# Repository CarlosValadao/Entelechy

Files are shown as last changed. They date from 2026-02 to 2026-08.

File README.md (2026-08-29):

# 🚀 Entelechy Project

https://github.com/user-attachments/assets/394cbacd-c1a7-4c5a-b76d-4e919793d7d3

O **Entelechy** é uma placa de propósito geral baseado na arquitetura **8051**.
Este projeto faz parte do meu portfólio de desenvolvimento em **Engenharia de Computação na UEFS** e minha trajetória na residência tecnológica do **CEPEDI**.

## 🛠️ Especificações de Hardware

### **Núcleo de Processamento**
* **MCU:** Atmel AT89S51 (Arquitetura 8051).
* **Interface de Programação:** Conector **ISP Prog** dedicado para gravação em circuito.

### **Sensores e Atuadores**
* **Display:** LCD 16x2 com interface **I2C** para visualização de dados em tempo real.
* **Temperatura/Humidade:** Sensor **DHT22** para medições de temperatura e umidade relativa.
* **Indicadores Visuais:** * LED **RGB** (Azul) e LEDS comuns (Laranja).
* **Feedback Sonoro:** Buzzer passivo para alertas via PWM.
* **HMI:** 4 Push-buttons e 8 Slide Switches.

### **Gerenciamento de Energia**
* **Proteção:** Circuito integrado contra **inversão de polaridade**.
* **Regulação:** Reguladores de tensão onboard com dissipadores para estabilidade térmica.

## Firmware

O firmware é um código de exemplo que demonstra o pleno funcionamento da placa

## 🎨 Design e Licença
* **Ferramenta:** KiCad
* **Dimensões:** 150 mm x 150 mm.
* **Licença:** CERN Open Hardware Licence Version 2 - Permissive (CERN-OHL-P).

---

## 👨‍💻 Autor
**Carlos Henrique de Oliveira Valadão**
* Graduando em Engenharia de Computação - **UEFS**.
* Residente em Sistemas Embarcados - **CEPEDI**.
* [LinkedIn](https://www.linkedin.com/in/carlos-valadao-3b81531bb/) | [GitHub](https://github.com/carlosvaladao)

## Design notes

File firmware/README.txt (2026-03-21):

                                Example
-----------------------------------------------------------------------------------
"C:\Users\baps\AppData\Local\Arduino15\packages\arduino\tools\avrdude\6.3.0-arduino17\bin\avrdude.exe" -C C:/AVR8051.conf -c stk500v1 -P COM61-p 89s52-b 19200 -U flash:w: "C:\Users\baps\OneDrive\Documents\8051\Keil 8051 Projects\LED\Objects\Single LED.hex":a

"C:\Users\baps\AppData\Local\Arduino15\packages\arduino\tools\avrdude\6.3.0-arduino17\bin\avrdude.exe" -C C:/AVR8051.conf -c stk500v1 -P COM6p 89s52-b 19200 -U flash:w: "C:\Users\baps\OneDrive\Desktop\Objects \testled.hex": a

-----------------------------------------------------------------------------------

-----------------------------------------------------------------------------------

"C:\Users\chval\AppData\Local\Arduino15\packages\arduino\tools\avrdude\6.3.0-arduino17\bin\avrdude.exe" -C C:/AVR8051.conf -c stk500v1 -P COM6 -p 89s51 -b 19200 -U flash:w:"C:\Users\baps\OneDrive\Documents\8051\Keil 8051 Projects\LED\Objects\Single LED.hex":a

"C:\Users\chval\AppData\Local\Arduino15\packages\arduino\tools\avrdude\8.0.0-arduino1\bin\avrdude.exe" -C C:/AVR8051.conf -c stk500v1 -P COM6 -p 89s51 -b 19200 -U flash:w:"C:\Users\chval\OneDrive\Desktop\uVision5 Projects\First Project\first-project.hex":a

C:\Users\chval\OneDrive\Desktop\uVision5 Projects\First Project

avrdude -C C:/AVR8051.conf -c stk500v1 -P COM9 -p 89s51 -b 19200 -U flash:w:"C:\Users\chval\OneDrive\Desktop\uVision5 Projects\First Project\Objects\first-project.hex":a

Criar os arquivos de cabeçalho para o DHT11 (AM23x) e para o 595 (SN74HC595)

-----------------------------------------------------------------------------------
Note: It support only AT89S51 and AT89S52.

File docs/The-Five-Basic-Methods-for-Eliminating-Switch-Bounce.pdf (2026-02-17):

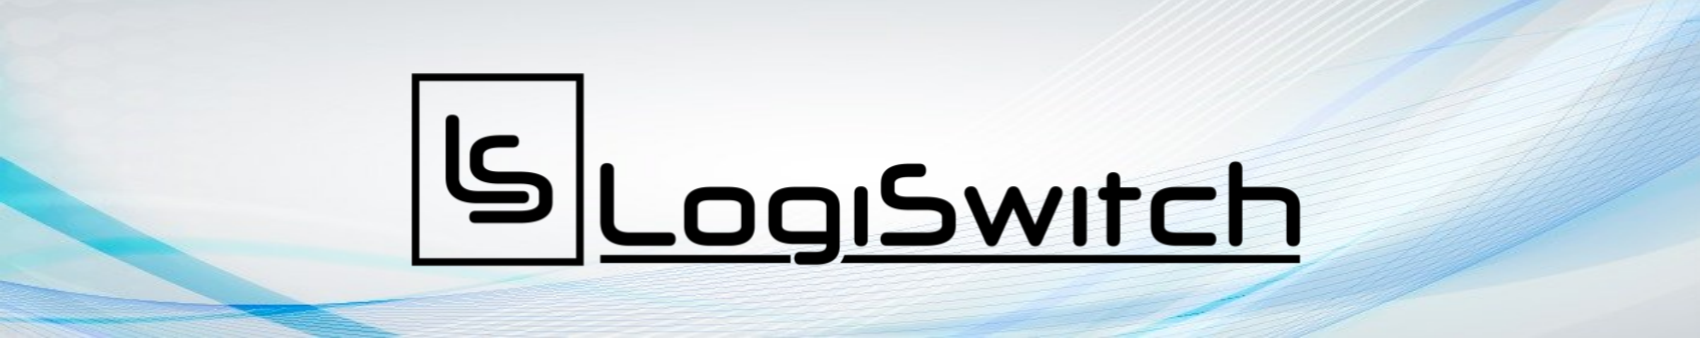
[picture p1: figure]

www.logiswitch.com | info@logiswitch.com | Sept 2020

# The Five Basic Methods for Eliminating Switch Bounce

By Michael H. Pelkey, Founder & CEO, LogiSwitch LLC

## Overview

This tutorial is to demonstrate all five methods for debouncing switches using single pole-single

throw, or single pole-double throw switches. The guide includes the two methods for single pole-

double throw (SPDT) switches which require no output delay and the two best methods for

interfacing with the simpler single pole-single throw (SPST) switches.

## What is Switch Bounce

The electric "snap switch" consists of one or two stationary electrodes called "Throws", and a

movable electrode, called a "Pole". When the switch is activated, the movable pole is forcefully

snapped onto the fixed surface of the stationary throw. Like snapping a rubber ball onto the

floor, it naturally bounces. The greater the force of the snap, the greater the bounce.

Unfortunately, the spring in the switch that provides the "snap" action through mechanical

hysteresis also adds to the force of the contacts coming together. If the switch is used to turn on

and off electric lights or to start a motor at 50 or 60 Hertz, the bounce is not noticeable and

causes no problems.

Unfortunately, such is not the case with high-speed, low current DC applications such as

microprocessor and microcontroller-based digital applications. Switch bounce is an inherent

characteristic of the electric switch, and almost always causes problems that must be dealt with

by the digital circuit designer. To make life easier for electronics design engineers and

2 | info@logiswitch.com | www.logiswitch.com

hobbyists, LogiSwitch manufactures switches and NoBounce+ ICs incorporating integral

debounce circuitry. It is the stated position of LogiSwitch that it is time for the field of digital

electronics to have their own switches that work for them rather than to continue borrowing from

the field for which they were originally designed that requires way too much extra effort just to

make them usable. LogiSwitch switches are made for high-speed digital applications.

## History of the Legacy Switch

Since the advent of the microprocessor and microcontrollers the propensity of the mechanical

switch to "bounce" has proved to be a design problem for hardware and/or software designers

that nearly always must be dealt with.

The Electric Snap Switch was designed and patented in 1884 by J. H. Holmes to ease the

arcing and burning of contacts for Thomas Edison's new invention of five years earlier, the

incandescent light bulb. It has been with us for the past 134 years, and still does a great job

when used for the purpose for which it was originally intended: high-voltage, high-current 50 and

60 Hertz AC applications.

## Debounce Tutorial

This tutorial demonstrates all five methods for debouncing switches, using single pole-single

throw, or single pole-double throw switches. The guide includes the two methods for single pole-

double throw (SPDT) switches which require no output delay:

1. The 2-Pin Debounce. This is the simplest method, but it requires two processor pins.
2. The Cross-coupled Nand or S/R Debounce. This method is functionally equivalent to

the 2-Pin method, but it uses only one processor pin.

and the two best methods for interfacing with the simpler single pole-single throw (SPST)

switches. Note that a delayed output is needed for the SPST switch:

1. Hardware SPST Debounce.
2. Software SPST Debounce.

Note that both the hardware and the software methods for debouncing the SPST switch simply

delay the switch output until after the bounce time has ended.

## Method 1. Simple Two-Pin Debounce

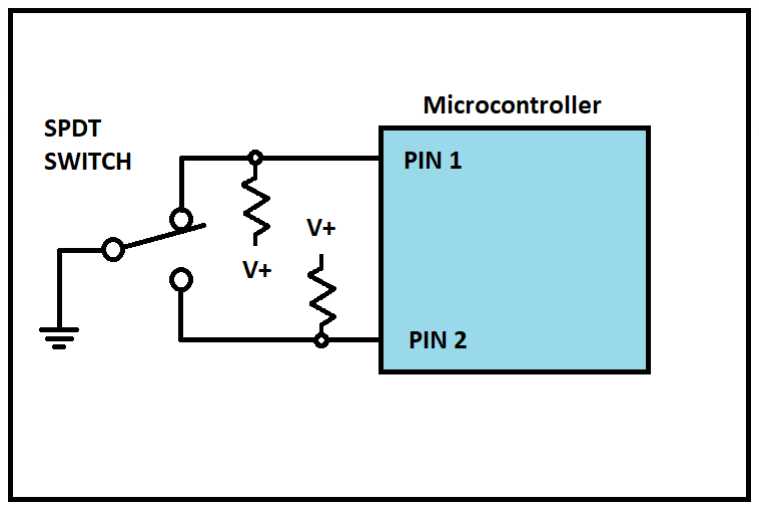
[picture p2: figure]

If you can spare two pins, this is the way to go. Using a SPDT switch, Pin 1 Low indicates the

switch is deactivated, and Pin 2 Low indicates it is activated. In other words, Switch Closure is

determined by finding Pin 2 low, and Switch Release is determined by finding Pin 1 low.

This rarely used, but highly effective debounce method performs every bit as well as the best

cross-coupled NAND circuit when two pins are available for use with a single switch. Note that

most microcontrollers provide programmable internal pull-up resistors for pins parameterized as

inputs, in which case the circuit may be even further simplified by omitting the two resistors

shown in the circuit drawing

## Method 2: Cross-Coupled NAND Debounce

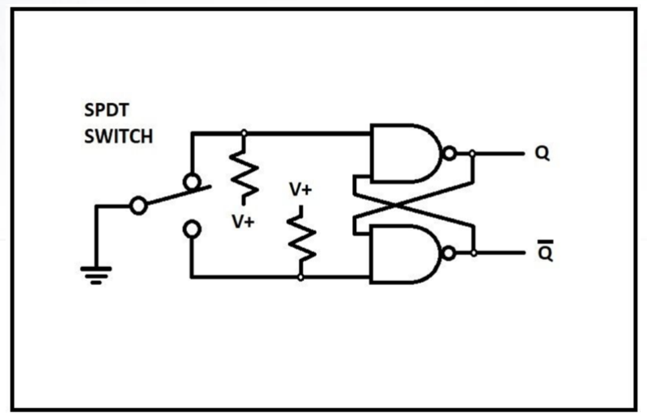
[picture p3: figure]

The cross-coupled NAND gate method is ideal for projects where two processor pins are not

available for use with one switch.

Output Q is high when the switch is idle, and low when it is activated. The /Q output is the

opposite: low when idle and high when activated. Note that only Methods 1, Two-Pin Debounce,

Method 2, Cross-coupled Nand Debounce or Method 3, D-Type Flip Flop Debounce provide

immediate outputs with no delay on activation and release (see Waveform 1).

For some industrial automation and robotics applications, the immediate attention of signaling

from these debounce methods is needed.

Note that the LogiSwitch integral debounce switches or LS100 series debouncer ICs incorporate

a circuit like the circuitry of Method 2.

## Method 3: D-Type Flip-Flop Debounce

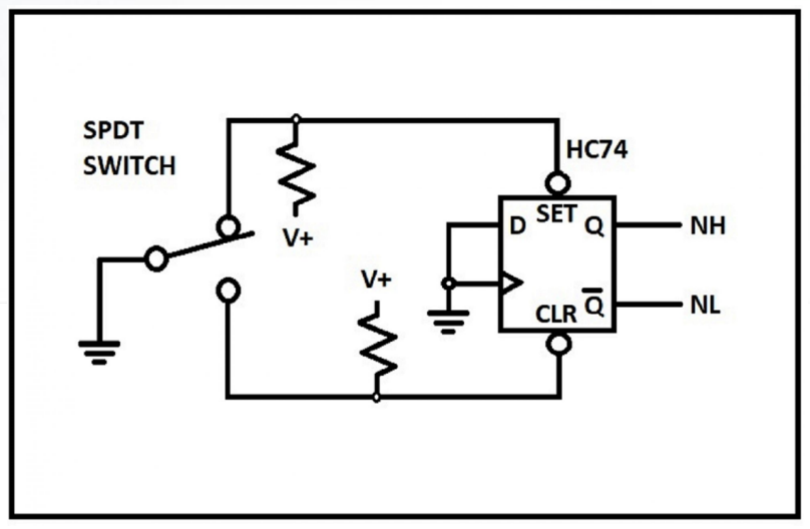
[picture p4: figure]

Using the internal cross-coupled NAND gating of a D-Type Flip flop provides an excellent

Method 3 Debounce. Note the Q output is normally high and goes low when the switch is

activated.

## Method 4: Hardware Debounce for SPST Switches

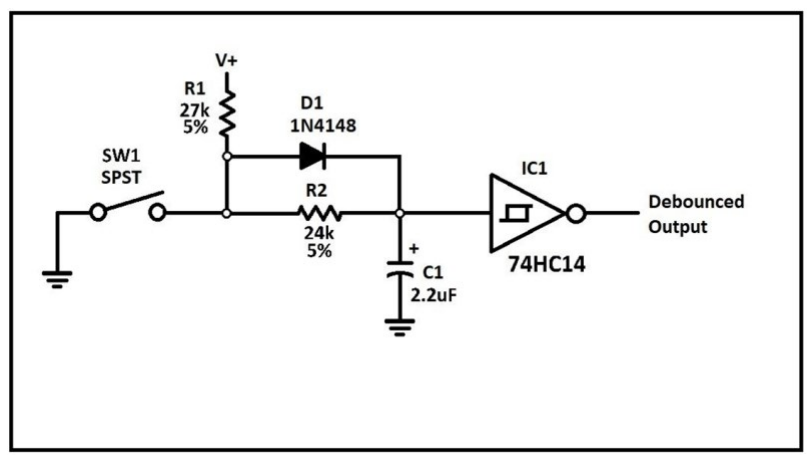
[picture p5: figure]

Whenever a single pole-single throw (SPST) switch is used for input into high-speed digital

devices, the only thing you can do is to wait out the bounce interval with either hardware or

software delays (see Waveform 2). The individual application dictates the usefulness of this

debounce method. Most applications can handle delays of up to 100 ms with a barely noticeable

delay. Method 4 is the hardware implementation for single poll-single throw switches.

This circuit charges the capacitor C1 through Resistor R1 and Diode D1 when the switch is

released and discharges it through Resistor R2 when it is activated. The 74HC14 Schmitt trigger

provides the needed hysteresis for a snap-action output when the slow ramp of the RC circuit

rises and falls. Hysteresis assures a single transition with no oscillation when the switch is

activated or released.

NOTE: The values shown in the drawing provide delays of approximately 36 ms on activation

and release with a 5 Volt supply. The resistance of R1 and R2 may be raised or lowered for

longer or shorter delay times.

Using a 2.2 µF Capacitor for C1, a very simple way to calculate the delay time for the circuit

shown is R1 = T * 750, and R2 = R1 * 0.9

where T is the desired delay time in milliseconds, and R1 & R2 are resistance in ohms:

For 100 ms delay:

R1 = 100 * 750 | R1 = 75,000 ohms
R2 = R1 * 0.9 | R2 = 75,000 * 0.9 | R2 = 67,500 ohms
R1 = 20 * 750 | R1 = 15,000 ohms
R2 = R1 * 0.9 | R2 = 15,000 * 0.9 | R2 = 13,500 ohms

For 20ms delay:

## Method 5: Software Delay Debounce

There are numerous examples online for software debounce routines for every computer

language known to mankind. They all amount to simply waiting out the estimated bounce period.

For Switch Activated:

1. Loop until switch activated.
2. Delay 20 ms to 100 ms.
3. Retest to be sure it is still activated. (If not, go to 1)
4. Continue with the program. Switch is activated.

For Switch Released:

1. Loop until switch released.
2. Delay 20 ms to 100 ms.
3. Retest to be sure it is still released. (If not, go to 1)
4. Continue with the program. Switch is released.

You must provide a longer delay period than any switch you use will ever bounce. Contact

bounce time varies among switch types and even among switches of the same type and

models. Delay time also is said to change over time with the same switch. Typical delay times

used are 20 ms to 100 ms, even when the actual bounce time may be as little as a few

milliseconds.

For compute-bound applications where time is literally of the essence, such as in high-speed

automated industrial machinery or robotics applications, your choice of debounce method

should be Method 1: Two-Pin Debounce, or Method 2: Cross-Coupled Nand Debounce.

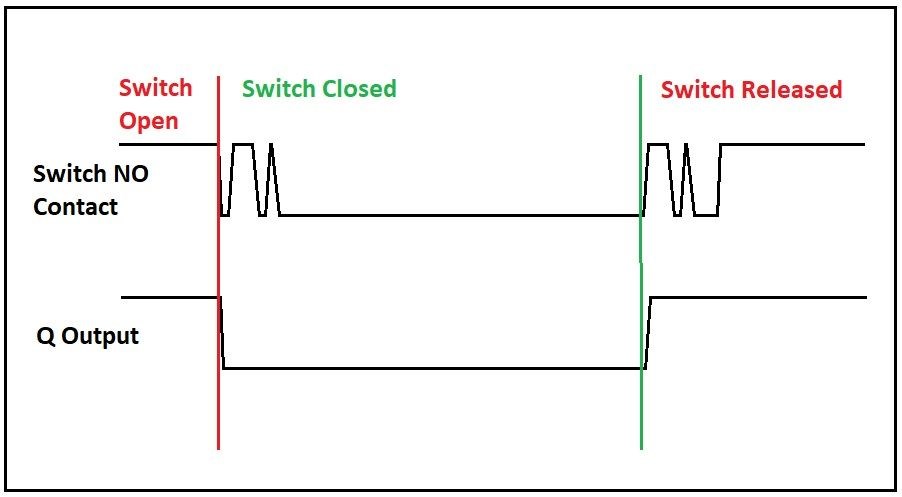
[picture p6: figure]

## Waveform 1. Cross-Coupled Nand and 2-Pin Debounce Methods

Note the immediate Q output. Methods 1 and 2 change the output state with no delay both on

actuation and release.

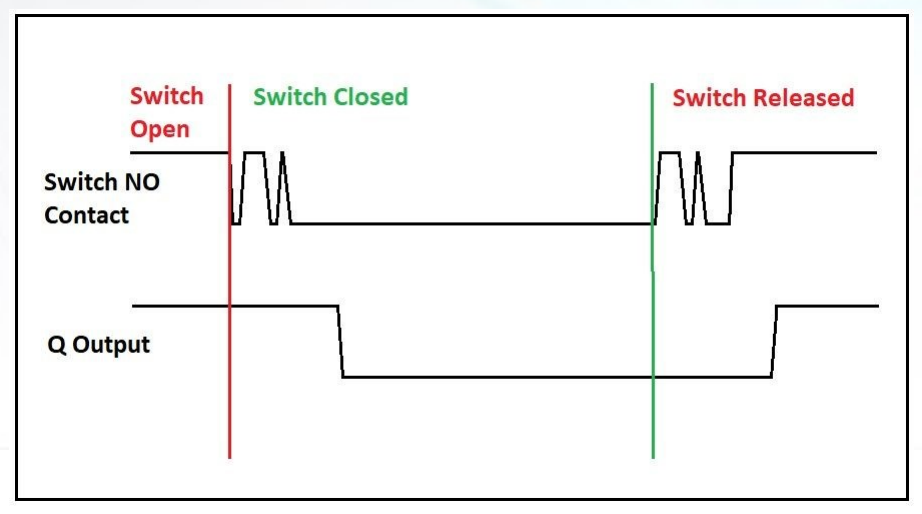
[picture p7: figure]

## Waveform 2. SPST and Software Delay Methods

Note the delayed Q output for these methods. The Hardware Debounce circuit of Method 3 and

Software Debounce of Method 4 require delaying action until the bounce time is through.

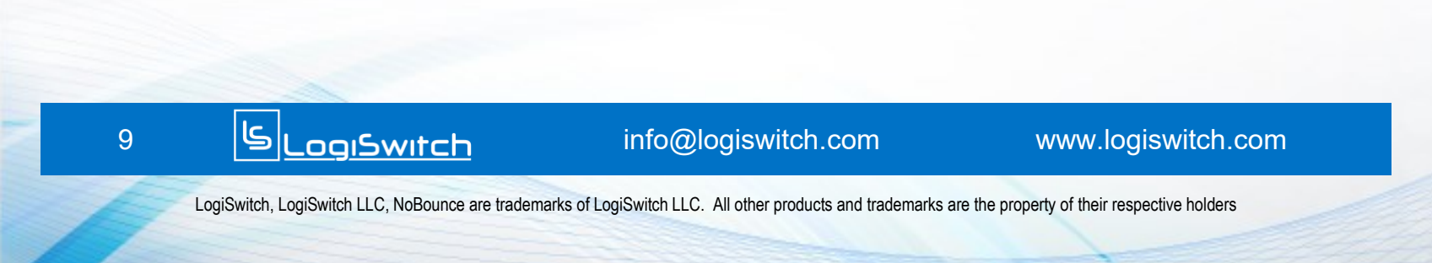
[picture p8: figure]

LogiSwitch, LogiSwitch LLC, NoBounce are trademarks of LogiSwitch LLC. All other products and trademarks are the property of their respective holders

About the Author

Michael H. Pelkey, Founder and CEO, LogiSwitch LLC

Mike is a serial inventor and serial entrepreneur who has a broad background in designing,

using, and manufacturing electronic systems and equipment. In his younger years, Mike

pioneered the sport of BASE Jumping. (https://en.wikipedia.org/wiki/Michael_Pelkey)

Prior to founding LogiSwitch, Mike was an Automation Engineer at Jaxx Manufacturing where

he designed and built assembly and metalworking machines to increase production rates, such

as automatic screwdrivers, optical cut to length machines, and a variety of machines, jigs and

fixtures to automate printed circuit assembly operations.

Mike’s 40+ year career goes back to the early days of the microprocessor where he was the

lead engineer for the first microprocessor-based product in the numerical control industry a Z-

axis controller called the Micro-Z. Mike also developed the world’s first networked cash register

in the mid-1970s, and he founded Macrotech International Corporation, which was a major

manufacturer of board-level computer products in the late-1970s and early-1980s.

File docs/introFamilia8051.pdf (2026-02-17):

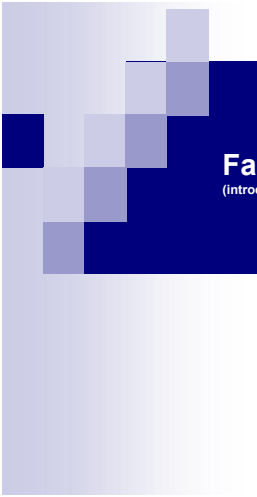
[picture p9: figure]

# Família 8051

(introdução)

2011/1

2

# Refresh

Microprocessador vs. microcontrolador. Periféricos built-in.

## Single-chip computer

3

# Objetivos

Histórico
Modelos da família original
Principais características
Diagrama em blocos simplificado
Configuração e descrição dos pinos (pinagem) Arquitetura
Multiplexação de dados e endereços
I/O mapeado em memória
Organização de memória
Timing
Interrupções
T/C e porta serial
Instruction set
Modelos atuais
Atividades

### Intrudução à família de microcontroladores 8051:

4

# Rápido histórico

Desenvolvido pela Intel
Nome oficial: MCS-51
Introduzida no final da década de 70/ início de 80.
Principal finalidade: automação e controle.

# Principais modelos da família original

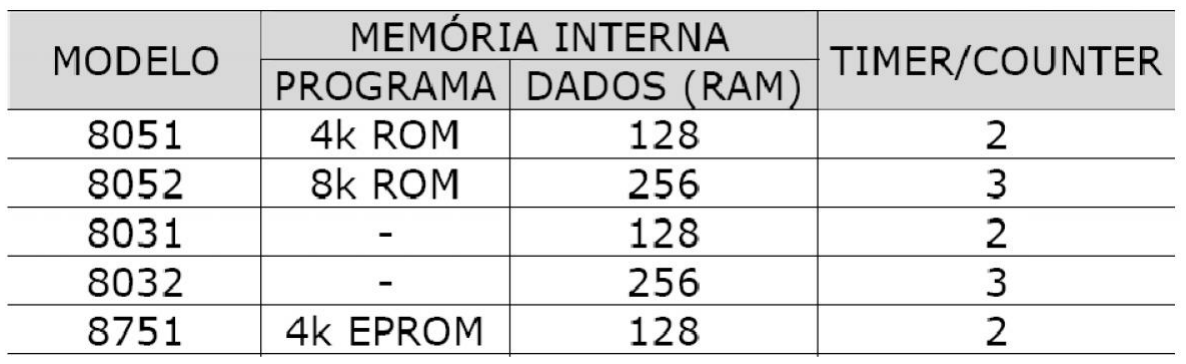
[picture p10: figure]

5

# Principais características do 8051

8 bits
4 ports bidirecionais de 8 bits (P0, P1, P2, P3)
128 bytes de RAM interna
4 Kbytes de memória de programa ROM OTP
Endereçamento de até 64 Kbytes de memória de dados externa
Endereçamento de até 64 Kbytes de memória de programa externa Oscilador de clock
2 timers/counters (T/C) de 16 bits
Uma porta serial USART
5 fontes de interrupção (2 externas, 2 T/C, 1 serial)

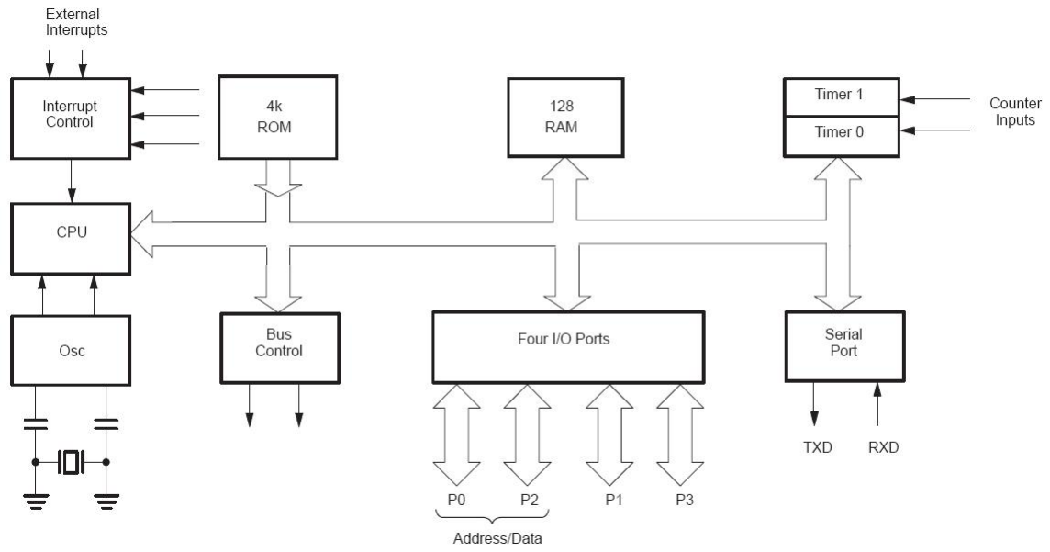
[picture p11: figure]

6

# Diagrama em blocos simplificado

# Configuração e descrição dos pinos

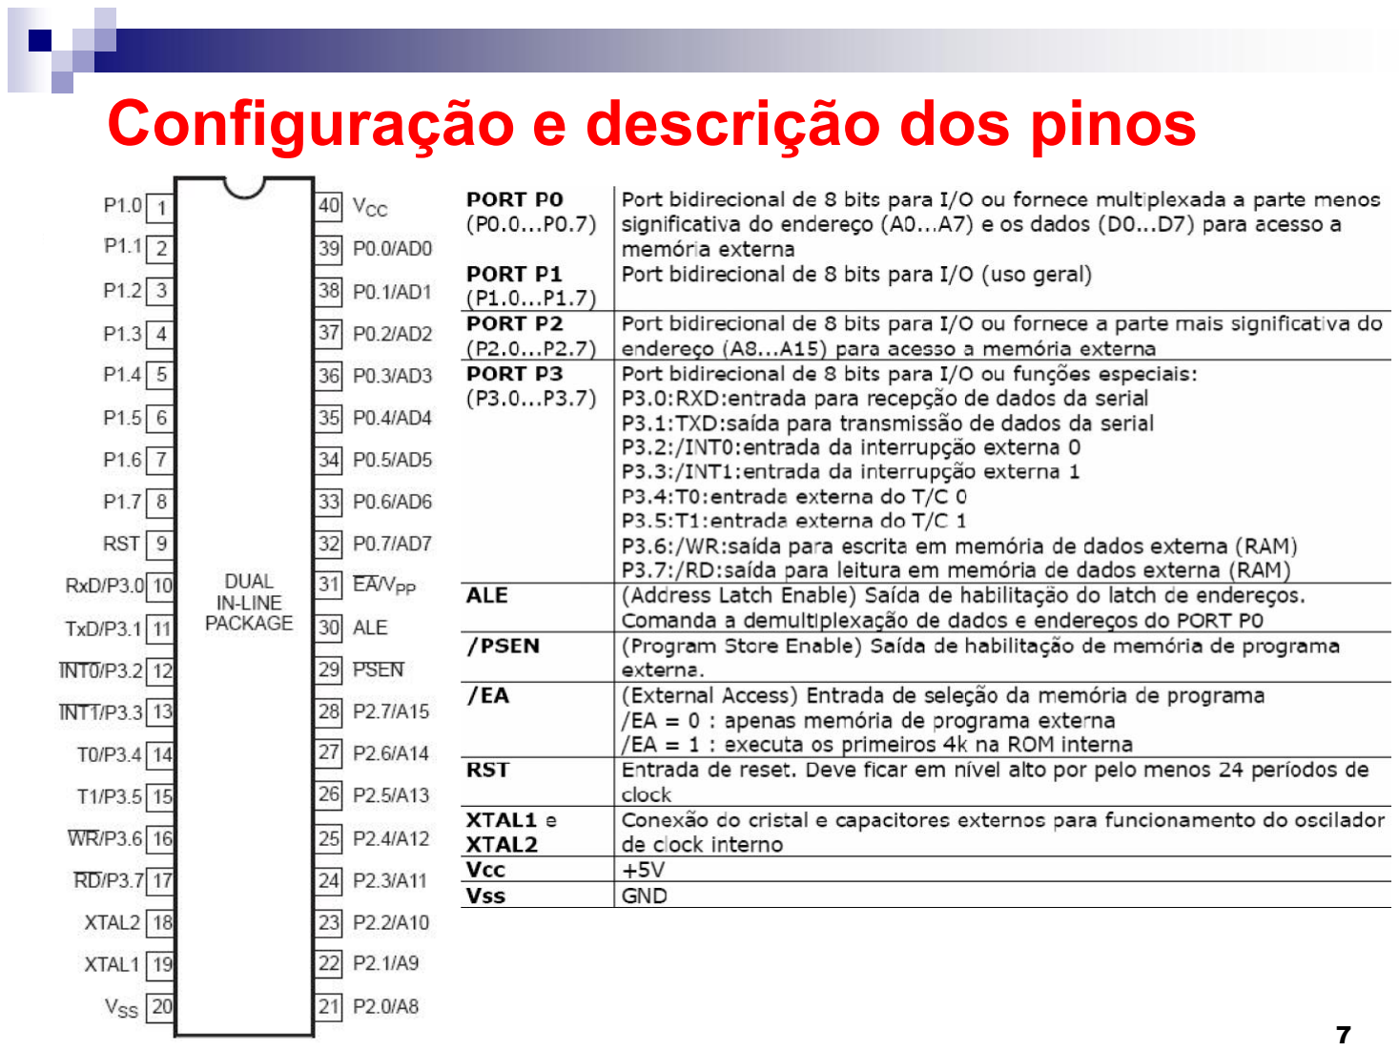
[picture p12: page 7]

7

## Arquitetura Multiplexação de dados e endereços

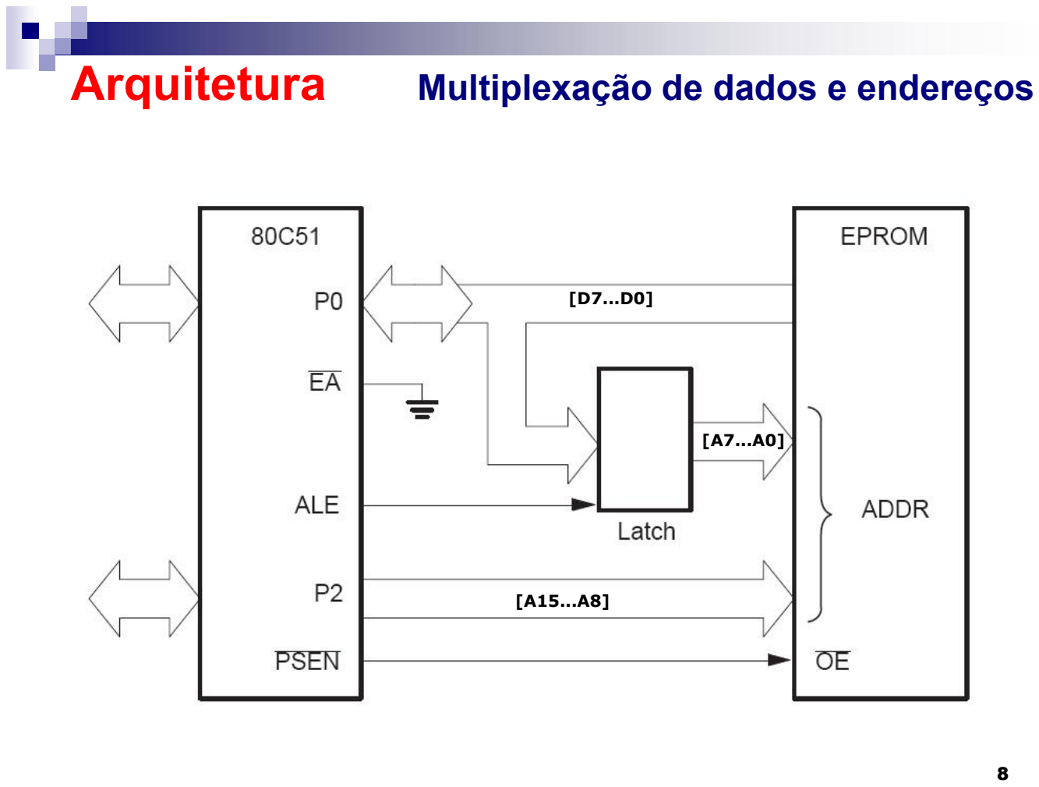
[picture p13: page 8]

8

[D7...D0]

[A15...A8]

[A7...A0]

## Arquitetura Multiplexação de dados e endereços

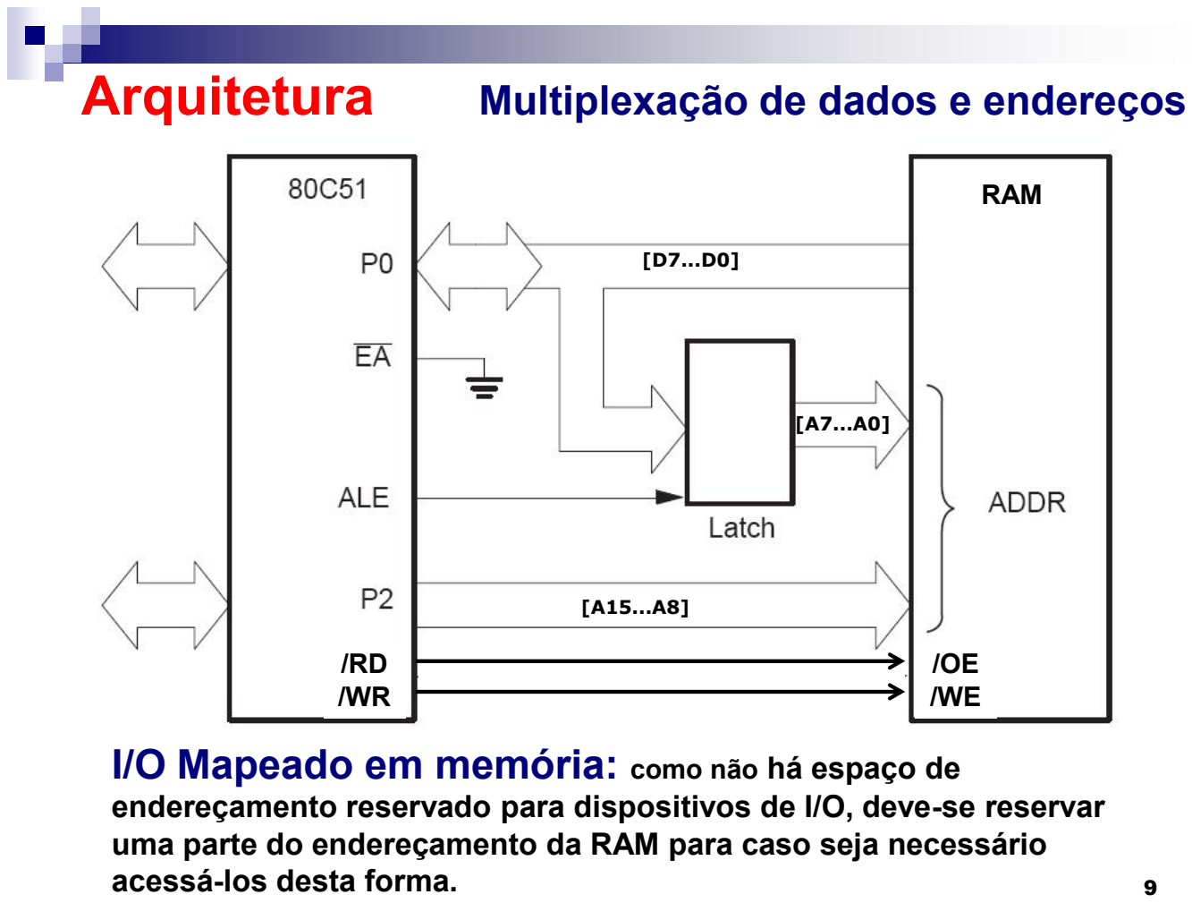
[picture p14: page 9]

9

RAM

/RD
/WR

/OE
/WE

## I/O Mapeado em memória: como não há espaço de

endereçamento reservado para dispositivos de I/O, deve-se reservar uma parte do endereçamento da RAM para caso seja necessário acessá-los desta forma.

[D7...D0]

[A15...A8]

[A7...A0]

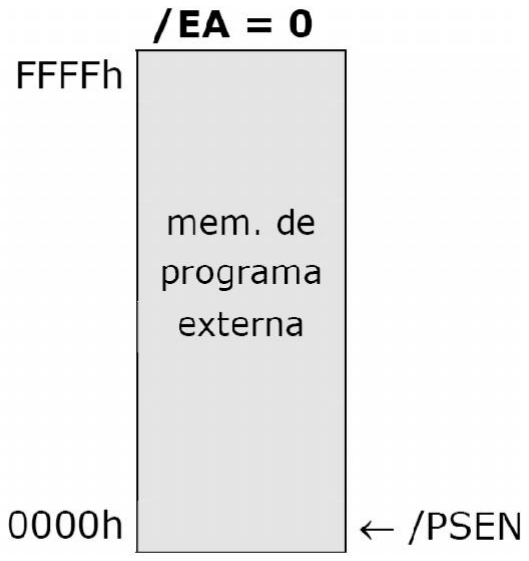
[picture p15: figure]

10

## Arquitetura Organização de memória

Memória de programa:

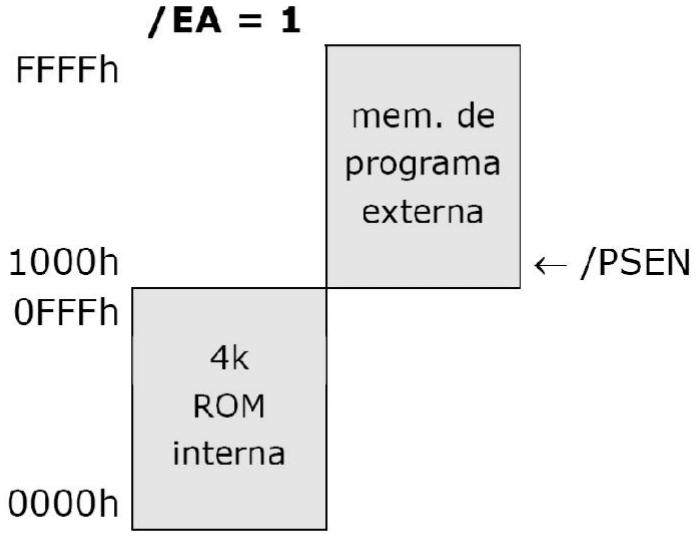
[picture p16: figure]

## Arquitetura Organização da memória

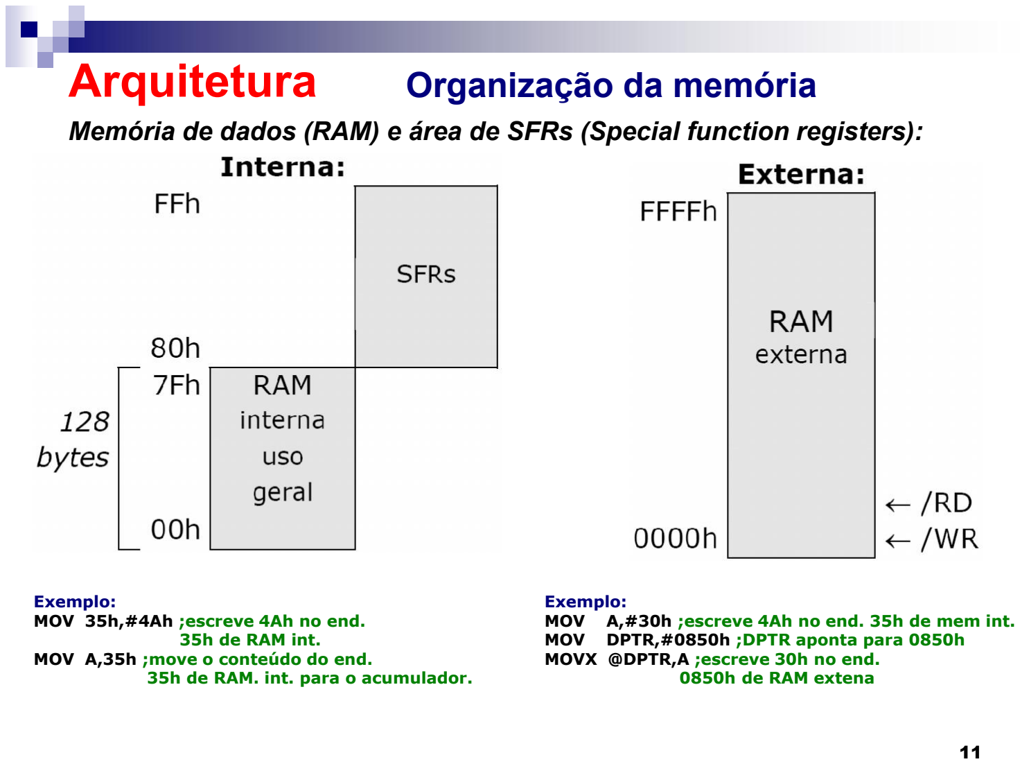
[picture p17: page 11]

11

Memória de dados (RAM) e área de SFRs (Special function registers):

Exemplo:
MOV 35h,#4Ah ;escreve 4Ah no end. 35h de RAM int.
MOV A,35h ;move o conteúdo do end. 35h de RAM. int. para o acumulador.

Exemplo:
MOV A,#30h ;escreve 4Ah no end. 35h de mem int. MOV DPTR,#0850h ;DPTR aponta para 0850h MOVX @DPTR,A ;escreve 30h no end.
0850h de RAM extena

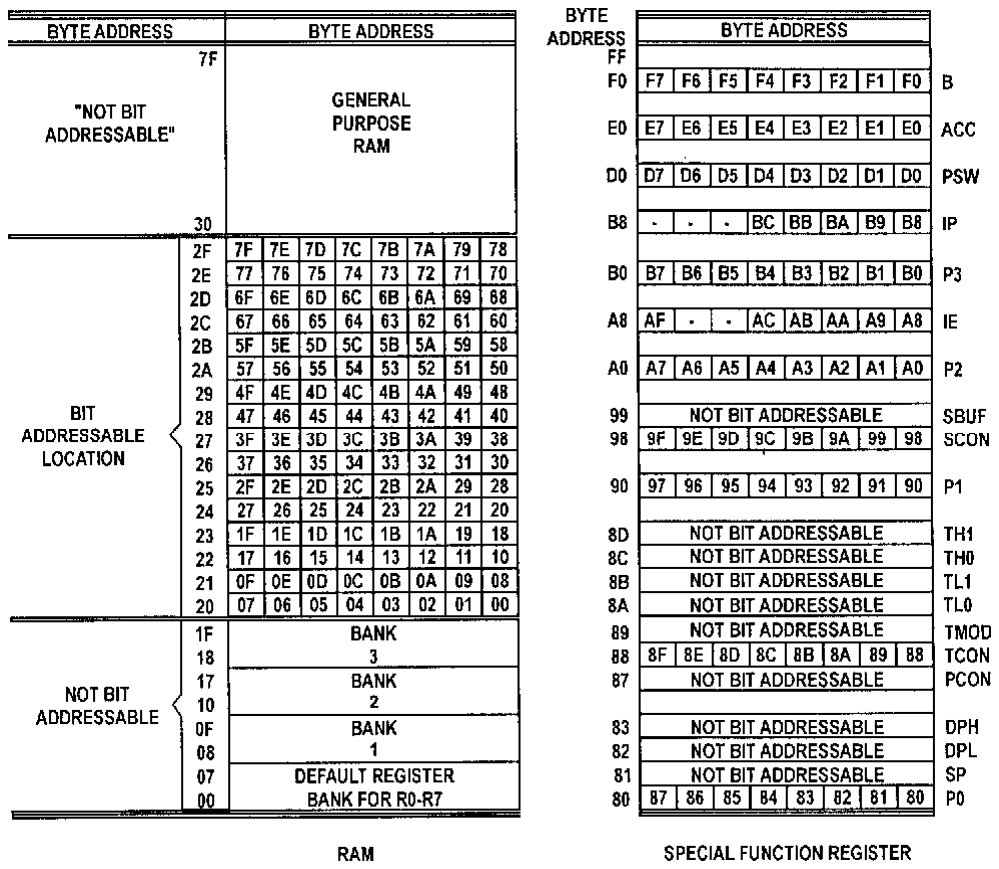
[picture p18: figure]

12

## Arquitetura Organização da memória

Memória de dados (RAM) e área de SFRs (Special function registers):

Microcontrolador
8051 Detalhado
Denys E. C. Nicolosi,
Editora Érica, 2a Ed.

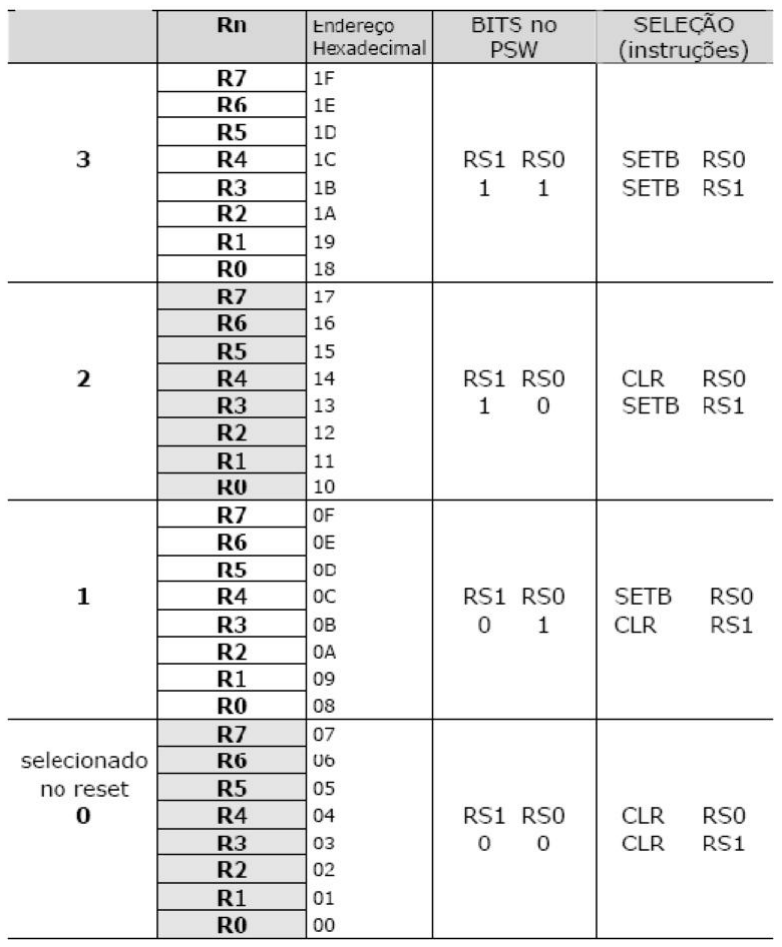
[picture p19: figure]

13

## Arquitetura Organização da memória

Bancos de registradores
- Situados nas posições
00h até 1Fh de RAM
Interna.
-A seleção do banco
(0,1,2,3) é feita através
Dos bits RS1 e RS0 do
SFR PSW:

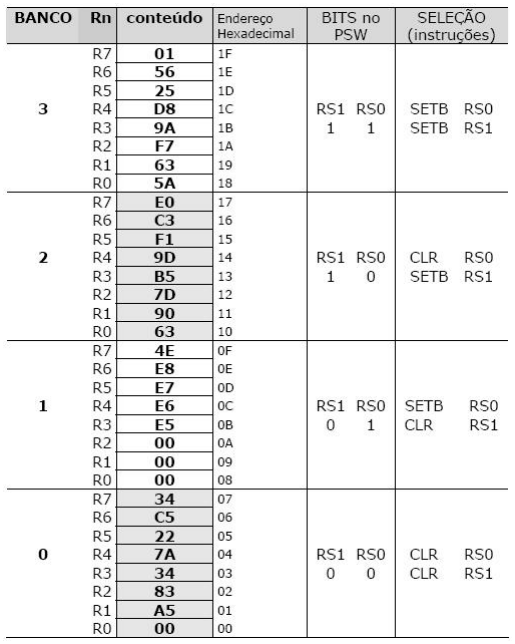
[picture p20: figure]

14

## Arquitetura Organização da memória

Bancos de registradores

Exemplo:
Após as instruções
CLR RS0
SETB RS1
MOV A,R5
Qual é o conteúdo de A ?

Resposta: A F1h

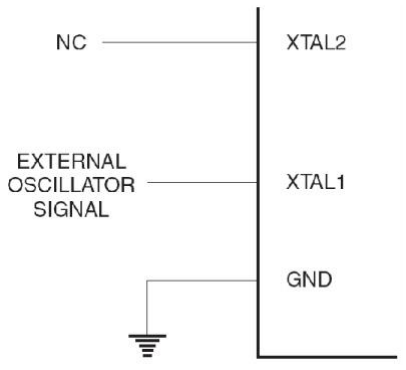
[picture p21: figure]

15

# Timing

Oscilador interno. Requisita a conexão de um cristal e capacitores. Também pode-se aplicar clock externo. Tipicamente:

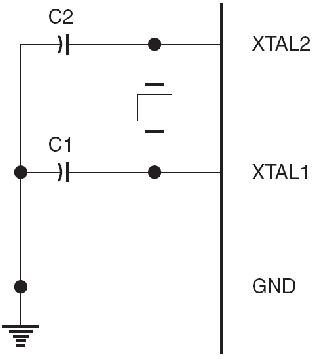
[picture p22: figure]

Ativo em nível lógico alto. Deve permanecer pelo menos 2 ciclos de

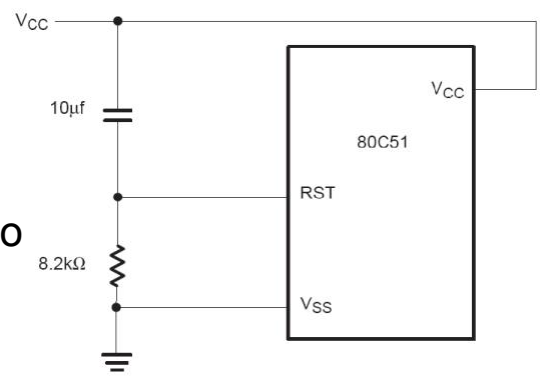
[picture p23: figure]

máquina ativo, permitindo a estabilização do oscilador interno. Tipicamente:

## Reset

## Clock

C1 = C2 33 pF
Cristal
11.059200 MHz

## Ciclos de máquina

Um ciclo de máquina consiste De 12 períodos de clock. As instruções requerem 1 ou 2 ciclos.

# Interrupções

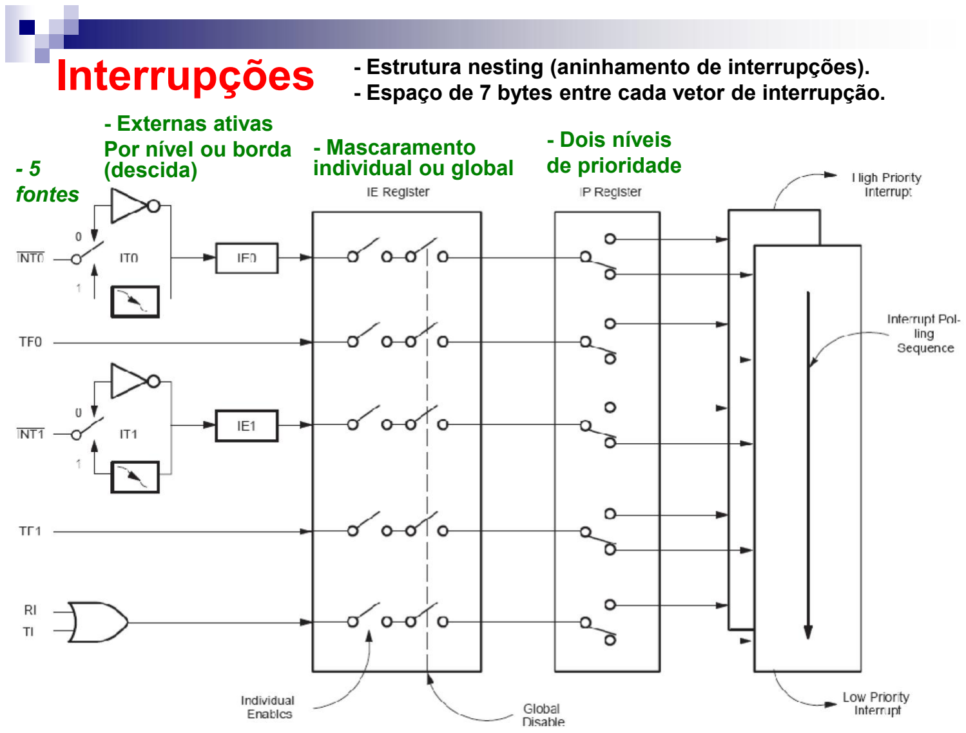
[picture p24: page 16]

16

- 5
fontes
- Mascaramento
individual ou global
- Externas ativas
Por nível ou borda
(descida)
- Dois níveis
de prioridade
- Estrutura nesting (aninhamento de interrupções).
- Espaço de 7 bytes entre cada vetor de interrupção.

17

# Timer/Counter (T/C)

2 T/C: T/C 0 e T/C 1.
A contagem acontece nos registradores TLx e THx.
Operação como timer: incremento em TLx/THx ocorre a uma frequencia de 1/12 da frequencia do clock.
Operação como counter: incremento em TLx/THx ocorre na borda de descida do pino Tx.
4 modos de operação:



18

# Porta serial

Pinos TXD e RXD.
Permite operação full-duplex e possui um buffer de recepção.
Transmissão e recepção dos dados acontecem no registrador SBUF: São dois buffers fisicamente independentes.
Escrita em SBUF: carrega os dados a serem transmitidos.
Leitura em SBUF: recebe os dados.
4 modos de operação:

19

# Instruction set

ISA (instruction set architecture) CISC.
Aproximadamente 100 instruções. Podem ser divididas nos cinco grupos descritos abaixo

### 2. Lógicas

Exemplos:
ANL
ORL
XRL
CPL
SWAP
RL
RR

### 1. Aritméticas

Exemplos:
ADD
INC
SUB
DIV
MUL

### 3. Transferência

de dados
Exemplos:
MOV
MOVC
MOVX
PUSH
POP

### 4. Salto e salto

incondicional
Exemplos:
AJMP
LJMP
SJMP
CJNE
DJNZ
NOP
JZ
JNZ

### 5. Manipulação

de variáveis
booleanas
(bit-level)
Exemplos:
CLR
SETB
CLP
ANL
ORL
MOV

20

# Modelos atuais

A Intel não produz mais a família 8051 original. Na linha de embarcados, dedica-se a dispositivos mais sofisticados.
O 8051 ainda é um dos cores de 8 bits mais populares do mercado. Há 8051 de todos os sabores e para todos os gostos !
Periféricos built-in.
Desempenho.
Encapsulamentos.
Consumo.
Tensão de operação.
Exemplos de fabricantes e respectivos destaques:
NXP (Philips) | grande variedade de periféricos built-in
Atmel | linha AT89S com memória de programa flash
Dallas (Maxim) | alto desempenho (até 50 MHz, 50 MIPS)
Infineon (Siemens) grande variedade de periféricos built-in
Texas Instruments aquisição de sinal
Cypress | controlador USB com 8051
Nuvoton | alto desempenho (2,5 x faster)

21

# Atividades

Procurar datasheets da 8051 family utilizando as seguintes palavras chave:
Family architecture
Hardware description
Programmers guide ou instruction set

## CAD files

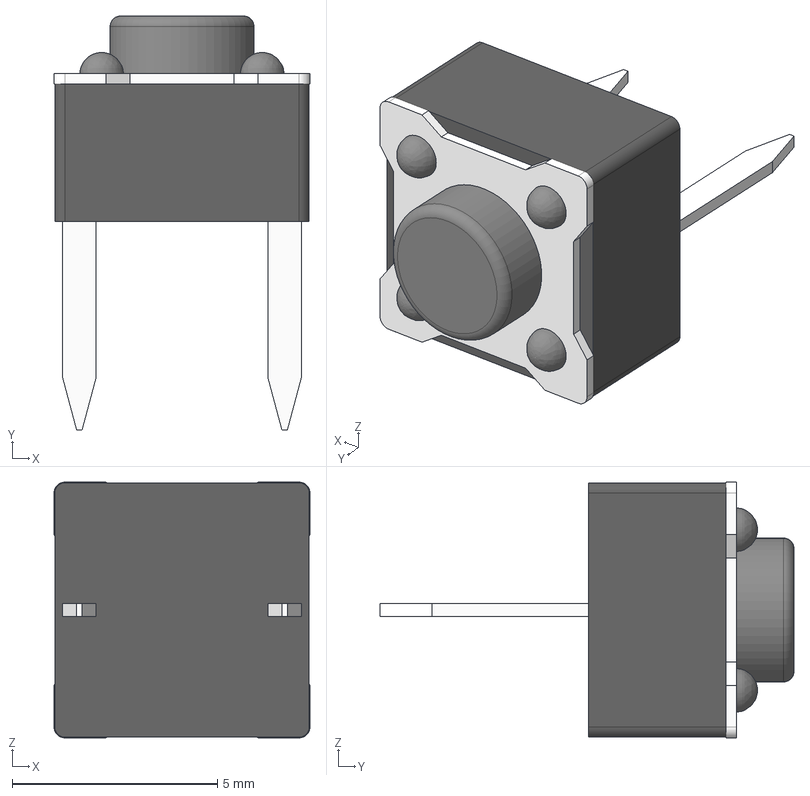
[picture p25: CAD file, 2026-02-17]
Entelechy/Entelechy_3D/Tactile Switches TH (6mm×6mm -2pin) Black.stp
6.23 x 10.1 x 6.23 mm

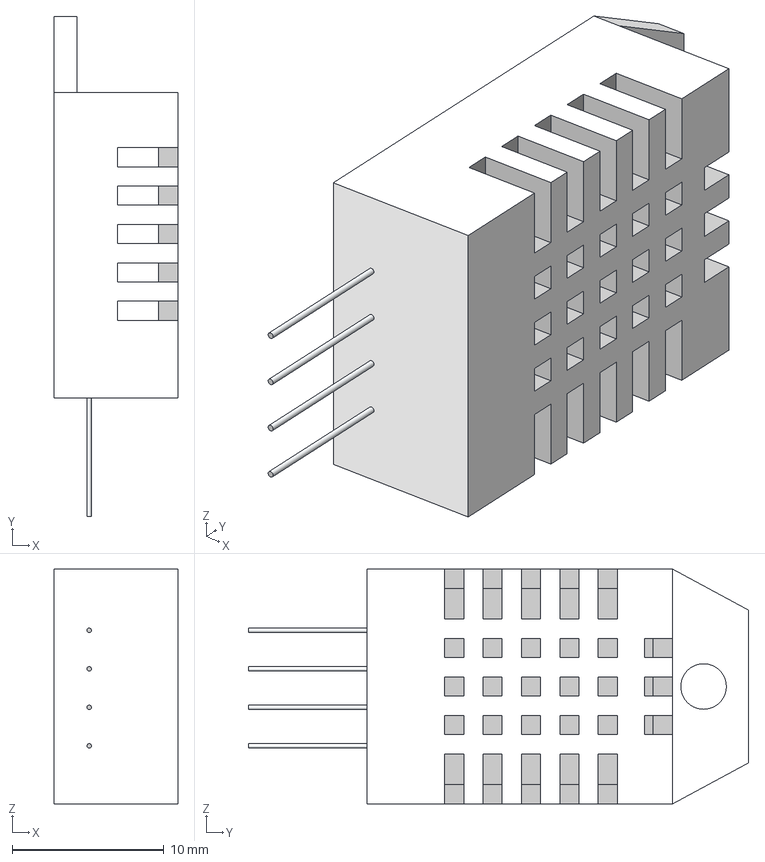
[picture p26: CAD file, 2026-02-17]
Entelechy/Entelechy_3D/DHT22 v1.step
8.15 x 33.0 x 15.5 mm

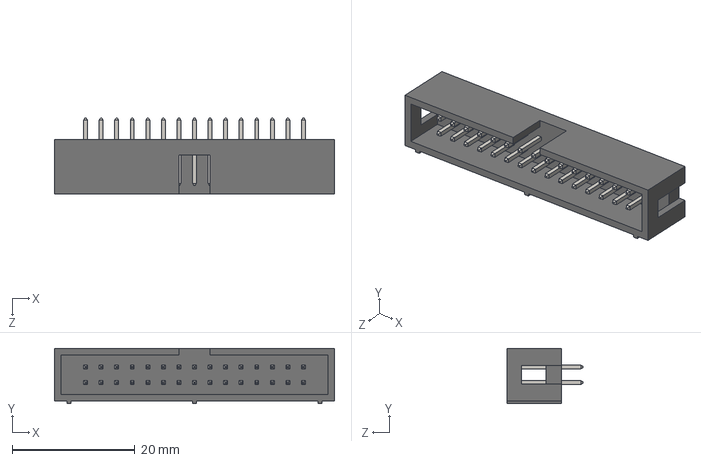
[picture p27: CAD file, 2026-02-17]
Entelechy/Entelechy_3D/BH-30.STEP
45.7 x 9.00 x 12.4 mm

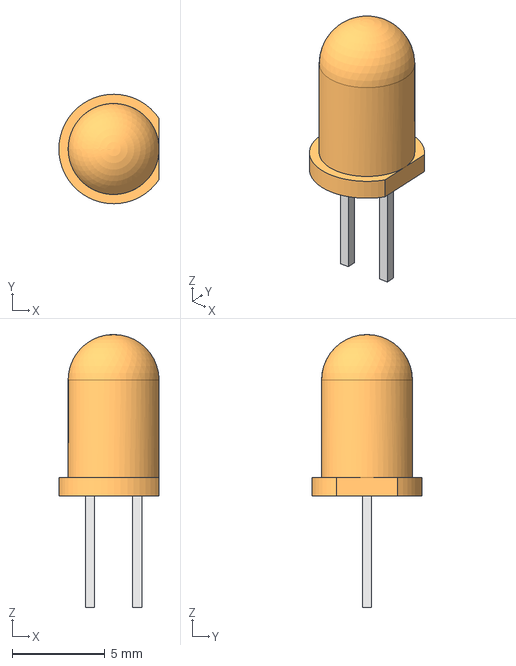
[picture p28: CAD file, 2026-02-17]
Entelechy/Entelechy_3D/LED_D5.0mm_ORANGE.step
5.40 x 5.90 x 14.7 mm

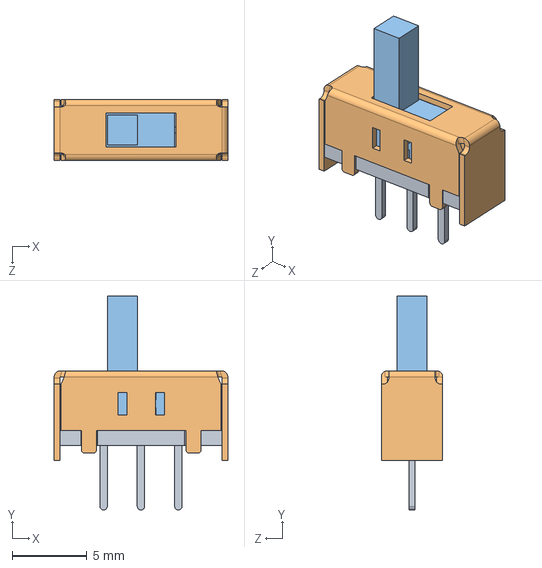
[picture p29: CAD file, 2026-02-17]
Entelechy/Entelechy_3D/SLW-116641-5A-S-D.step
11.6 x 14.3 x 4.10 mm

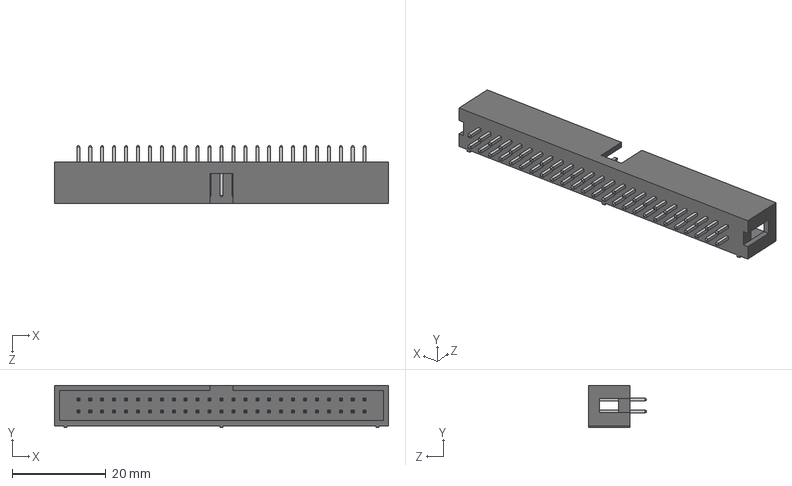
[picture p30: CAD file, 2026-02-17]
Entelechy/Entelechy_3D/BH-50.STEP
71.1 x 9.00 x 12.4 mm

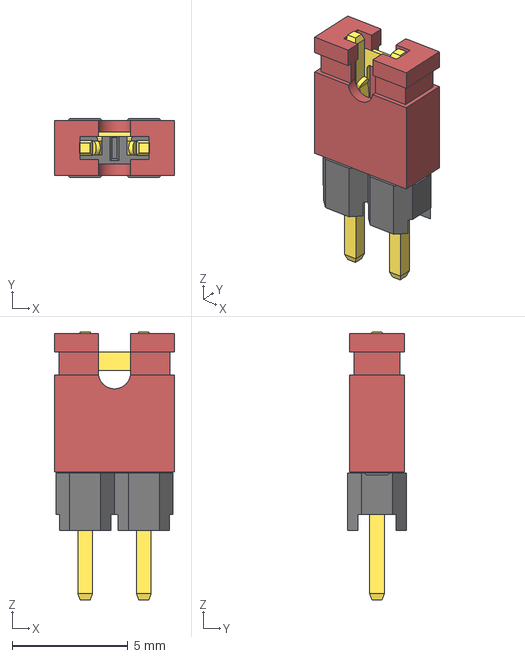
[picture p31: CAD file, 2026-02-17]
Entelechy/Entelechy_3D/Jumper2-red.step
5.20 x 2.54 x 11.6 mm

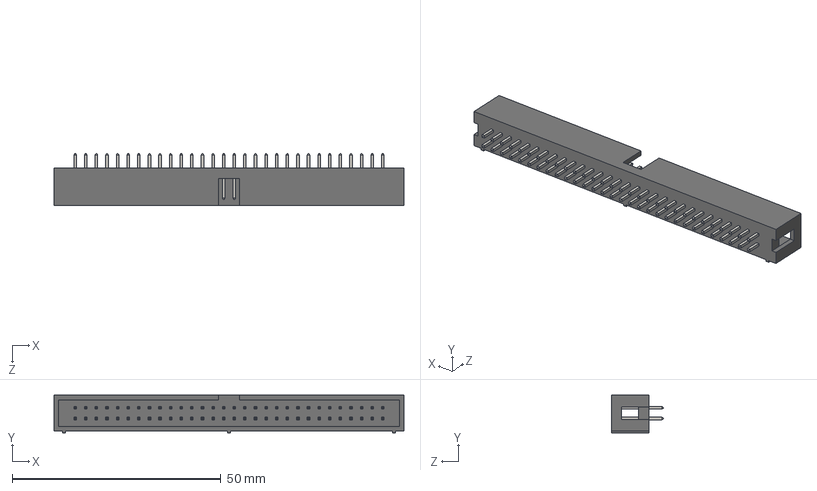
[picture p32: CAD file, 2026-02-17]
Entelechy/Entelechy_3D/BH-60.STEP
83.8 x 9.00 x 12.4 mm

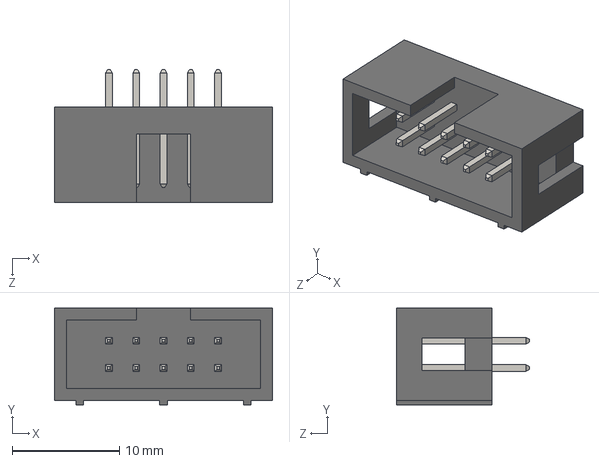
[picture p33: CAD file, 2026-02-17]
Entelechy/Entelechy_3D/BH-10.STEP
20.3 x 9.00 x 12.4 mm

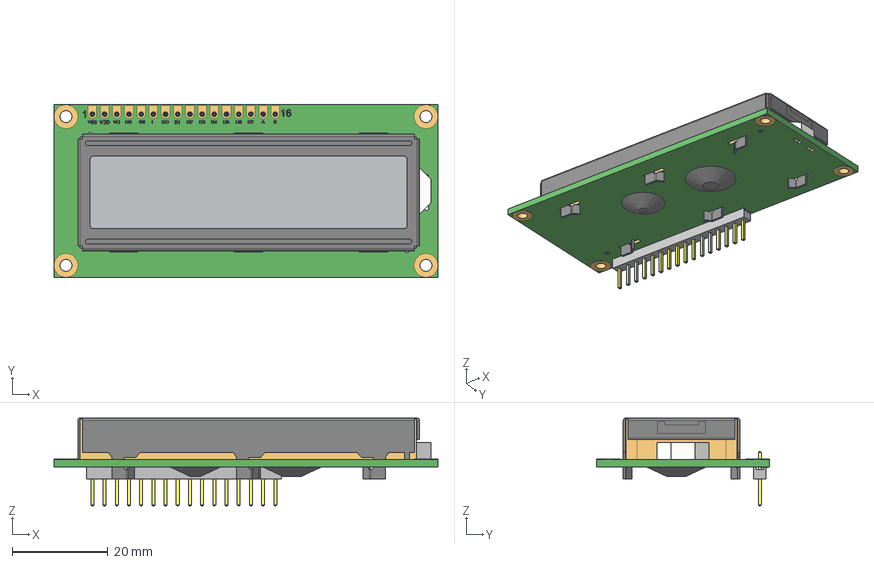
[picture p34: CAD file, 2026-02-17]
Entelechy/Entelechy_3D/LCD 16 x 2 v1.step
80.0 x 36.0 x 18.3 mm
Slikscreen
PCB
LCD
Frame
ZW-16-16-G-S-200-125bbody
Conn1x16_Pins

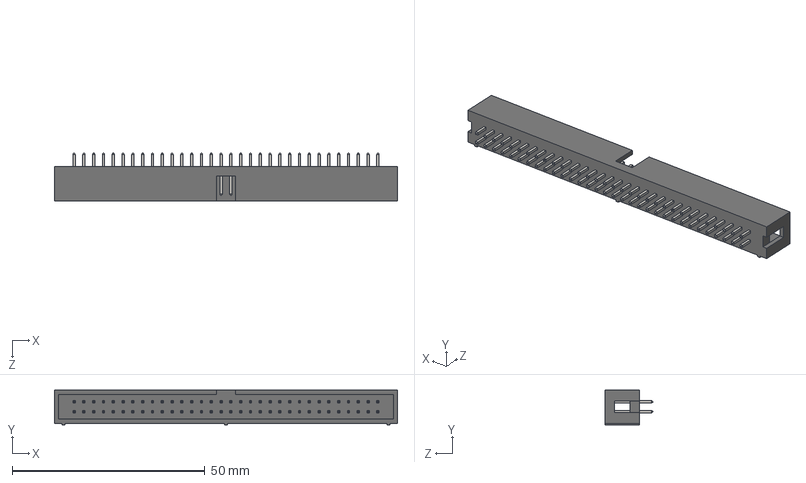
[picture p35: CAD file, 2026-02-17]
Entelechy/Entelechy_3D/BH-64.STEP
88.9 x 9.00 x 12.4 mm

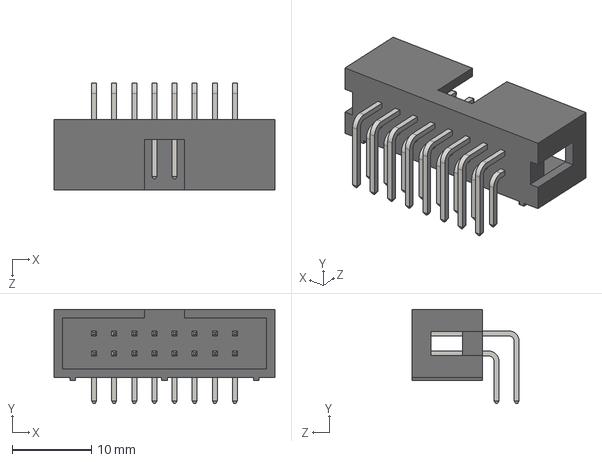
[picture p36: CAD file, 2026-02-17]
Entelechy/Entelechy_3D/BH-16R.STEP
27.9 x 11.9 x 13.6 mm

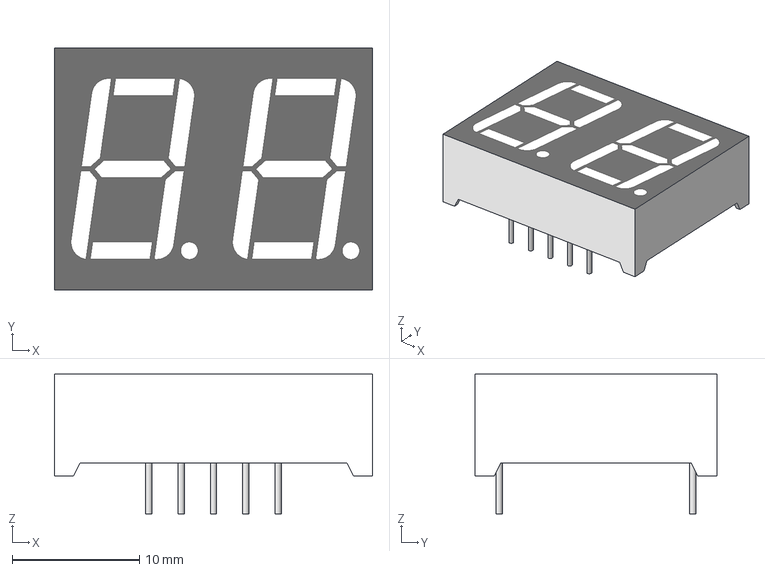
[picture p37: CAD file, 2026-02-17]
Entelechy/Entelechy_3D/display-5261-body.step
25.0 x 19.0 x 11.0 mm

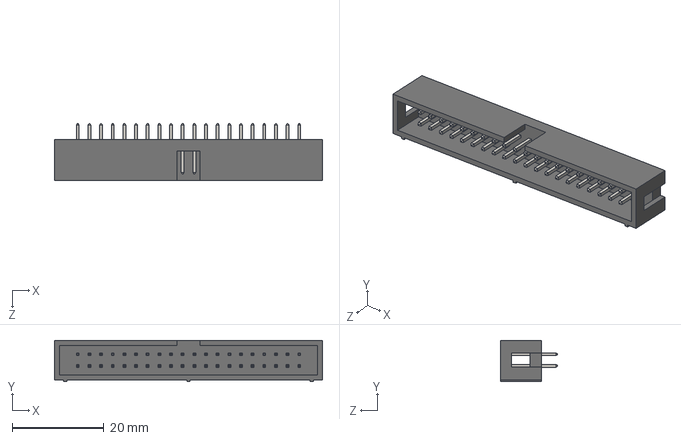
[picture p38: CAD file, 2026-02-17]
Entelechy/Entelechy_3D/BH-40.STEP
58.4 x 9.00 x 12.4 mm

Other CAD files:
entelechy_board_outline.FCStd
Entelechy/Entelechy_3D/LED_D5.0mm_BLUE.step
Entelechy/Entelechy_3D/Jumper2-green.step
Entelechy/Entelechy_3D/LED_D5.0mm_GREEN.step
Entelechy/Entelechy_3D/BH-10R.STEP
Entelechy/Entelechy_3D/BH-12.STEP
Entelechy/Entelechy_3D/BH-12R.STEP
Entelechy/Entelechy_3D/BH-14.STEP
Entelechy/Entelechy_3D/BH-14R.STEP
Entelechy/Entelechy_3D/BH-16.STEP
Entelechy/Entelechy_3D/BH-20.STEP
Entelechy/Entelechy_3D/BH-20R.STEP
Entelechy/Entelechy_3D/BH-26.STEP
Entelechy/Entelechy_3D/BH-26R.STEP
Entelechy/Entelechy_3D/BH-30R.STEP
Entelechy/Entelechy_3D/BH-34.STEP
Entelechy/Entelechy_3D/BH-34R.STEP
Entelechy/Entelechy_3D/BH-40R.STEP
Entelechy/Entelechy_3D/BH-50R.STEP
Entelechy/Entelechy_3D/BH-60R.STEP
Entelechy/Entelechy_3D/BH-64R.STEP
Entelechy/Entelechy_3D/Jumper2-blue.step
Entelechy/Entelechy_3D/Jumper2-yellow.step
Entelechy/Entelechy_3D/Jumper2.step
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

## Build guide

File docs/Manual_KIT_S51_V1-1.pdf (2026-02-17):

KIT S51 V1.1

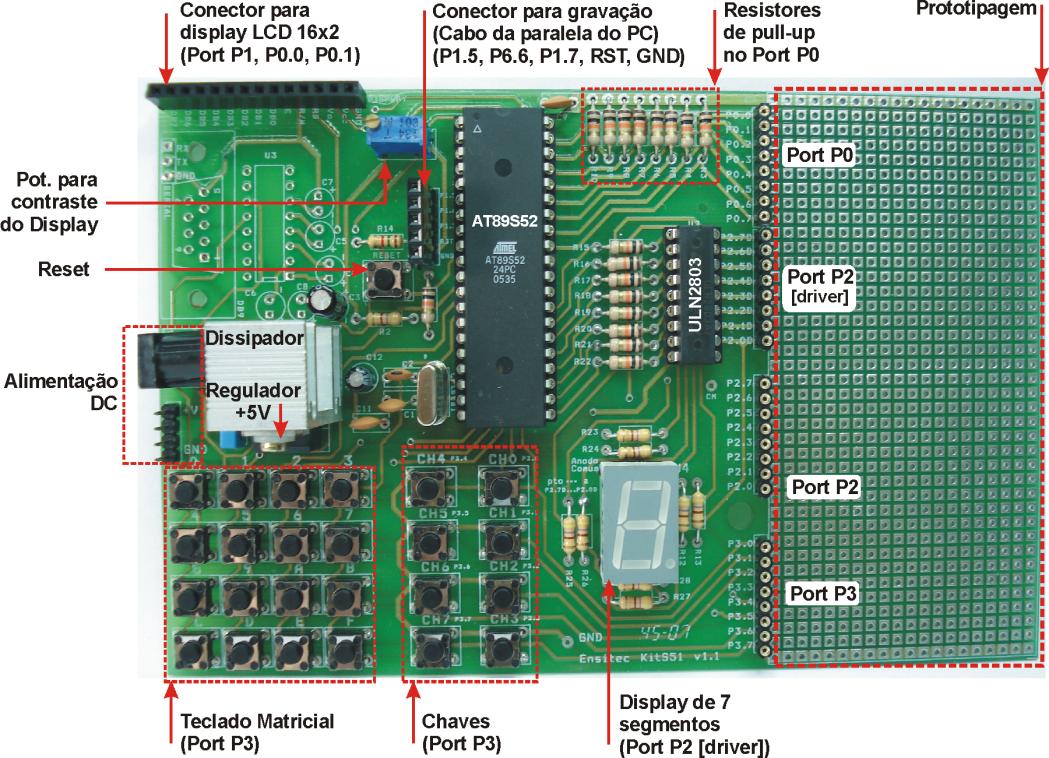
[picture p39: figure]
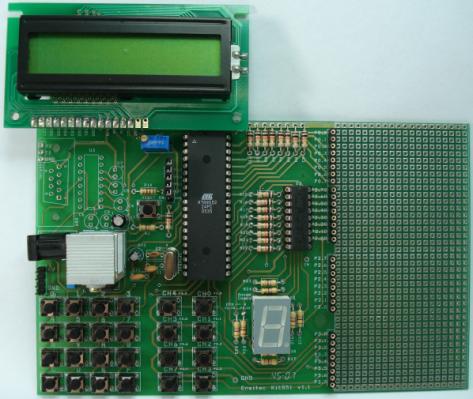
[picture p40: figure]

Ensitec - Profs. Gustavo B. Borba / Fernando E. Gazzoni | 1/34

2008

## KIT S51 Kit didático para microcontrolador AT89S51/52

## Requisitos

- Placa de circuito impresso “KIT S51 V1.1”.
- Componentes para montagem da placa.
- Cabo para gravação.
- Fonte DC.

## - Aplicativo “RIDE” para 8051, no qual serão desenvolvidos os programas a

serem gravados no microcontrolador.
- Aplicativo para gravação “Aec_isp.exe” (DOS).

## 1. Placa

## Lista de componentes:

17 resistores 10kΩ 9 resistores 470Ω 1 resistor 1k5Ω 1 trimpot multivoltas 10kΩ vertical 2 capacitores cerâmicos 100nF 2 capacitores eletrolíticos 10uF x 16V ou 25V 2 capacitores cerâmicos 33pF 1 capacitor poliéster 330nF 1 display de 7 segmentos anodo comum vermelho 1 cristal 11,059200 MHz 1 CI AT89S51 ou AT89S52 1 CI ULN2803 1 7805 (regulador de tensão) 25 micro-swich NA para PCI (ver foto da placa) Barra de pinos 180⁰ [4 pinos] Barra de pinos fêmea para PCI (mini modul para PCI) [19 pinos] Barra de pinos fêmea torneado [42 pinos] 1 soquete torneado 40 pinos 1 soquete torneado 18 pinos 1 display LCD 16 x 2 sem backlight

### Com o display

### Dica para montagem do display de 7 segmentos: soquete com barra de pinos

fêmea.

## 2. Circuito

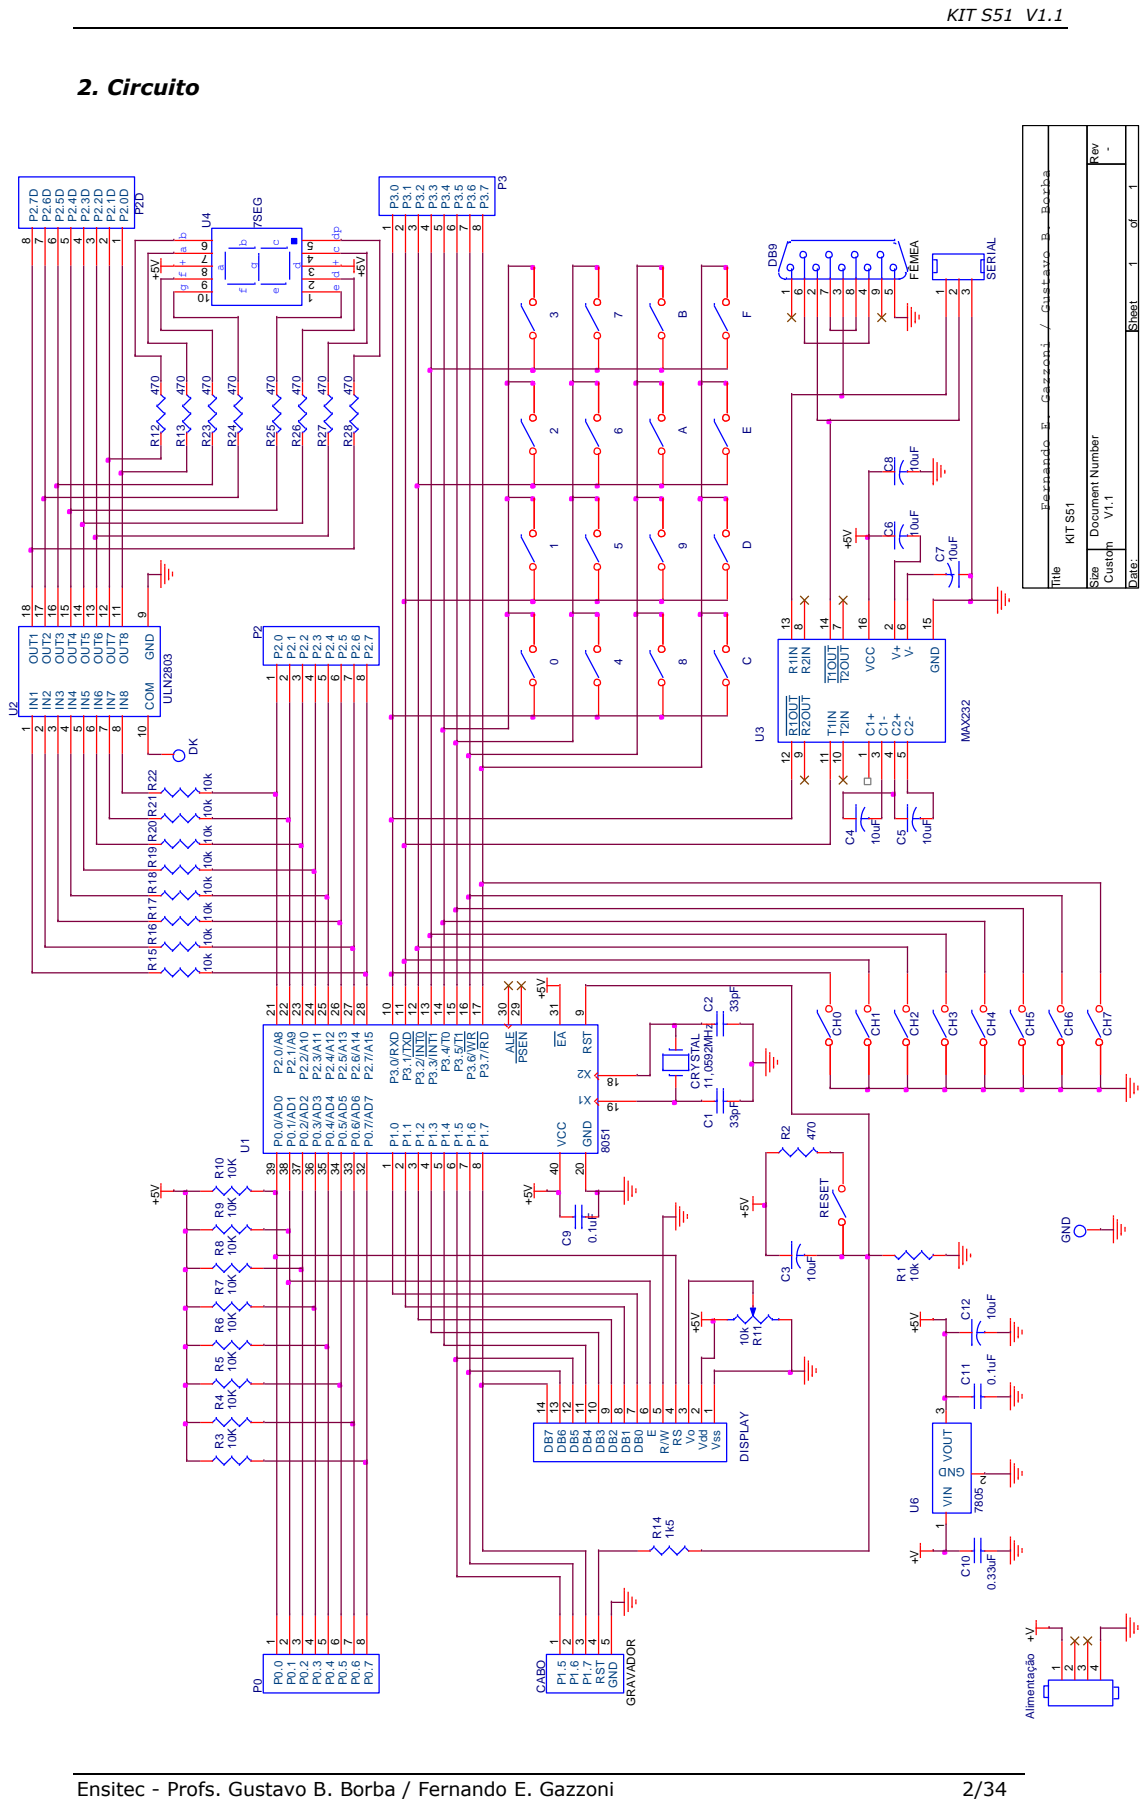
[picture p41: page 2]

Size Document Number Rev

Fernando E. Gazzoni / Gustavo B. Borba

Vss 1 Vdd 2 Vo 3 RS 4 R/W 5 E

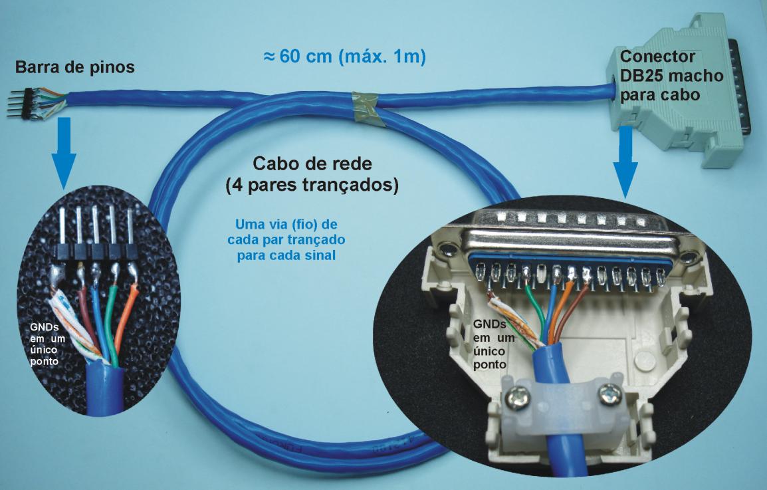
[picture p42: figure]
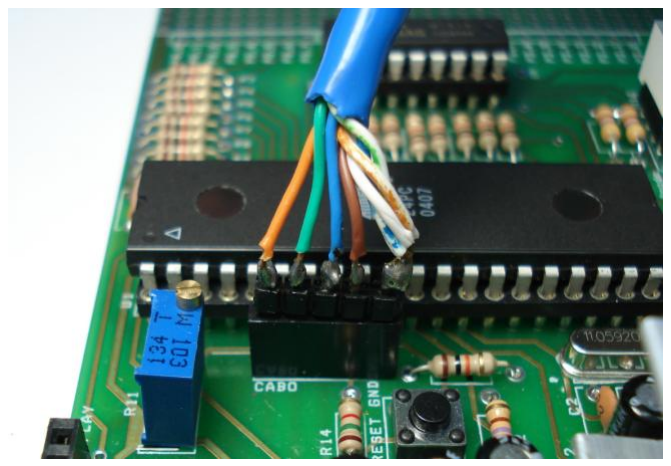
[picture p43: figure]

Ensitec - Profs. Gustavo B. Borba / Fernando E. Gazzoni | 3/34

## 3. Cabo para gravação

## Pinagem

DB25 (porta paralela) | Conector “CABO” da placa
7 | (D5) | P1.5
10 | (ACK) | P1.6
8 | (D6) | P1.7
6 | (D4) | RST
18-25 | (GND) | GND

## Montagem

- Componentes: aproximadamante 60 cm. de cabo de rede (8 vias, 4 pares trançados); conector DB25 macho para cabo;

## barra de pinos 180⁰

[5 pinos];
- Uma via (fio) de cada par trançado para cada sinal (D5, ACK, D6, D4).
- GNDs em um único ponto.

## Cabo conectado na

placa.

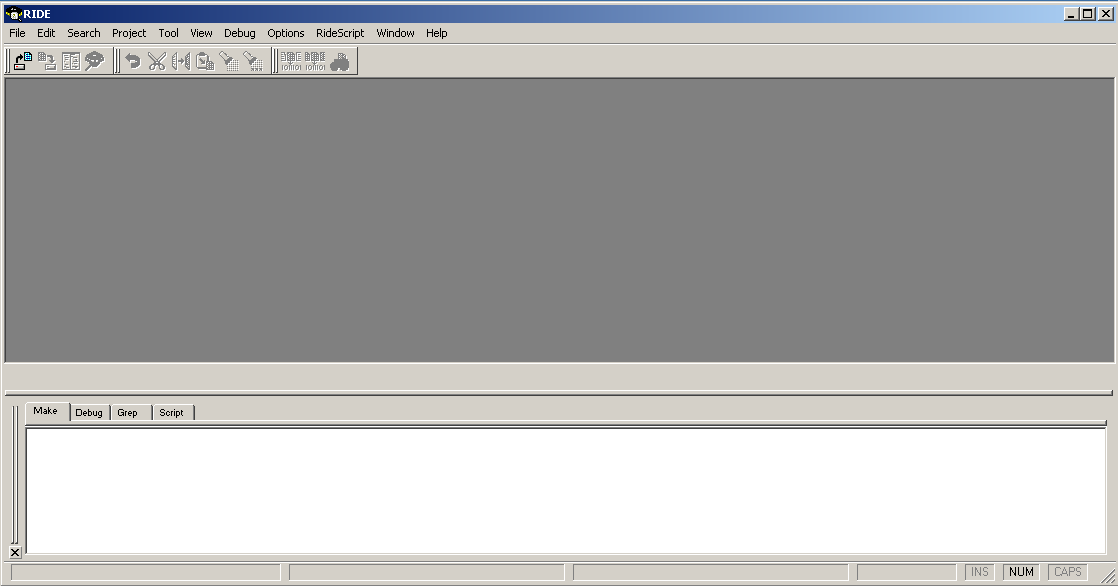
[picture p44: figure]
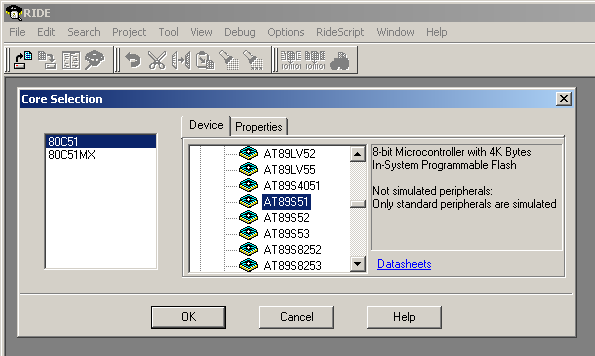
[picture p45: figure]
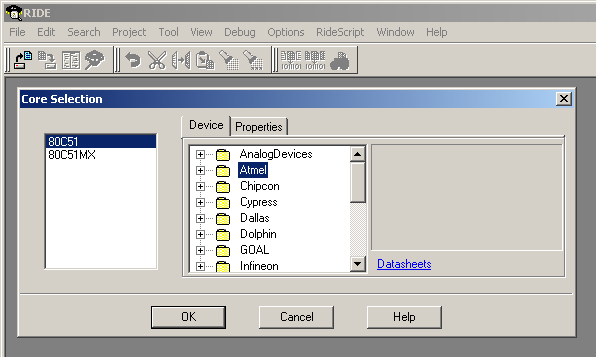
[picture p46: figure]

Ensitec - Profs. Gustavo B. Borba / Fernando E. Gazzoni | 4/34

## 4. Aplicativos

## - Para o desenvolvimento dos programas a serem gravados no microcontrolador: RIDE - IDE Raisonance para 8051 1º Faça o download em http://www.raisonance.com/download/index.php, clicando em

Eval51. (http://www.raisonance.com/download/dwnlform_new.php?TOOLS=51&BN=744) É necessário um pequeno cadastro.

## 2º Instale. O aplicativo chama-se RIDE. É uma versão de avaliação com todas as

funcionalidades da versão completa, porém limitada a 4k de código.

## - Para a gravação do programa no microcontrolador: Aec_isp.exe

Faça | o | Download | em | http://www.aec-electronics.co.nz/index.php?page_id=18. | É
necessário um pequeno cadastro.

## Roda em linha de comando (DOS) e grava os microcontroladores 8051 ATMEL da linha AT89S, modelos AT89S51/52/53/8252. Comunica-se com o microcontrolador pela porta

paralela, utilizando o cabo descrito anteriormente.

## 5. Tutorial

## 1º Programa a ser gravado no microcontrolador

Passo 1.

## Abrir o RIDE:

## Passo 2. Selecionar a CPU: Options → TarGet

Selecionar ‘80C51’ e abrir a pasta ‘Atmel’ Selecionar ‘AT89S51’ ou ‘AT89S52’ e clicar em OK

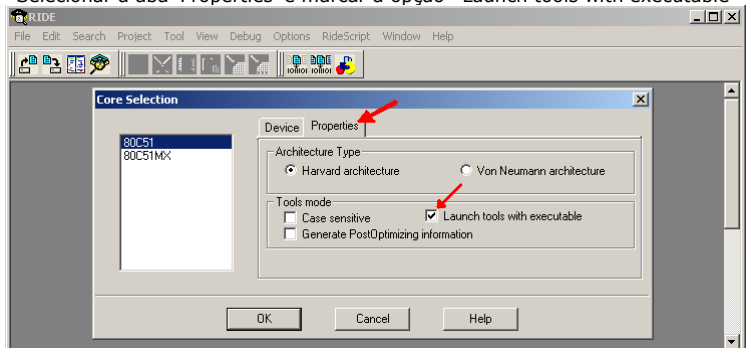
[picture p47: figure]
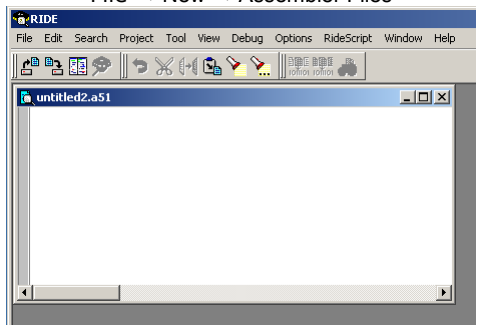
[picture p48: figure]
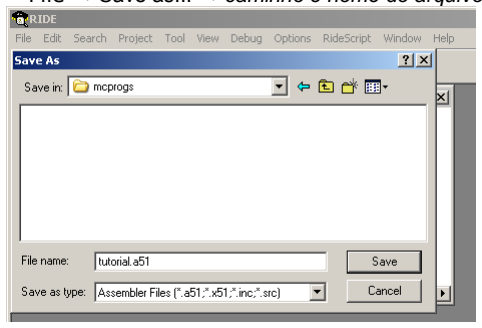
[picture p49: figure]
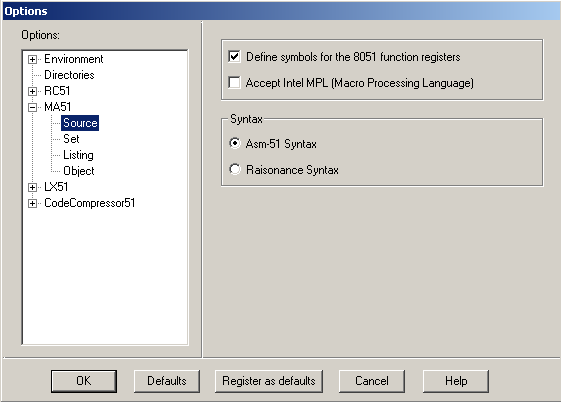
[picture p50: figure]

Ensitec - Profs. Gustavo B. Borba / Fernando E. Gazzoni | 5/34

## Selecionar a aba ‘Properties’ e marcar a opção ‘Launch tools with executable’

## Passo 3. Criar e salvar um arquivo para o código fonte:

File → New → Assembler Files | File → Save as... → caminho e nome do arquivo

## Passo 4. Configurar o Macro Assembler: Options → Project → + MA51 → Source

## Check no item ‘Define Symbols for the 8051 function registers’

e clicar em OK.

## (Esta configuração é armazenada, não

sendo | mais | necessária | nas | próximas

## sessões de uso do RIDE)

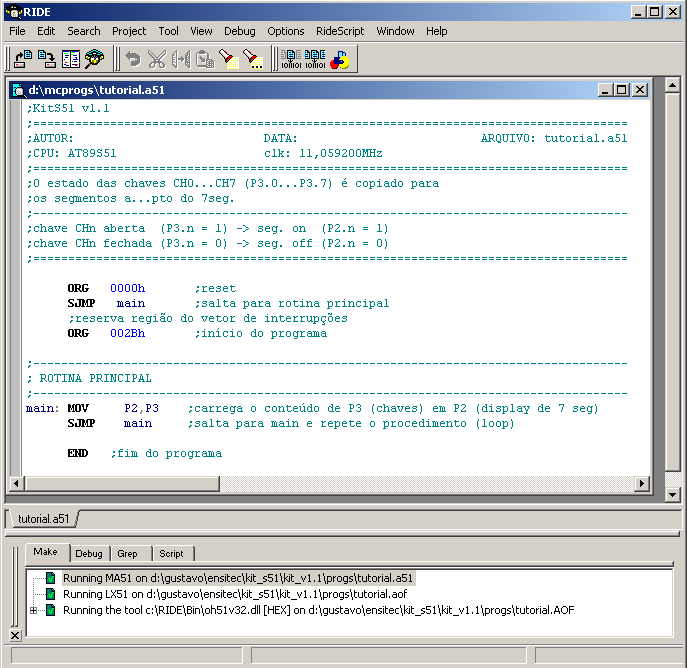
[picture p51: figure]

Ensitec - Profs. Gustavo B. Borba / Fernando E. Gazzoni | 6/34

## Passo 5. Digitar o programa: Este programa liga/desliga os segmentos do display de 7 segmentos a partir das

chaves CH0...CH7.
Caracteres após o ‘;’ são ignorados pelo assemblador (comentários).

;KitS51 v1.1
;=====================================================================================
;AUTOR: | DATA: | ARQUIVO: tutorial.a51
;CPU: AT89S51 | clk: 11,059200MHz
;===================================================================================== ;O estado das chaves CH0...CH7 (P3.0...P3.7) é copiado para
;os segmentos a...pto do 7seg. ;-------------------------------------------------------------------------------------
;chave CHn aberta | (P3.n = 1) -> seg. on | (P2.n = 1)
;chave CHn fechada (P3.n = 0) -> seg. off (P2.n = 0) ;=====================================================================================
ORG | 0000h | ;reset
SJMP | main | ;salta para rotina principal
;reserva região do vetor de interrupções
ORG | 002Bh | ;início do programa

;-------------------------------------------------------------------------------------; ROTINA PRINCIPAL
;-------------------------------------------------------------------------------------
main: MOV | P2,P3 | ;carrega o conteúdo de P3 (chaves) em P2 (display de 7 seg)
SJMP | main | ;salta para main e repete o procedimento (loop)
END | ;fim do programa

## Passo 6. Assemblar e linkar: Project → Make all (ou tecla ‘F9’) O arquivo no formato hexa Intel foi gerado e encontra-se no mesmo diretório em

que o programa foi salvo. Possui o mesmo nome do programa e extensão .hex. Neste caso, tutorial.hex.

## 2º Gravação e execução

- A placa KIT S51 v1.1 deve estar alimentada.

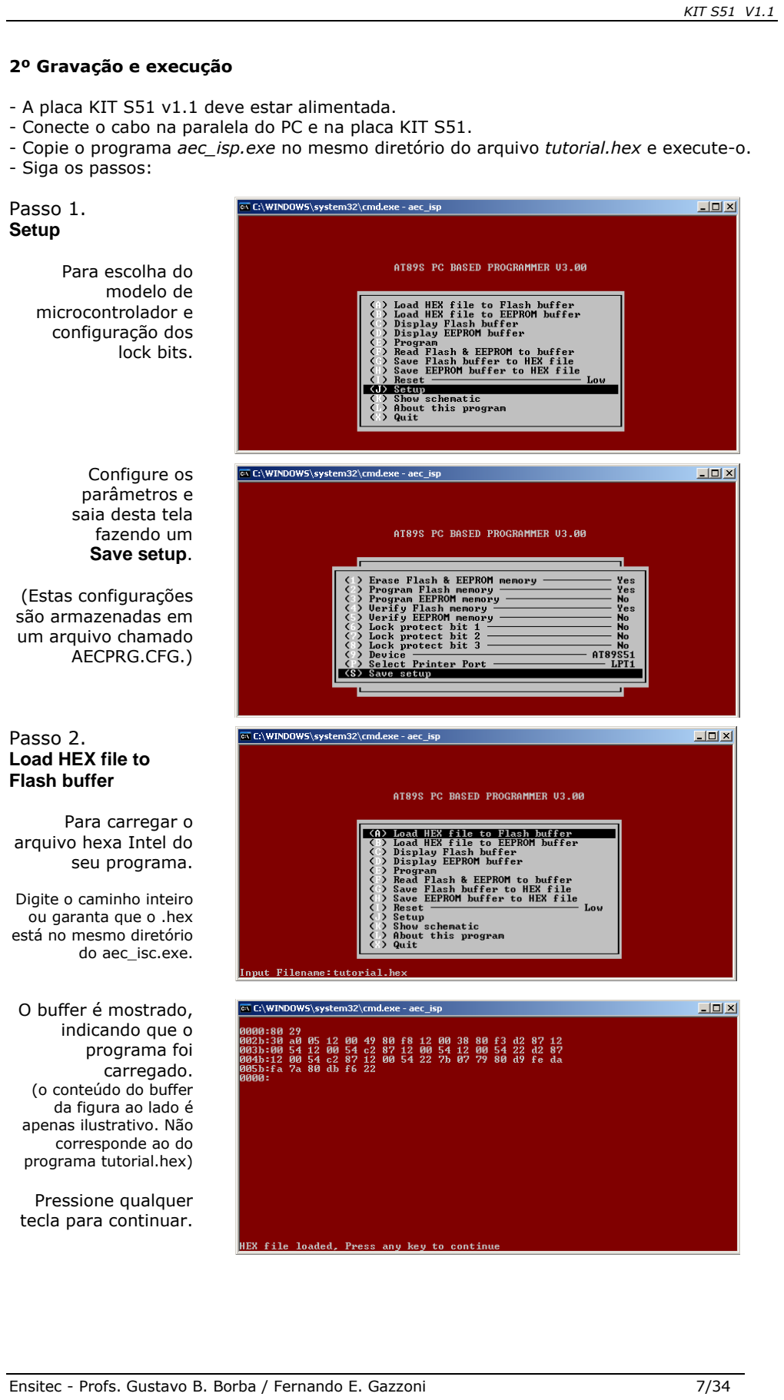
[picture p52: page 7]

Ensitec - Profs. Gustavo B. Borba / Fernando E. Gazzoni | 7/34
- Conecte o cabo na paralela do PC e na placa KIT S51.
- Copie o programa aec_isp.exe no mesmo diretório do arquivo tutorial.hex e execute-o.

## - Siga os passos:

Passo 1.

## Setup

## Para escolha do modelo de microcontrolador e configuração dos

lock bits.

## Configure os parâmetros e saia desta tela fazendo um

Save setup.

## (Estas configurações são armazenadas em um arquivo chamado AECPRG.CFG.)

Passo 2.

## Load HEX file to Flash buffer

## Para carregar o arquivo hexa Intel do

seu programa.

### Digite o caminho inteiro ou garanta que o .hex está no mesmo diretório

do aec_isc.exe.

O buffer é mostrado,

## indicando que o programa foi

carregado.

### (o conteúdo do buffer da figura ao lado é apenas ilustrativo. Não corresponde ao do programa tutorial.hex)

## Pressione qualquer

tecla para continuar.

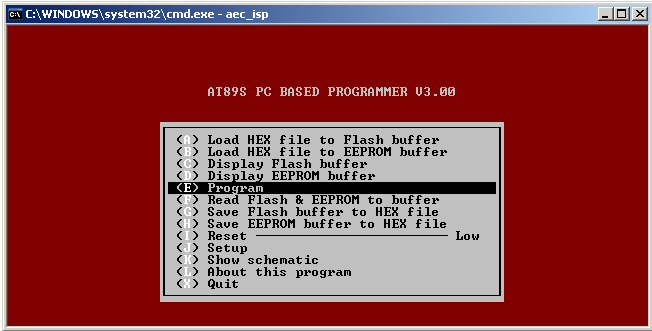
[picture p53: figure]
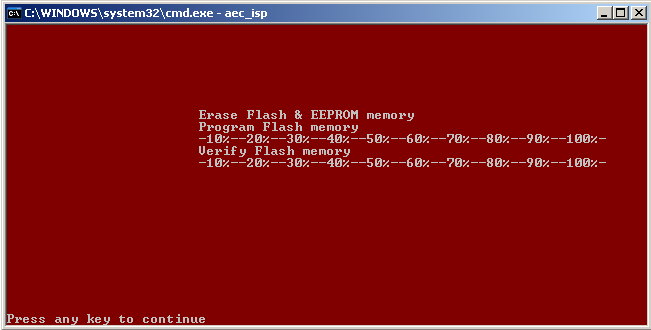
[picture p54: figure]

Ensitec - Profs. Gustavo B. Borba / Fernando E. Gazzoni | 8/34

Passo 3.

## Program

Para gravar.

OK!

## Desconecte o cabo da placa e o programa

estará rodando.

## Caso tenha recebido uma mensagem de erro durante a gravação, revise a alimentação e o clock do microcontrolador e

as conexões do cabo.

## ATENÇÃO

Durante a gravação seu circuito está conectado diretamente na porta paralela do PC.

## Portanto, cuidado para não danificá-la! Para não haver riscos, durante o procedimento de gravação, é recomendável manter os pinos P1.5, P1.6 e P1.7 do AT89S desconectados do seu

circuito, deixando-os em contato apenas com a porta paralela. Na placa KIT S51 estes pinos

## são compartilhados pelo barramento do display. Em condições normais, mesmo com o

display conectado, a gravação ocorre normalmente e não há risco de danos à porta paralela.

## 6. Exemplos

## Exemplo 1

;=====================================================================================
;AUTOR: Gustavo B. Borba/Fernando E. Gazzoni | DATA: 10/2006 | ARQUIVO: led.a51
;CPU: AT89S51 | clk: 11,059200MHz
;===================================================================================== ;Chaves em P3.0 e P3.1 piscam os segmentos "a" e "d" do display de 7 seg. ;===================================================================================== ;P3.0 = acionada -> Pisca os segmentos alternadamente
;P3.1 = acionada -> Pisca os segmentos em conjunto ;=====================================================================================
ORG | 00h
MOV | P2,#00;APAGA TODOS OS SEGMENTOS

;-------------------------------------------------------------------------------------; PROGRAMA PRINCIPAL --> TESTE DAS CHAVES ;-------------------------------------------------------------------------------------INICIO:
MOV | R0,P3
CJNE | R0,#11111110b,TESTE2 ;verifica se...
LCALL CHAVE0; ...CH0 foi pressionada. LJMP INICIO
TESTE2:
CJNE R0,#11111101b,INICIO ;verifica se... LCALL CHAVE1; ...CH1 foi pressionada. LJMP INICIO

Ensitec - Profs. Gustavo B. Borba / Fernando E. Gazzoni | 9/34

;-------------------------------------------------------------------------------------; SUBROTINA PARA PISCAR OS SEGMENTOS ALTERNADAMENTE ;-------------------------------------------------------------------------------------CHAVE0:
SETB | P2.0 | ;acende segmento a
CLR | P2.3 | ;apaga segmento d
LCALL ATRASO
SETB | P2.3 | ;acende segmento d
CLR | P2.0 | ;apaga segmento a
LCALL ATRASO
SETB | P2.0 | ;acende segmento a
CLR | P2.3 | ;apaga segmento d
LCALL ATRASO
SETB | P2.3 | ;acende segmento d
CLR | P2.0 | ;apaga segmento a
LCALL ATRASO
SETB | P2.0 | ;acende segmento a
CLR | P2.3 | ;apaga segmento d
LCALL ATRASO
SETB | P2.3 | ;acende segmento d
CLR | P2.0 | ;apaga segmento a
LCALL ATRASO
CLR | P2.3 | ;apaga segmento d
RET

;-------------------------------------------------------------------------------------; SUBROTINA PARA PISCA OS SEGMENTOS EM CONJUNTO ;-------------------------------------------------------------------------------------CHAVE1:
MOV P2,#09h ;acende segmento a e segmento d
LCALL ATRASO
MOV P2,#00h ;apaga segmento a e segmento d LCALL ATRASO
MOV P2,#09h ;acende segmento a e segmento d LCALL ATRASO
MOV P2,#00h ;apaga segmento a e segmento d LCALL ATRASO
MOV P2,#09h ;acende segmento a e segmento d LCALL ATRASO
MOV P2,#00h ;apaga segmento a e segmento d LCALL ATRASO
RET

;-------------------------------------------------------------------------------------; SUBROTINA PARA GERAR ATRASO DE:
; (R3x24 + R3xR2x24 + R3xR2xR1x24)/freq clock ;-------------------------------------------------------------------------------------ATRASO:
MOV | R3,#7 ;gera atraso de...
MOV | R2,#255 ;... aproximadamente...
MOV | R1,#255 ;... 1 segundo
VOLTA:
DJNZ | R1,$
MOV | R1,#255
DJNZ | R2,VOLTA
MOV | R2,#255
DJNZ | R3,VOLTA
RET

END

Ensitec - Profs. Gustavo B. Borba / Fernando E. Gazzoni | 10/34

## Exemplo 2

;==============================================================================
;AUTOR:Fernando E. Gazzoni/GUSTAVO B. BORBA | DATA: 05/2008 | ARQUIVO: lcd.a51 =
;CPU: AT89S51 | clk: 11,059200MHz | =
;============================================================================== ;Quatro chaves colocadas em P3.0, P3.1, P3.2 e P3.3 comandam o display LCD = ;============================================================================== ;P3.0 = acionada -> Apaga tudo e escreve "TESTE DE DISPLAY" na primeira linha =
;P3.1 = acionada -> Escreve "Kit | S51" na segunda linha | =
;P3.2 = acionada -> Apaga tudo e escreve uma frase nas duas linhas do display =
;P3.3 = acionada -> Apaga o que estiver escrito no display | =
;==============================================================================
ORG | 00h
MOV | P2,#00 ;apaga todos os segmentos do display de 7 segmentos

;==============================================================================
; INICIO DO PROGRAMA PRINCIPAL | =
;==============================================================================

LCALL INILCD

;------------------------------------------------------------------------------
; LEITURA DAS CHAVES | -
;------------------------------------------------------------------------------

MAIN:
MOV | A,P3
CJNE | A,#11111110b,C1 ;se achave CH0 (em P3.0) for pressionada...
LCALL CH0 ;...chama subrotina CH0
JMP MAIN
C1:
CJNE A,#11111101b,C2 ;se a chave CH1 (em P3.1) for pressionada... LCALL CH1 ;...chama a subrotina CH1
JMP MAIN
C2:
CJNE A,#11111011b,C3 ;se a chave CH2 (em P3.2) for pressionada... LCALL CH2 ;... chama a subrotina CH2
JMP MAIN
C3:
CJNE A,#11110111b,MAIN ;se a chave CH3 (em P3.3) for pressionada... LCALL CLEARLCD ;... apaga os dados escritos no LCD
JMP MAIN

;------------------------------------------------------------------------------
; SUBROTINA DE TRATAMENTO DA CHAVE CH0 (EM P3.0) | -
;------------------------------------------------------------------------------CH0:
LCALL CLEARLCD ;...apaga todos os caracteres escritos no display
MOV DPTR,#FRASE1
LCALL PRINTSTRING
RET

;------------------------------------------------------------------------------
; SUBROTINA DE TRATAMENTO DA CHAVE CH1 (EM P3.1) | -
;------------------------------------------------------------------------------CH1:
MOV B,#40h ;seleciona primeira coluna da segunda linha
LCALL POSCURSOR
MOV DPTR,#FRASE2
LCALL PRINTSTRING
RET

;------------------------------------------------------------------------------
; SUBROTINA DE TRATAMENTO DA CHAVE CH2 (EM P3.2) | -
;------------------------------------------------------------------------------CH2:
MOV DPTR,#FRASE3

Ensitec - Profs. Gustavo B. Borba / Fernando E. Gazzoni | 11/34

LCALL PRINTSTRINGALL
RET

;------------------------------------------------------------------------------
; FRASES A SEREM ESCRITAS NO DISPLAY | -
;------------------------------------------------------------------------------FRASE1:
DB | 'TESTE DE DISPLAY!\'
FRASE2:
DB | 'Kit | S51\'
FRASE3:
DB | 'MICROCONTROLADORES/ | ENSITEC\'

;==============================================================================
;= | SUBROTINAS PARA O DISPLAY LCD | =
;==============================================================================

;==============================================================================
; | | | | RESUMO DAS FUNCOES | =
;==============================================================================
; | NOME | = ENTRADA = | DESCRICAO | =
;==============================================================================
; | INILCD | = | | = Inicializacao do LCD | =
;------------------------------------------------------------------------------
; | CLEARLCD | = | = Apaga todos caracteres e coloca cursor no inicio =
;------------------------------------------------------------------------------
; | POSCURSOR | = | B | = Seleciona a posicao do cursor no display | =
;------------------------------------------------------------------------------
; | IWRITE | = | B | = Executa uma instrucao | =
;------------------------------------------------------------------------------
; | PRINTASCII | = | B | = Escreve um caractere ASCII no display | =
;------------------------------------------------------------------------------
; | PRINTBCDL | = | B | = Escreve um digito BCD (menos significativo) | =
;------------------------------------------------------------------------------
; | PRINTBCDHL | = | B | = Escreves dois digitos BCD | =
;------------------------------------------------------------------------------
; | PRINTHEXAL | = | B | = Escreve um digito hexadecimal(menos significativo=
;------------------------------------------------------------------------------
; | PRINTHEXAHL | = | B | = Escreve dois digitos hexadecimal | =
;------------------------------------------------------------------------------
; | PRINTSTRING | = | DPTR | = Escreve frase em uma das linhas do display | =
;------------------------------------------------------------------------------
; PRINTSTRINGALL = | DPTR | = Escreve frase nas duas linhas do display | =
;------------------------------------------------------------------------------
; | SHIFTLCDR | = | B | = Desloca caracteres escritos no LCD para direita | =
;------------------------------------------------------------------------------
; | SHIFTLCDL | = | B | = Desloca caracteres escritos no LCD para esquerda =
;------------------------------------------------------------------------------
; | DELAY | = | R6 | = Gera atraso de R6 x 0,5ms | =
;==============================================================================

;------------------------------------------------------------------------------
; INICIALIZACAO DO DISPLAY | -
;------------------------------------------------------------------------------
; ENTRADA: nenhuma | -
; SAIDA: nenhuma | -
; | -
; DESTROI: R1 | -
; CHAMA: IWRITE, CLEARLCD, DELAY | -
;------------------------------------------------------------------------------

INILCD:
CLR | P0.1 | ;desabilita a escrita no display
MOV | R6,#50 ;gera atraso de 50x0,5ms = 25ms
LCALL DELAY
MOV B,#00110000b ;comando para inicializacao LCALL IWRITE
MOV | R6,#9 | ;gera atraso de 9x0,5ms = 4,5ms
LCALL DELAY

Ensitec - Profs. Gustavo B. Borba / Fernando E. Gazzoni | 12/34

LCALL IWRITE ;repete instrucao
MOV | R6,#1 | ;gera atraso de 1x0,5ms = 0,5ms
LCALL DELAY
LCALL IWRITE ;repete instrucao

; Configuracao do usuario

MOV | B,#00111000b
| | ;|||______ F = 0 -> matrizde 5x8 pontos ;||_______ N = 1-> 2 linhas ;|________ DL = 1 -> 8 bits

LCALL IWRITE

MOV | B,#00001110b
| | ;|||____ B = 0 -> local do cursor nao pisca ;||_____ C = 1 -> cursor visivel ;|______ D = 1 -> liga o display (aparece frase)

LCALL IWRITE

MOV | B,#00000110b
| | ;||____ SH=0 -> não desloca frase ao escrever caractere ;|_____ I/D = 1 -> cursor se move para direita

LCALL IWRITE

LCALL CLEARLCD
RET

;------------------------------------------------------------------------------
; SUBROTINA PARA LIMPAR O DISPLAY | -
;------------------------------------------------------------------------------
; Apaga todos os caracteres e posiciona o cursor no inicio do display | -
;------------------------------------------------------------------------------
; ENTRADA: nenhuma | | -
; SAIDA: nenhuma | | -
; | -
; DESTROI: Caracteres armazenados da DDRAM, R6, A | -
; CHAMA: IWRITE, POSCURSOR, DELAY | -
;------------------------------------------------------------------------------

CLEARLCD:
PUSH | B
MOV | B,#00000001b ;Instrucao Clear display
LCALL IWRITE
MOV | R6,#3 | ;atraso de 1,5ms -> tempo que a instrucao...
LCALL DELAY | ;...clear display leva para ser executada
MOV | B,#0 | ;posiciona o cursor no inicio do display -> endereco 00h
LCALL POSCURSOR
POP B
RET

;------------------------------------------------------------------------------
; SUBROTINA PARA SELECIONAR A POSICAO DO CURSOR NO DISPLAY | -
;------------------------------------------------------------------------------
; ENTRADA: B --> endereco da DDRAM que o cursor sera posicionado | -
; SAIDA: nenhuma | | -
; | -
; DESTROI: A, B | | -
; CHAMA: IWRITE | | -
;------------------------------------------------------------------------------

POSCURSOR:
PUSH | B ;armazena o valor de B na pilha
MOV | A,B
ORL | A,#10000000b
MOV | B,A
LCALL IWRITE
POP B ;restaura o valor de B RET

Ensitec - Profs. Gustavo B. Borba / Fernando E. Gazzoni | 13/34

;------------------------------------------------------------------------------
; SUBROTINA PARA EXECUTAR INSTRUCOES NO DISPLAY | -
;------------------------------------------------------------------------------
; ENTRADA: B --> instrucao a ser executada | -
; SAIDA: nenhuma | -
; | -
; DESTROI: R7 | -
; CHAMA: runT0 | -
;------------------------------------------------------------------------------

IWRITE:
MOV | P1,B
CLR | P0.0 ;seleciona RS = 0 (instrucao)
SETB | P0.1 ;habilita escrita
MOV | R7,#18 ;aguarda 39us para...
DJNZ | R7,$ ;executar o comando
CLR | P0.1 ;desabilita escrita
RET

;------------------------------------------------------------------------------
; SUBROTINA PARA ESCREVER CARACTER ASCII NO DISPLAY | -
;------------------------------------------------------------------------------
; ENTRADA: B --> caractere (em ASCII) a ser escrito no display | -
; SAIDA: nenhuma | -
; | -
; DESTROI: R7 | -
; CHAMA: runT0 | -
;------------------------------------------------------------------------------

PRINTASCII:
MOV | P1,B
SETB | P0.0 ;seleciona RS = 1 (dado)
SETB | P0.1 ;habilita escrita
MOV | R7,#20 ;aguarda 43us para...
DJNZ | R7,$ ;... realizar a escrita
CLR | P0.1 ;desabilita escrita
RET

;------------------------------------------------------------------------------
; SUBROTINA PARA ESCREVER DIGITO BCD MENOS SIGNIFICATIVO | -
;------------------------------------------------------------------------------; Serao escritos caracteres indesejados se o numero nao estiver no formato BCD-;------------------------------------------------------------------------------
; ENTRADA: B --> numero BCD | -
; SAIDA: nenhuma | -
; | -
; DESTROI: A | -
; CHAMA: PRINTASCII | -
;------------------------------------------------------------------------------

PRINTBCDL:
PUSH | B ;armazena conteudo de B na pilha
MOV | A,B
ANL | A,#00001111b ;usa apenas 4bits menos significativo
ADD | A,#30h ;converte resultado para ASCII
MOV | B,A
LCALL PRINTASCII
POP B ;restaura conteudo de B da pilha RET

;------------------------------------------------------------------------------

Ensitec - Profs. Gustavo B. Borba / Fernando E. Gazzoni | 14/34
; SUBROTINA PARA ESCREVER DOIS DIGITOS BCD | -
;------------------------------------------------------------------------------; Serao escritos caracteres indesejados se o numero nao estiver no formato BCD-;------------------------------------------------------------------------------
; ENTRADA: B --> numero BCD | -
; SAIDA: nenhuma | -
; | -
; DESTROI: A, B | -
; CHAMA: PRINTASCII | -
;------------------------------------------------------------------------------PRINTBCDHL:
PUSH | B ;armazena conteudo de B na pilha
MOV | A,B
ANL | A,#11110000b ;separa 4 bits mais significativos
SWAP | A ;troca nibble menos significativo por mais significativo
ADD | A,#30h ;converte para ASCII
MOV | B,A ;restaura conteudo de B da pilha
LCALL PRINTASCII
POP | B
MOV | A,B
ANL | A,#00001111b ;separa 4 bits menos significativos
ADD | A,#30h ;converte para ASCII
MOV | B,A
LCALL PRINTASCII
RET

;------------------------------------------------------------------------------
; SUBROTINA PARA ESCREVER DIGITO HEXADECIMAL MENOS SIGNIFICATIVO | -
;------------------------------------------------------------------------------
; ENTRADA: B --> numero HEXA | -
; SAIDA: nenhuma | -
; | -
; DESTROI: A, DPTR | -
; CHAMA: PRINTASCII | -
;------------------------------------------------------------------------------PRINTHEXAL:
PUSH | B ;armazena conteudo de B na pilha
MOV | DPTR,#TABHEXA
MOV | A,B
ANL | A,#00001111b ;separa nibble menos significativo
MOVC | A,@A+DPTR ;converte caractere para ASCII
MOV | B,A
LCALL PRINTASCII
POP B ;restaura conteudo de B da pilha
RET

;------------------------------------------------------------------------------
; SUBROTINA PARA ESCREVER DOIS DIGITOS HEXADECIMAIS | -
;------------------------------------------------------------------------------
; ENTRADA: B --> numero HEXA | -
; SAIDA: nenhuma | -
; | -
; DESTROI: A, DPTR | -
; CHAMA: PRINTASCII | -
;------------------------------------------------------------------------------

PRINTHEXAHL:
PUSH | B ;armazena conteudo de B na pilha
MOV | DPTR,#TABHEXA
MOV | A,B
ANL | A,#11110000b ;separa nibble mais significativo
SWAP | A ;troca nibble menos significativo por mais significativo
MOVC | A,@A+DPTR ;converte caractere para ASCII
MOV | B,A
LCALL PRINTASCII
POP | B ;restaura conteudo de B da pilha
MOV | A,B
ANL | A,#00001111b ;separa nibble menos significativo
MOVC | A,@A+DPTR ;converte caractere para ASCII
MOV | B,A
LCALL PRINTASCII
RET

Ensitec - Profs. Gustavo B. Borba / Fernando E. Gazzoni | 15/34

TABHEXA:
DB | '0123456789ABCDEF'

;------------------------------------------------------------------------------
; SUBROTINA PARA ESCREVER FRASE EM APENAS UMA LINHA DO DISPLAY | -
;------------------------------------------------------------------------------
; ENTRADA: DPTR --> frase a ser escrita | -
; SAIDA: nenhuma | -
; | -
; DESTROI: A, R0 | -
; CHAMA: PRINTASCII | -
;------------------------------------------------------------------------------
; Caractere especial: '\' -> fim da frase | -
; | -
; Nao verifica se a frase cabe no display | -
; Precisa ser colocado o caractere '\' no final da frase | -
;------------------------------------------------------------------------------

PRINTSTRING:
PUSH | B ;armazena conteudo de B na pilha
MOV | R0,#0 ;inicia a escrita a partir da primeira letra da frase

PRINTS:
MOV | A,R0 ;converte o caractere hexadecimal...
MOVC | A,@A+DPTR ;... em ASCII
MOV | B,A
CJNE | A,#'\',WRITE ;encontrou o caractere '\' ?
POP | B | ;sim -> para de escrever
RET

WRITE:
LCALL PRINTASCII
INC | R0
JMP | PRINTS

;------------------------------------------------------------------------------
; SUBROTINA PARA ESCREVER FRASES NAS DUAS LINHAS DO DISPLAY | -
;------------------------------------------------------------------------------
; ENTRADA: DPTR --> frase a ser escrita | -
; SAIDA: nenhuma | -
; | -
; DESTROI: A, R0 | -
; CHAMA: PRINTASCII | -
;------------------------------------------------------------------------------
; Caracteres especiais: '/' -> quebra de linha (da primeira para a segunda) | -
; | '\' -> fim da frase | -
; | -
; Nao verifica se a frase cabe no display | -
; Precisa ser colocado o caractere '\' no final da frase | -
;------------------------------------------------------------------------------

PRINTSTRINGALL:
PUSH B ;armazena conteudo de B na pilha
LCALL CLEARLCD
MOV R0,#0 ;inicia a escrita a partir da primeira letra da frase

PRINTSALL:
MOV | A,R0 ;converte o caractere hexadecimal...
MOVC | A,@A+DPTR ;... em ASCII
MOV | B,A
CJNE | A,#'/',FIMSTR ;encontrou o caractere '/' ?
MOV | B,#40h ;sim -> comeca a escrever na segunda linha
LCALL POSCURSOR
INC | R0
JMP | PRINTSALL

WRITEALL:
LCALL PRINTASCII
INC R0

Ensitec - Profs. Gustavo B. Borba / Fernando E. Gazzoni | 16/34
JMP | PRINTSALL

FIMSTR:
CJNE | A,#'\',WRITEALL ;encontrou o caractere '\'?
POP | B | ;sim -> para de escrever
RET

;------------------------------------------------------------------------------
; SUBROTINA PARA DESLOCAR A FRASE A DIREITA | -
;------------------------------------------------------------------------------
; Desloca para a direita todos os caracteres ja escritos no display | -
;------------------------------------------------------------------------------
; ENTRADA: nenhuma | -
; SAIDA: nenhuma | -
; | -
; DESTROI: | -
; CHAMA: IWRITE | -
;------------------------------------------------------------------------------

SHIFTLCDR:
PUSH | B ;armazena conteudo de B na pilha
MOV | B,#00011100b
LCALL IWRITE
POP B ;restaura conteudo de B na pilha RET

;------------------------------------------------------------------------------
; SUBROTINA PARA DESLOCAR A FRASE A ESQUERDA | -
;------------------------------------------------------------------------------
; Desloca para a esquerda todos os caracteres ja escritos no display | -
;------------------------------------------------------------------------------
; ENTRADA: nenhuma | -
; SAIDA: nenhuma | -
; | -
; DESTROI: B | -
; CHAMA: IWRITE | -
;------------------------------------------------------------------------------

SHIFTLCDL:
PUSH | B ;armazena conteudo de B na pilha
MOV | B,#00011000b
LCALL IWRITE
POP B ;restaura conteudo de B na pilha RET
;------------------------------------------------------------------------------
; SUBROTINA PARA GERAR ATRASO DE R1 x 0,5ms | -
;------------------------------------------------------------------------------
; ENTRADA: R6 --> valor a ser multiplicado pela base de tempo | -
; | -
; SAIDA: nenhuma | -
; | -
; DESTROI: R7, R6 | -
;------------------------------------------------------------------------------

DELAY:
MOV | R7,#228
DJNZ | R7,$
DJNZ | R6,DELAY
RET

END

Ensitec - Profs. Gustavo B. Borba / Fernando E. Gazzoni | 17/34

## Exemplo 3

;=====================================================================================
;AUTOR: Gustavo B. Borba/Fernando E. Gazzoni | DATA: 04/2007 | ARQUIVO: int0.a51
;CPU: AT89S51 | clk: 11,059200MHz
;===================================================================================== ;Duas chaves em P3.2 e P3.3 comandam um alarme ;===================================================================================== ;P3.3 = pressionado -> toca alarme
;P3.2 = borda de descida -> para alarme ;===================================================================================== ; Esquema elétrico simplificado:
;
; ----- | -------- | +5v | /|
; | | | | | | | | | --- |
; | 8 | | | | | U | 2 | | | ----| | |
; | 0 | | | | | L | 8 | | | ----| | | Buzzer
; | 5 | | | | | N | 0 | | | \ | --- |
; | 1 | | | PINO8| | 3 | |PINO11 | / | \|
; | |----------| | |------------ \
; ----- P2.7 | -------- | / 10k (potenciometro)
; | \
; | |
; | ------
; | ----
; | --
;=====================================================================================
DESLIGA | EQU | 00h ;flag de parada do alarme
ORG | 00h ;reset do sistema
LJMP | ini
ORG | 03h ;interrupcao externa 0
LJMP | int_ext0
ORG | 002Bh ;inicio do programa

;-------------------------------------------------------------------------------------;INICIALIZACAO: APENAS INT EXTERNA 0 HABILITADA, BORDA DE DESCIDA, PRIORID. ALTA
; T/C 0 NA FUNCAO TIMER, CONTROLADO POR TR0, MODO 1 ;-------------------------------------------------------------------------------------

ini:
MOV | IE,#00000000b ;desabilita todas as interrupcoes
MOV | TCON,#00000001b
; |||| | |___ IT0 = 1 -> int ext 0 por borda de descida
; ||||_______ TR0 = 0 -> timer 0 parado
; |||________ TF0 = 0 -> flag de overflow do T/C 0 zerado ; ||_________ TR1 = 0 -> timer 1 parado
; |__________ TF1 = 0 -> flag de overflow do T/C 1 zerado

MOV TMOD,#00000001b
; ||||___ M0 = 1 -> timer 0 no...
; |||____ M1 = 0 -> ... modo 1: 16 bits
; ||_____ C/T'= 0 -> timer 0 na funcao timer
; |______ GATE= 0 -> timer 0 controlado somente por TR0 ; T/C 1 nao utilizado

MOV IP,#00000001b
; |_____ PX0 = 1 -> prioridade alta para a int ext 0
MOV | IE,#10000001b
; | | |_____ EX0 = 1 -> habilita a int ext 0
; |____________ EA = 1 -> habilita todas as ints que... ; ...estiverem habilitadas

;-------------------------------------------------------------------------------------;PROGRAMA PRINCIPAL

Ensitec - Profs. Gustavo B. Borba / Fernando E. Gazzoni | 18/34

;-------------------------------------------------------------------------------------

le:
JB | P3.3,le ;verifica se a chave em P3.3 foi acionada
CLR | DESLIGA ;zera o flag de parada do alarme
LCALL alarme | ;chama a subrotina para tocar o alarme
SJMP | le

;-------------------------------------------------------------------------------------;ISR DA INTERRUPCAO EXTERNA 0 ;-------------------------------------------------------------------------------------

int_ext0:
SETB DESLIGA ;seta o flag de parada do alarme
RETI

;-------------------------------------------------------------------------------------; SUBROTINA QUE COMPLEMENTA P2.7 COM CICLO ATIVO DE 50% USANDO Timer 0
; OSCILACAO COM FREQ = 262Hz ;-------------------------------------------------------------------------------------; ENTRADA: nenhuma
; SAIDA: nenhuma
; DESTROI: nada
;-------------------------------------------------------------------------------------

alarme:
MOV | TH0,#0F9h
MOV | TL0,#1Eh
SETB | TR0 | ;dispara timer
JNB | TF0,$ ;preso
CLR | TR0 | ;stop timer
CLR | TF0 | ;zera flag overflow
CPL | P2.7 | ;complementa P2.0
JNB | DESLIGA,alarme ;sai se o flag de parada estiver setado
RET

END

Ensitec - Profs. Gustavo B. Borba / Fernando E. Gazzoni | 19/34

## Exemplo 4

;==============================================================================
;= AUTOR: FERNANDO GAZZONI/GUSTAVO BORBA | DATA:05/2008 | ARQUIVO:tec.a51 | =
;= CPU: AT89S51 | clk: 11,059200MHz | =
;==============================================================================
;= | Teclado matricial: escreve o valor da tecla no display LCD | =
;------------------------------------------------------------------------------
;= | Usa as funcoes do display LCD | =
;==============================================================================
ORG | 00h | ;reset
JMP | INI | ;salta para rotina principal
;reserva região do vetor de interrupções
ORG | 0050h | ;início do programa

;------------------------------------------------------------------------------
; | INICIALIZACAO DO DISPLAY | -
;------------------------------------------------------------------------------

INI:
MOV P2,#00 ;apaga display 7 segmentos LCALL INILCD
LCALL CLEARLCD

;------------------------------------------------------------------------------
; PROGRAMA PRINCIPAL | | | -
;------------------------------------------------------------------------------

MAIN:
LCALL IN_HEX ;chama subrotina para ler teclado MOV B,#07 ;escreve a partir do endereco... LCALL POSCURSOR ;... 07 do LCD
MOV B,R6 ;copia o valor da tecla pressionada... LCALL PRINTHEXAL ;... e mostra no LCD
SJMP MAIN

;==============================================================================
;= | SUBROTINAS PARA LEITURA DO TECLADO MATRICIAL | =
;==============================================================================

;------------------------------------------------------------------------------
; SUBROTINA PARA DEBOUNCE DA LEITURA DO TECLADO MATRICIAL | -
; LIVRO: The 8051 Microcontroller | AUTOR: MacKenzie, I. Scott | -
;------------------------------------------------------------------------------
; ENTRADA: nenhuma | | | -
; SAIDA: nenhuma | | | -
; DESTROI: R4, R6 | -
; CHAMA: READ | | | -
; | | | -
; USA DEBOUNCE DE 50 REPETICOES | | | -
;------------------------------------------------------------------------------

IN_HEX:
MOV R4,#50 ;contador para debounce RETURN:
CALL | READ | ;chave foi pressionada?
JNC | IN_HEX | ;nao -> verifica novamente
DJNZ | R4,RETURN ;sim -> repete 50x
PUSH | ACC ;armazena na pilha o codigo hexa da tecla apertada
RETURN2:
MOV R4,#50 ;aguarda a chave ser solta
RETURN3:
CALL | READ | ;chave continua pressionada?
JC | RETURN2 | ;sim -> verifica novamente
DJNZ | R4,RETURN3 | ;nao -> repete 50x
POP | ACC ;recupera o codigo hexa da chave e...
MOV | R6,A ;... salva em R6
RET

;------------------------------------------------------------------------------
; SUBROTINA PARA LEITURA E DECODIFICACAO DO TECLADO MATRICIAL | -

Ensitec - Profs. Gustavo B. Borba / Fernando E. Gazzoni | 20/34
; LIVRO: The 8051 Microcontroller | AUTOR: MacKenzie, I. Scott | -
;------------------------------------------------------------------------------
; ENTRADA: chaves colocadas no port3 | -
; SAIDA: DISP -> codigo hexadecimal da chave que foi apertada | -
; | -
; DESTROI: A, R5, R6 e R7 | -
;------------------------------------------------------------------------------

READ:
MOV | A,#0FEh ;inicia na coluna 0
MOV | R6,#4 ;R6 = contador
TEST_AGAIN:
MOV | P3,A
MOV | R7,A | ;guarda o conteudo do acumulador
MOV | A,P3 | ;le port3
ANL | A,#0F0h | ;usa apenas os valores das linhas
CJNE | A,#0F0h,CH_PRESS | ;alguma linha esta ativa?
MOV | A,R7 | ;nao -> move para a proxima coluna
RL | A
DJNZ | R6,TEST_AGAIN | ;nenhuma chave pressionada?
CLR | C | ;retorna com C=0
SJMP | FIN
CH_PRESS:
MOV | R7,A | ;salva o codigo da coluna em R7
MOV | A,#4 | ;prepara o calculo do peso da coluna
CLR | C
SUBB | A,R6 | ;4-R6 = peso da coluna
MOV | R6,A | ;guarda o resultado em R6
MOV | A,R7 | ;restaura a busca para A
SWAP | A | ;coloca o resultado da busca no nibble LS
MOV | R5,#4 | ;usa R5 como um contador
AGAIN:
RRC | A | ;rotaciona ate encontrar o bit 0
JNC | HEX | ;sai quando C=0
INC | R6 | ;adiciona 4...
INC | R6 | ;...
INC | R6 | ;...
INC | R6 | ;... ate encontrar a coluna
DJNZ | R5,AGAIN
HEX:
SETB | C | ;C=1 -> chave pressionada
MOV | A,R6 | ;codigo hex salvo em A
FIN:
RET

;==============================================================================
;= | SUBROTINAS PARA O DISPLAY LCD | =
;==============================================================================

;------------------------------------------------------------------------------
; INICIALIZACAO DO DISPLAY | -
;------------------------------------------------------------------------------
; ENTRADA: nenhuma | -
; SAIDA: nenhuma | -
; | -
; DESTROI: R6 | -
; CHAMA: IWRITE, CLEARLCD, DELAY | -
;------------------------------------------------------------------------------

INILCD:
CLR | P0.1 ;desabilita a escrita no display
MOV | R6,#50 ;gera atraso de 50x0,5ms = 25ms
LCALL DELAY
MOV B,#00110000b ;comando para inicializacao LCALL IWRITE
MOV R6,#9 ;gera atraso de 9x0,5ms = 4,5ms LCALL DELAY
LCALL IWRITE ;repete instrucao
MOV R6,#1 ;gera atraso de 1x0,5ms = 0,5ms LCALL DELAY
LCALL IWRITE ;repete instrucao

Ensitec - Profs. Gustavo B. Borba / Fernando E. Gazzoni | 21/34

; Configuracao do usuario

MOV B,#00111000b
;|||______ F = 0 -> matrizde 5x8 pontos ;||_______ N = 1-> 2 linhas ;|________ DL = 1 -> 8 bits

LCALL IWRITE

MOV B,#00001110b
;|||____ B = 0 -> local do cursor nao pisca ;||_____ C = 1 -> cursor visivel
;|______ D = 1 -> liga o display (aparece frase)

LCALL IWRITE

MOV B,#00000110b
;||____ SH=0 -> não desloca frase ao escrever caractere ;|_____ I/D = 1 -> cursor se move para direita

LCALL IWRITE

MOV B,#00000010b ;return home -> retorna o cursor para a... LCALL IWRITE ;...primeira linha e primeira coluna

LCALL CLEARLCD

RET

;------------------------------------------------------------------------------
; SUBROTINA PARA LIMPAR O DISPLAY | -
;------------------------------------------------------------------------------
; Apaga todos os caracteres e posiciona o cursor no inicio do display | -
;------------------------------------------------------------------------------
; ENTRADA: nenhuma | -
; SAIDA: nenhuma | -
; | -
; DESTROI: Caracteres armazenados da DDRAM, R6, A | -
; CHAMA: IWRITE, POSCURSOR, DELAY | -
;------------------------------------------------------------------------------

CLEARLCD:
PUSH | B
MOV | B,#00000001b ;Instrucao Clear display
LCALL IWRITE
MOV | R6,#3 ;atraso de 1,5ms -> tempo que a instrucao...
LCALL DELAY | ;...clear display leva para ser executada
MOV | B,#0 ;posiciona o cursor no inicio do display -> endereco 00h
LCALL POSCURSOR
POP B
RET

;------------------------------------------------------------------------------
; SUBROTINA PARA SELECIONAR A POSICAO DO CURSOR NO DISPLAY | -
;------------------------------------------------------------------------------
; ENTRADA: B --> endereco da DDRAM que o cursor sera posicionado | -
; SAIDA: nenhuma | -
; | -
; DESTROI: A | -
; CHAMA: IWRITE | -
;------------------------------------------------------------------------------

POSCURSOR:
PUSH | B
MOV | A,B
ORL | A,#10000000b
MOV | B,A
LCALL IWRITE
POP B
RET

;------------------------------------------------------------------------------

Ensitec - Profs. Gustavo B. Borba / Fernando E. Gazzoni | 22/34
; SUBROTINA PARA EXECUTAR INSTRUCOES NO DISPLAY | -
;------------------------------------------------------------------------------
; ENTRADA: B --> instrucao a ser executada | -
; SAIDA: nenhuma | -
; | -
; DESTROI: R7 | -
; CHAMA: runT0 | -
;------------------------------------------------------------------------------

IWRITE:
MOV | P1,B
CLR | P0.0 ;seleciona RS = 0 (instrucao)
SETB | P0.1 ;habilita escrita
MOV | R7,#18 ;aguarda 39us para...
DJNZ | R7,$ ;executar o comando
CLR | P0.1 ;desabilita escrita
RET

;------------------------------------------------------------------------------
; SUBROTINA PARA ESCREVER CARACTER ASCII NO DISPLAY | -
;------------------------------------------------------------------------------
; ENTRADA: B --> caractere (em ASCII) a ser escrito no display | -
; SAIDA: nenhuma | -
; | -
; DESTROI: R7 | -
; CHAMA: runT0 | -
;------------------------------------------------------------------------------

PRINTASCII:
MOV | P1,B
SETB | P0.0 ;seleciona RS = 1 (dado)
SETB | P0.1 ;habilita escrita
MOV | R7,#20 ;aguarda 43us para...
DJNZ | R7,$ ;... realizar a escrita
CLR | P0.1 ;desabilita escrita
RET

;------------------------------------------------------------------------------
; SUBROTINA PARA ESCREVER DIGITO BCD MENOS SIGNIFICATIVO | -
;------------------------------------------------------------------------------; Serao escritos caracteres indesejados se o numero nao estiver no formato BCD-;------------------------------------------------------------------------------
; ENTRADA: B --> numero BCD | -
; SAIDA: nenhuma | -
; | -
; DESTROI: A | -
; CHAMA: PRINTASCII | -
;------------------------------------------------------------------------------

PRINTBCDL:
PUSH | B ;armazena conteudo de B na pilha
MOV | A,B
ANL | A,#00001111b ;usa apenas 4bits menos significativo
ADD | A,#30h ;converte resultado para ASCII
MOV | B,A
LCALL PRINTASCII
POP B ;restaura conteudo de B da pilha RET

;------------------------------------------------------------------------------
; SUBROTINA PARA ESCREVER DOIS DIGITOS BCD | -
;------------------------------------------------------------------------------; Serao escritos caracteres indesejados se o numero nao estiver no formato BCD-;------------------------------------------------------------------------------
; ENTRADA: B --> numero BCD | -
; SAIDA: nenhuma | -
; | -
; DESTROI: A, B | -
; CHAMA: PRINTASCII | -
;------------------------------------------------------------------------------

Ensitec - Profs. Gustavo B. Borba / Fernando E. Gazzoni | 23/34

PRINTBCDHL:
PUSH | B ;armazena conteudo de B na pilha
MOV | A,B
ANL | A,#11110000b ;separa 4 bits mais significativos
SWAP | A ;troca nibble menos significativo por mais significativo
ADD | A,#30h ;converte para ASCII
MOV | B,A ;restaura conteudo de B da pilha
LCALL PRINTASCII
POP | B
MOV | A,B
ANL | A,#00001111b ;separa 4 bits menos significativos
ADD | A,#30h ;converte para ASCII
MOV | B,A
LCALL PRINTASCII
RET

;------------------------------------------------------------------------------
; SUBROTINA PARA ESCREVER DIGITO HEXADECIMAL MENOS SIGNIFICATIVO | -
;------------------------------------------------------------------------------
; ENTRADA: B --> numero HEXA | -
; SAIDA: nenhuma | -
; | -
; DESTROI: A, DPTR | -
; CHAMA: PRINTASCII | -
;------------------------------------------------------------------------------

PRINTHEXAL:
PUSH | B ;armazena conteudo de B na pilha
MOV | DPTR,#TABHEXA
MOV | A,B
ANL | A,#00001111b ;separa nibble menos significativo
MOVC | A,@A+DPTR ;converte caractere para ASCII
MOV | B,A
LCALL PRINTASCII
POP B ;restaura conteudo de B da pilha
RET

;------------------------------------------------------------------------------
; SUBROTINA PARA ESCREVER DOIS DIGITOS HEXADECIMAIS | -
;------------------------------------------------------------------------------
; ENTRADA: B --> numero HEXA | -
; SAIDA: nenhuma | -
; | -
; DESTROI: A, B, DPTR | -
; CHAMA: PRINTASCII | -
;------------------------------------------------------------------------------

PRINTHEXAHL:
PUSH | B ;armazena conteudo de B na pilha
MOV | DPTR,#TABHEXA
MOV | A,B
ANL | A,#11110000b ;separa nibble mais significativo
SWAP | A ;troca nibble menos significativo por mais significativo
MOVC | A,@A+DPTR ;converte caractere para ASCII
MOV | B,A
LCALL PRINTASCII
POP | B ;restaura conteudo de B da pilha
MOV | A,B
ANL | A,#00001111b ;separa nibble menos significativo
MOVC | A,@A+DPTR ;converte caractere para ASCII
MOV | B,A
LCALL PRINTASCII
RET

TABHEXA:
DB | '0123456789ABCDEF'

Ensitec - Profs. Gustavo B. Borba / Fernando E. Gazzoni | 24/34

;------------------------------------------------------------------------------
; SUBROTINA PARA ESCREVER FRASE EM APENAS UMA LINHA DO DISPLAY | -
;------------------------------------------------------------------------------
; ENTRADA: DPTR --> frase a ser escrita | -
; SAIDA: nenhuma | -
; | -
; DESTROI: A, R7 | -
; CHAMA: PRINTASCII | -
;------------------------------------------------------------------------------
; Caractere especial: '\' -> fim da frase | -
; | -
; Nao verifica se a frase cabe no display | -
; Precisa ser colocado o caractere '\' no final da frase | -
;------------------------------------------------------------------------------

PRINTSTRING:
PUSH | B ;armazena conteudo de B na pilha
MOV | R7,#0 ;inicia a escrita a partir da primeira letra da frase

PRINTS:
MOV | A,R7 ;converte o caractere hexadecimal...
MOVC | A,@A+DPTR ;... em ASCII
MOV | B,A
CJNE | A,#'\',WRITE ;encontrou o caractere '\' ?
POP | B | ;sim -> para de escrever
RET

WRITE:
LCALL PRINTASCII
INC | R7
JMP | PRINTS

;------------------------------------------------------------------------------
; SUBROTINA PARA ESCREVER FRASES NAS DUAS LINHAS DO DISPLAY | -
;------------------------------------------------------------------------------
; ENTRADA: DPTR --> frase a ser escrita | -
; SAIDA: nenhuma | -
; | -
; DESTROI: A, R7 | -
; CHAMA: PRINTASCII | -
;------------------------------------------------------------------------------
; Caracteres especiais: '/' -> quebra de linha (da primeira para a segunda) | -
; | '\' -> fim da frase | -
; | -
; Nao verifica se a frase cabe no display | -
; Precisa ser colocado o caractere '\' no final da frase | -
;------------------------------------------------------------------------------

PRINTSTRINGALL:
PUSH B ;armazena conteudo de B na pilha
LCALL CLEARLCD
MOV R7,#0 ;inicia a escrita a partir da primeira letra da frase

PRINTSALL:
MOV | A,R7 ;converte o caractere hexadecimal...
MOVC | A,@A+DPTR ;... em ASCII
MOV | B,A
CJNE | A,#'/',FIMSTR ;encontrou o caractere '/' ?
MOV | B,#40h ;sim -> comeca a escrever na segunda linha
LCALL POSCURSOR
INC | R7
JMP | PRINTSALL

WRITEALL:
LCALL PRINTASCII
INC | R7
JMP | PRINTSALL

FIMSTR:
CJNE A,#'\',WRITEALL ;encontrou o caractere '\'?

Ensitec - Profs. Gustavo B. Borba / Fernando E. Gazzoni | 25/34
POP | B | ;sim -> para de escrever
RET

;------------------------------------------------------------------------------
; SUBROTINA PARA DESLOCAR A FRASE A DIREITA | -
;------------------------------------------------------------------------------
; Desloca para a direita todos os caracteres ja escritos no display | -
;------------------------------------------------------------------------------
; ENTRADA: nenhuma | -
; SAIDA: nenhuma | -
; | -
; DESTROI: | -
; CHAMA: IWRITE | -
;------------------------------------------------------------------------------

SHIFTLCDR:
PUSH | B ;armazena conteudo de B na pilha
MOV | B,#00011100b
LCALL IWRITE
POP B ;restaura conteudo de B na pilha RET

;------------------------------------------------------------------------------
; SUBROTINA PARA DESLOCAR A FRASE A ESQUERDA | -
;------------------------------------------------------------------------------
; Desloca para a esquerda todos os caracteres ja escritos no display | -
;------------------------------------------------------------------------------
; ENTRADA: nenhuma | -
; SAIDA: nenhuma | -
; | -
; DESTROI: B | -
; CHAMA: IWRITE | -
;------------------------------------------------------------------------------

SHIFTLCDL:
PUSH | B ;armazena conteudo de B na pilha
MOV | B,#00011000b
LCALL IWRITE
POP B ;restaura conteudo de B na pilha RET
;------------------------------------------------------------------------------
; SUBROTINA PARA GERAR ATRASO DE R1 x 0,5ms | -
;------------------------------------------------------------------------------
; ENTRADA: R6 --> valor a ser multiplicado pela base de tempo | -
; | -
; SAIDA: nenhuma | -
; | -
; DESTROI: R7, R6 | -
;------------------------------------------------------------------------------

DELAY:
MOV | R7,#228
DJNZ | R7,$
DJNZ | R6,DELAY
RET

END

## Exemplo 5

;==============================================================================
;= AUTOR: FERNANDO GAZZONI/GUSTAVO BORBA | DATA:05/2008 | ARQUIVO:clock.a51 | =
;= CPU: AT89S51 | clk: 11,059200MHz | =
;==============================================================================
;= | RELOGIO DIGITAL | =

Ensitec - Profs. Gustavo B. Borba / Fernando E. Gazzoni | 26/34

;------------------------------------------------------------------------------
;= | USA AS FUNCOES DO LCD | =
;==============================================================================
;CH0 --> Ajusta relogio | =
;CH1 --> Inicia o relogio | =
; | =
; --> Dentro do menu de ajuste: | =
;CHO --> Confirma ajuste | =
;CH1 --> Connfigura as horas | =
;CH2 --> Configura os minutos | =
;CH3 --> Zera o relogio (00:00:00) | =
;==============================================================================

;------------------------------------------------------------------------------
; | VARIAVEIS DO RELOGIO | -
;------------------------------------------------------------------------------
HORA | EQU | 40h ;armazena as horas
MINUTO | EQU | 41h ;armazena os minutos
SEGUNDO | EQU | 42h ;armazena os segundos
TESTE | EQU | 43h ;testa se passou 1seg para atualizar o relogio

;------------------------------------------------------------------------------
; | INICIO DO PROGRAMA E CONFIGURACAO DA INTERRUPCAO DO TIMER 1 | -
;------------------------------------------------------------------------------
ORG | 0000h ; reset do sistema
LJMP | INICIO
ORG | 001Bh ; interrupcao timer 1
MOV | TH1,#4Ch ; recarrega TH1
INC | TESTE
MOV | A,TESTE
CJNE | A,#20,FIM ;se teste = 20 x 50ms = 1 segundo...
MOV | TESTE,#0 ;... reinicia variavel teste e...
LCALL RELOGIO ;... atualiza relogio
FIM:
RETI

;------------------------------------------------------------------------------
; | INICIALIZACAO: APENAS INT TIMER 1 HABILITADA, PRIORIDADE ALTA | -
;------------------------------------------------------------------------------

ORG 0050h
INICIO:

MOV IE,#00000000B ;desabilita todas as interrupcoes

MOV TCON,#00000000B
; ||||_______ TR0 = 0 -> timer 0 parado
; |||________ TF0 = 0 -> flag de overflow do T/C 0 zerado ; ||_________ TR1 = 0 -> timer 0 parado
; |__________ TF1 = 0 -> flag de overflow do T/C 0 zerado

MOV TMOD,#00010000B
; ||||___ M0 = 1 -> timer 1 no...
; |||____ M1 = 0 -> ...modo 1: 16 bits
; ||_____ C/T'= 0 -> timer 1 na funcao timer
; |______ GATE= 0 -> timer 1 controlado somente por TR0 ;T/C 1 nao utilizado

MOV IP,#00001000b
; |__ PT1 = 1 -> prioridade para a int do timer 1
MOV | IE,#10001000b
;| | |__ ET1 = 1 -> habilita a int do timer 1
;|____ EA = 1 -> habilita todas as ints que... ; ...estiverem habilitadas

;------------------------------------------------------------------------------
; SUBROTINA DE INICALIZACAO DO DISPLAY | -
;------------------------------------------------------------------------------

Ensitec - Profs. Gustavo B. Borba / Fernando E. Gazzoni | 27/34

LCALL INILCD

;------------------------------------------------------------------------------
; PROGRAMA PRINCIPAL | -
;------------------------------------------------------------------------------

LCALL ZERA

CHAVE0:
MOV | A,P3
CJNE | A,#11111110b,START ;AJUSTAR O RELOGIO?
CLR | TR1
SOLTA:
MOV | A,P3
CJNE | A,#11111111b,SOLTA ;INICIAR O RELOGIO?
LCALL AJUSTE
LJMP CHAVE0
START:
CJNE A,#11111101b,CHAVE0 ;INICIAR O RELOGIO? LCALL TIMER1
LJMP CHAVE0

;------------------------------------------------------------------------------
;SUBROTINA PARA TRATAMENTO DA INTERRUPCAO EXTERNA 0 | -
;------------------------------------------------------------------------------

AJUSTE:
MOV | R0,P3
CJNE | R0,#11111110b,CHAVE1 ; terminou ajuste?
TERMINAAJUSTE:
MOV | R0,P3
CJNE | R0,#11111111b,TERMINAAJUSTE ; verifica se chave 0 foi solta
RET
CHAVE1:
CJNE | R0,#11111101b,CHAVE2 ; se chave 1 pressionada...
LCALL AJUSTEHORA | ; ...incrementa hora
SOLTAHORA:
MOV | R0,P3
CJNE | R0,#11111111b,SOLTAHORA | ; verifica se chave 1 foi solta
LJMP | AJUSTE
CHAVE2:
CJNE | R0,#11111011b,CHAVE3 | ; se chave 0 pressionada...
LCALL AJUSTEMIN | ; ...incrementa minuto
SOLTAMIN:
MOV | R0,P3
CJNE | R0,#11111111b,SOLTAMIN | ; verifica se chave 2 foi solta
LJMP | AJUSTE
CHAVE3:
CJNE | R0,#11110111b,AJUSTE ; se chave 2 pressionada...
LCALL ZERA | ; ... zera o relogio
SOLTAZERA:
MOV | R0,P3
CJNE | R0,#11111111b,SOLTAZERA | ; verifica se chave 3 foi solta
LJMP | AJUSTE

;------------------------------------------------------------------------------
;AJUSTE DAS HORAS E MINUTOS | -
;------------------------------------------------------------------------------

AJUSTEHORA:
MOV | A,HORA | ;aumenta 1 hora e...
ADD | A,#1 | ;... ajusta o numero hexa ...
DA | A | ; ...para o formato BCD
MOV | HORA,A | ; atualiza a variavel hora
CJNE | A,#24h,ATUALIZAHORA ;se hora = 24...
MOV | HORA,#00h | ;... zera hora
ATUALIZAHORA:
LCALL HOR
RET

Ensitec - Profs. Gustavo B. Borba / Fernando E. Gazzoni | 28/34

AJUSTEMIN:
MOV | A,MINUTO | ;aumenta 1 minuto e...
ADD | A,#1 | ;... ajusta o numero hexa ...
DA | A | ; ...para o formato BCD
MOV | MINUTO,A | ; atualiza a variavel minuto
CJNE | A,#60h,ATUALIZAMIN ;se minuto = 60...
MOV | MINUTO,#00h | ; zera minuto
ATUALIZAMIN:
LCALL MIN
RET

;------------------------------------------------------------------------------
;TRTAMENTO DA INTERRUPCAO DO TIMER --> SUBROTINA DO RELOGIO | -
;------------------------------------------------------------------------------

RELOGIO:
MOV | A,SEGUNDO ;aumenta 1 segundo e...
ADD | A,#1 | ;... ajusta o numero hexa ...
DA | A | ; ...para o formato BCD
MOV | SEGUNDO,A ; atualiza a variavel segundo
CJNE | A,#60h,SEG | ;se segundo = 60...
MOV | SEGUNDO,#00h ;... zera os segundos e aumenta os minutos
SOMAMIN:
MOV | A,MINUTO | ;aumenta 1 minuto e...
ADD | A,#1 | ;... ajusta o numero hexa ...
DA | A | ; ...para o formato BCD
MOV | MINUTO,A | ; atualiza a variavel minuto
CJNE | A,#60h,MIN | ;se minuto = 60...
MOV | MINUTO,#00h ;... zera os minutos e aumenta as horas
SOMAHORA:
MOV | A,HORA | ;aumenta 1 hora e...
ADD | A,#1 | ;... ajusta o numero hexa ...
DA | A | ; ...para o formato BCD
MOV | HORA,A | ; atualiza a variavel hora
CJNE | A,#24h,HOR ;se hora = 24: chama a rotina para...
LCALL ZERA | ;... colocar o relogio em 00:00:00
RET

;------------------------------------------------------------------------------
; ATUALIZACAO DO RELOGIO NO DISPLAY LCD | -
;------------------------------------------------------------------------------

SEG:
MOV | B,#0Ah | ;atualiza o valor...
LCALL POSCURSOR | ;... dos segundos...
MOV | B,SEGUNDO | ;... no display LCD
LCALL PRINTBCDHL
RET
MIN:
MOV | B,#07h
LCALL POSCURSOR | ;atualiza o valor...
MOV | B,MINUTO | ;... dos minutos...
LCALL PRINTBCDHL ;... no display LCD JMP SEG
HOR:
MOV | B,#04h
LCALL POSCURSOR | ;atualiza o valor...
MOV | B,HORA | ;... das horas...
LCALL PRINTBCDHL ;... no display LCD JMP MIN

;------------------------------------------------------------------------------
; SUBROTINA PARA ZERAR O RELOGIO | -
;------------------------------------------------------------------------------ZERA:
MOV | HORA,#00h | ;zera variavel hora
MOV | MINUTO,#00h | ;zera variavel minuto
MOV | SEGUNDO,#00h ;zera variavel segundo
MOV | TESTE,#00h | ;zera variavel teste
MOV | B,#04h | ;ajusta a posicao do cursor para o relogio...
LCALL POSCURSOR ;... ficar no meio do display

Ensitec - Profs. Gustavo B. Borba / Fernando E. Gazzoni | 29/34
MOV | DPTR,#MEIANOITE ;escreve a frase...
LCALL PRINTSTRING | ;...meia noite no display
RET

MEIANOITE:
DB | '00:00:00\'

;------------------------------------------------------------------------------
;SUBROTINA PARA LIGAR TIMER 1 COM ATRASO DE 50ms | -
;------------------------------------------------------------------------------

TIMER1:
MOV | TH1,#4Ch ; fclk CPU = 11059200Hz -> 46.080 x 1,085us...
MOV | TL1,#00h ; ... base de tempo de 50ms
SETB | TR1 | ; dispara timer
RET

;==============================================================================
;= | SUBROTINAS PARA O DISPLAY LCD | =
;==============================================================================

;------------------------------------------------------------------------------
; INICIALIZACAO DO DISPLAY | -
;------------------------------------------------------------------------------
; ENTRADA: nenhuma | -
; SAIDA: nenhuma | -
; | -
; DESTROI: R1 | -
; CHAMA: IWRITE, CLEARLCD, DELAY | -
;------------------------------------------------------------------------------

INILCD:
CLR | P0.1 | ;desabilita a escrita no display
MOV | R6,#50 ;gera atraso de 50x0,5ms = 25ms
LCALL DELAY
MOV B,#00110000b ;comando para inicializacao LCALL IWRITE
MOV | R6,#9 | ;gera atraso de 9x0,5ms = 4,5ms
LCALL DELAY
LCALL IWRITE ;repete instrucao
MOV | R6,#1 | ;gera atraso de 1x0,5ms = 0,5ms
LCALL DELAY
LCALL IWRITE ;repete instrucao

; Configuracao do usuario

MOV B,#00111000b
;|||______ F = 0 -> matrizde 5x8 pontos ;||_______ N = 1-> 2 linhas ;|________ DL = 1 -> 8 bits
LCALL IWRITE

MOV B,#00001110b
;|||____ B = 0 -> local do cursor nao pisca ;||_____ C = 1 -> cursor visivel
;|______ D = 1 -> liga o display (aparece frase) LCALL IWRITE

MOV B,#00000110b
;||____ SH=0 -> não desloca frase ao escrever caractere ;|_____ I/D = 1 -> cursor se move para direita
LCALL IWRITE

LCALL CLEARLCD
RET

;------------------------------------------------------------------------------
; SUBROTINA PARA LIMPAR O DISPLAY | -
;------------------------------------------------------------------------------
; Apaga todos os caracteres e posiciona o cursor no inicio do display | -
;------------------------------------------------------------------------------
; ENTRADA: nenhuma | -

Ensitec - Profs. Gustavo B. Borba / Fernando E. Gazzoni | 30/34
; SAIDA: nenhuma | | -
; | -
; DESTROI: Caracteres armazenados da DDRAM, R6, A | -
; CHAMA: IWRITE, POSCURSOR, DELAY | -
;------------------------------------------------------------------------------

CLEARLCD:
PUSH | B
MOV | B,#00000001b ;Instrucao Clear display
LCALL IWRITE
MOV | R6,#3 | ;atraso de 1,5ms -> tempo que a instrucao...
LCALL DELAY | ;...clear display leva para ser executada
MOV | B,#0 | ;posiciona o cursor no inicio do display -> endereco 00h
LCALL POSCURSOR
POP B
RET

;------------------------------------------------------------------------------
; SUBROTINA PARA SELECIONAR A POSICAO DO CURSOR NO DISPLAY | -
;------------------------------------------------------------------------------
; ENTRADA: B --> endereco da DDRAM que o cursor sera posicionado | -
; SAIDA: nenhuma | | -
; | -
; DESTROI: A, B | | -
; CHAMA: IWRITE | | -
;------------------------------------------------------------------------------

POSCURSOR:
PUSH | B ;armazena o valor de B na pilha
MOV | A,B
ORL | A,#10000000b
MOV | B,A
LCALL IWRITE
POP B ;restaura o valor de B RET

;------------------------------------------------------------------------------
; SUBROTINA PARA EXECUTAR INSTRUCOES NO DISPLAY | -
;------------------------------------------------------------------------------
; ENTRADA: B --> instrucao a ser executada | -
; SAIDA: nenhuma | | -
; | -
; DESTROI: R7 | | -
; CHAMA: runT0 | | -
;------------------------------------------------------------------------------

IWRITE:
MOV | P1,B
CLR | P0.0 ;seleciona RS = 0 (instrucao)
SETB | P0.1 ;habilita escrita
MOV | R7,#18 ;aguarda 39us para...
DJNZ | R7,$ ;executar o comando
CLR | P0.1 ;desabilita escrita
RET

;------------------------------------------------------------------------------
; SUBROTINA PARA ESCREVER CARACTER ASCII NO DISPLAY | -
;------------------------------------------------------------------------------
; ENTRADA: B --> caractere (em ASCII) a ser escrito no display | -
; SAIDA: nenhuma | | -
; | -
; DESTROI: R7 | | -
; CHAMA: runT0 | | -
;------------------------------------------------------------------------------

PRINTASCII:
MOV | P1,B
SETB | P0.0 ;seleciona RS = 1 (dado)
SETB | P0.1 ;habilita escrita
MOV | R7,#20 ;aguarda 43us para...
DJNZ | R7,$ ;... realizar a escrita
CLR | P0.1 ;desabilita escrita

Ensitec - Profs. Gustavo B. Borba / Fernando E. Gazzoni | 31/34

RET

;------------------------------------------------------------------------------
; SUBROTINA PARA ESCREVER DIGITO BCD MENOS SIGNIFICATIVO | -
;------------------------------------------------------------------------------; Serao escritos caracteres indesejados se o numero nao estiver no formato BCD-;------------------------------------------------------------------------------
; ENTRADA: B --> numero BCD | -
; SAIDA: nenhuma | -
; | -
; DESTROI: A | -
; CHAMA: PRINTASCII | -
;------------------------------------------------------------------------------

PRINTBCDL:
PUSH | B ;armazena conteudo de B na pilha
MOV | A,B
ANL | A,#00001111b ;usa apenas 4bits menos significativo
ADD | A,#30h ;converte resultado para ASCII
MOV | B,A
LCALL PRINTASCII
POP B ;restaura conteudo de B da pilha RET

;------------------------------------------------------------------------------
; SUBROTINA PARA ESCREVER DOIS DIGITOS BCD | -
;------------------------------------------------------------------------------; Serao escritos caracteres indesejados se o numero nao estiver no formato BCD-;------------------------------------------------------------------------------
; ENTRADA: B --> numero BCD | -
; SAIDA: nenhuma | -
; | -
; DESTROI: A, B | -
; CHAMA: PRINTASCII | -
;------------------------------------------------------------------------------PRINTBCDHL:
PUSH | B ;armazena conteudo de B na pilha
MOV | A,B
ANL | A,#11110000b ;separa 4 bits mais significativos
SWAP | A ;troca nibble menos significativo por mais significativo
ADD | A,#30h ;converte para ASCII
MOV | B,A ;restaura conteudo de B da pilha
LCALL PRINTASCII
POP | B
MOV | A,B
ANL | A,#00001111b ;separa 4 bits menos significativos
ADD | A,#30h ;converte para ASCII
MOV | B,A
LCALL PRINTASCII
RET

;------------------------------------------------------------------------------
; SUBROTINA PARA ESCREVER DIGITO HEXADECIMAL MENOS SIGNIFICATIVO | -
;------------------------------------------------------------------------------
; ENTRADA: B --> numero HEXA | -
; SAIDA: nenhuma | -
; | -
; DESTROI: A, DPTR | -
; CHAMA: PRINTASCII | -
;------------------------------------------------------------------------------

PRINTHEXAL:
PUSH | B ;armazena conteudo de B na pilha
MOV | DPTR,#TABHEXA
MOV | A,B
ANL | A,#00001111b ;separa nibble menos significativo
MOVC | A,@A+DPTR ;converte caractere para ASCII
MOV | B,A
LCALL PRINTASCII
POP B ;restaura conteudo de B da pilha
RET

Ensitec - Profs. Gustavo B. Borba / Fernando E. Gazzoni | 32/34

;------------------------------------------------------------------------------
; SUBROTINA PARA ESCREVER DOIS DIGITOS HEXADECIMAIS | -
;------------------------------------------------------------------------------
; ENTRADA: B --> numero HEXA | -
; SAIDA: nenhuma | -
; | -
; DESTROI: A, DPTR | -
; CHAMA: PRINTASCII | -
;------------------------------------------------------------------------------

PRINTHEXAHL:
PUSH | B ;armazena conteudo de B na pilha
MOV | DPTR,#TABHEXA
MOV | A,B
ANL | A,#11110000b ;separa nibble mais significativo
SWAP | A ;troca nibble menos significativo por mais significativo
MOVC | A,@A+DPTR ;converte caractere para ASCII
MOV | B,A
LCALL PRINTASCII
POP | B ;restaura conteudo de B da pilha
MOV | A,B
ANL | A,#00001111b ;separa nibble menos significativo
MOVC | A,@A+DPTR ;converte caractere para ASCII
MOV | B,A
LCALL PRINTASCII
RET

TABHEXA:
DB | '0123456789ABCDEF'

;------------------------------------------------------------------------------
; SUBROTINA PARA ESCREVER FRASE EM APENAS UMA LINHA DO DISPLAY | -
;------------------------------------------------------------------------------
; ENTRADA: DPTR --> frase a ser escrita | -
; SAIDA: nenhuma | -
; | -
; DESTROI: A, R0 | -
; CHAMA: PRINTASCII | -
;------------------------------------------------------------------------------
; Caractere especial: '\' -> fim da frase | -
; | -
; Nao verifica se a frase cabe no display | -
; Precisa ser colocado o caractere '\' no final da frase | -
;------------------------------------------------------------------------------

PRINTSTRING:
PUSH | B ;armazena conteudo de B na pilha
MOV | R0,#0 ;inicia a escrita a partir da primeira letra da frase

PRINTS:
MOV | A,R0 ;converte o caractere hexadecimal...
MOVC | A,@A+DPTR ;... em ASCII
MOV | B,A
CJNE | A,#'\',WRITE ;encontrou o caractere '\' ?
POP | B | ;sim -> para de escrever
RET

WRITE:
LCALL PRINTASCII
INC | R0
JMP | PRINTS

;------------------------------------------------------------------------------
; SUBROTINA PARA ESCREVER FRASES NAS DUAS LINHAS DO DISPLAY | -
;------------------------------------------------------------------------------
; ENTRADA: DPTR --> frase a ser escrita | -
; SAIDA: nenhuma | -
; | -
; DESTROI: A, R0 | -
; CHAMA: PRINTASCII | -
;------------------------------------------------------------------------------

Ensitec - Profs. Gustavo B. Borba / Fernando E. Gazzoni | 33/34
; Caracteres especiais: '/' -> quebra de linha (da primeira para a segunda) | -
; | '\' -> fim da frase | -
; | -
; Nao verifica se a frase cabe no display | -
; Precisa ser colocado o caractere '\' no final da frase | -
;------------------------------------------------------------------------------

PRINTSTRINGALL:
PUSH B ;armazena conteudo de B na pilha
LCALL CLEARLCD
MOV R0,#0 ;inicia a escrita a partir da primeira letra da frase

PRINTSALL:
MOV | A,R0 ;converte o caractere hexadecimal...
MOVC | A,@A+DPTR ;... em ASCII
MOV | B,A
CJNE | A,#'/',FIMSTR ;encontrou o caractere '/' ?
MOV | B,#40h ;sim -> comeca a escrever na segunda linha
LCALL POSCURSOR
INC | R0
JMP | PRINTSALL

WRITEALL:
LCALL PRINTASCII
INC | R0
JMP | PRINTSALL

FIMSTR:
CJNE | A,#'\',WRITEALL ;encontrou o caractere '\'?
POP | B | ;sim -> para de escrever
RET

;------------------------------------------------------------------------------
; SUBROTINA PARA DESLOCAR A FRASE A DIREITA | -
;------------------------------------------------------------------------------
; Desloca para a direita todos os caracteres ja escritos no display | -
;------------------------------------------------------------------------------
; ENTRADA: nenhuma | -
; SAIDA: nenhuma | -
; | -
; DESTROI: | -
; CHAMA: IWRITE | -
;------------------------------------------------------------------------------

SHIFTLCDR:
PUSH | B ;armazena conteudo de B na pilha
MOV | B,#00011100b
LCALL IWRITE
POP B ;restaura conteudo de B na pilha RET

;------------------------------------------------------------------------------
; SUBROTINA PARA DESLOCAR A FRASE A ESQUERDA | -
;------------------------------------------------------------------------------
; Desloca para a esquerda todos os caracteres ja escritos no display | -
;------------------------------------------------------------------------------
; ENTRADA: nenhuma | -
; SAIDA: nenhuma | -
; | -
; DESTROI: B | -
; CHAMA: IWRITE | -
;------------------------------------------------------------------------------

SHIFTLCDL:
PUSH | B ;armazena conteudo de B na pilha
MOV | B,#00011000b
LCALL IWRITE
POP B ;restaura conteudo de B na pilha RET

Ensitec - Profs. Gustavo B. Borba / Fernando E. Gazzoni | 34/34

;------------------------------------------------------------------------------
; SUBROTINA PARA GERAR ATRASO DE R1 x 0,5ms | -
;------------------------------------------------------------------------------
; ENTRADA: R6 --> valor a ser multiplicado pela base de tempo | -
; | -
; SAIDA: nenhuma | -
; | -
; DESTROI: R7, R6 | -
;------------------------------------------------------------------------------

DELAY:
MOV | R7,#228
DJNZ | R7,$
DJNZ | R6,DELAY
RET

END

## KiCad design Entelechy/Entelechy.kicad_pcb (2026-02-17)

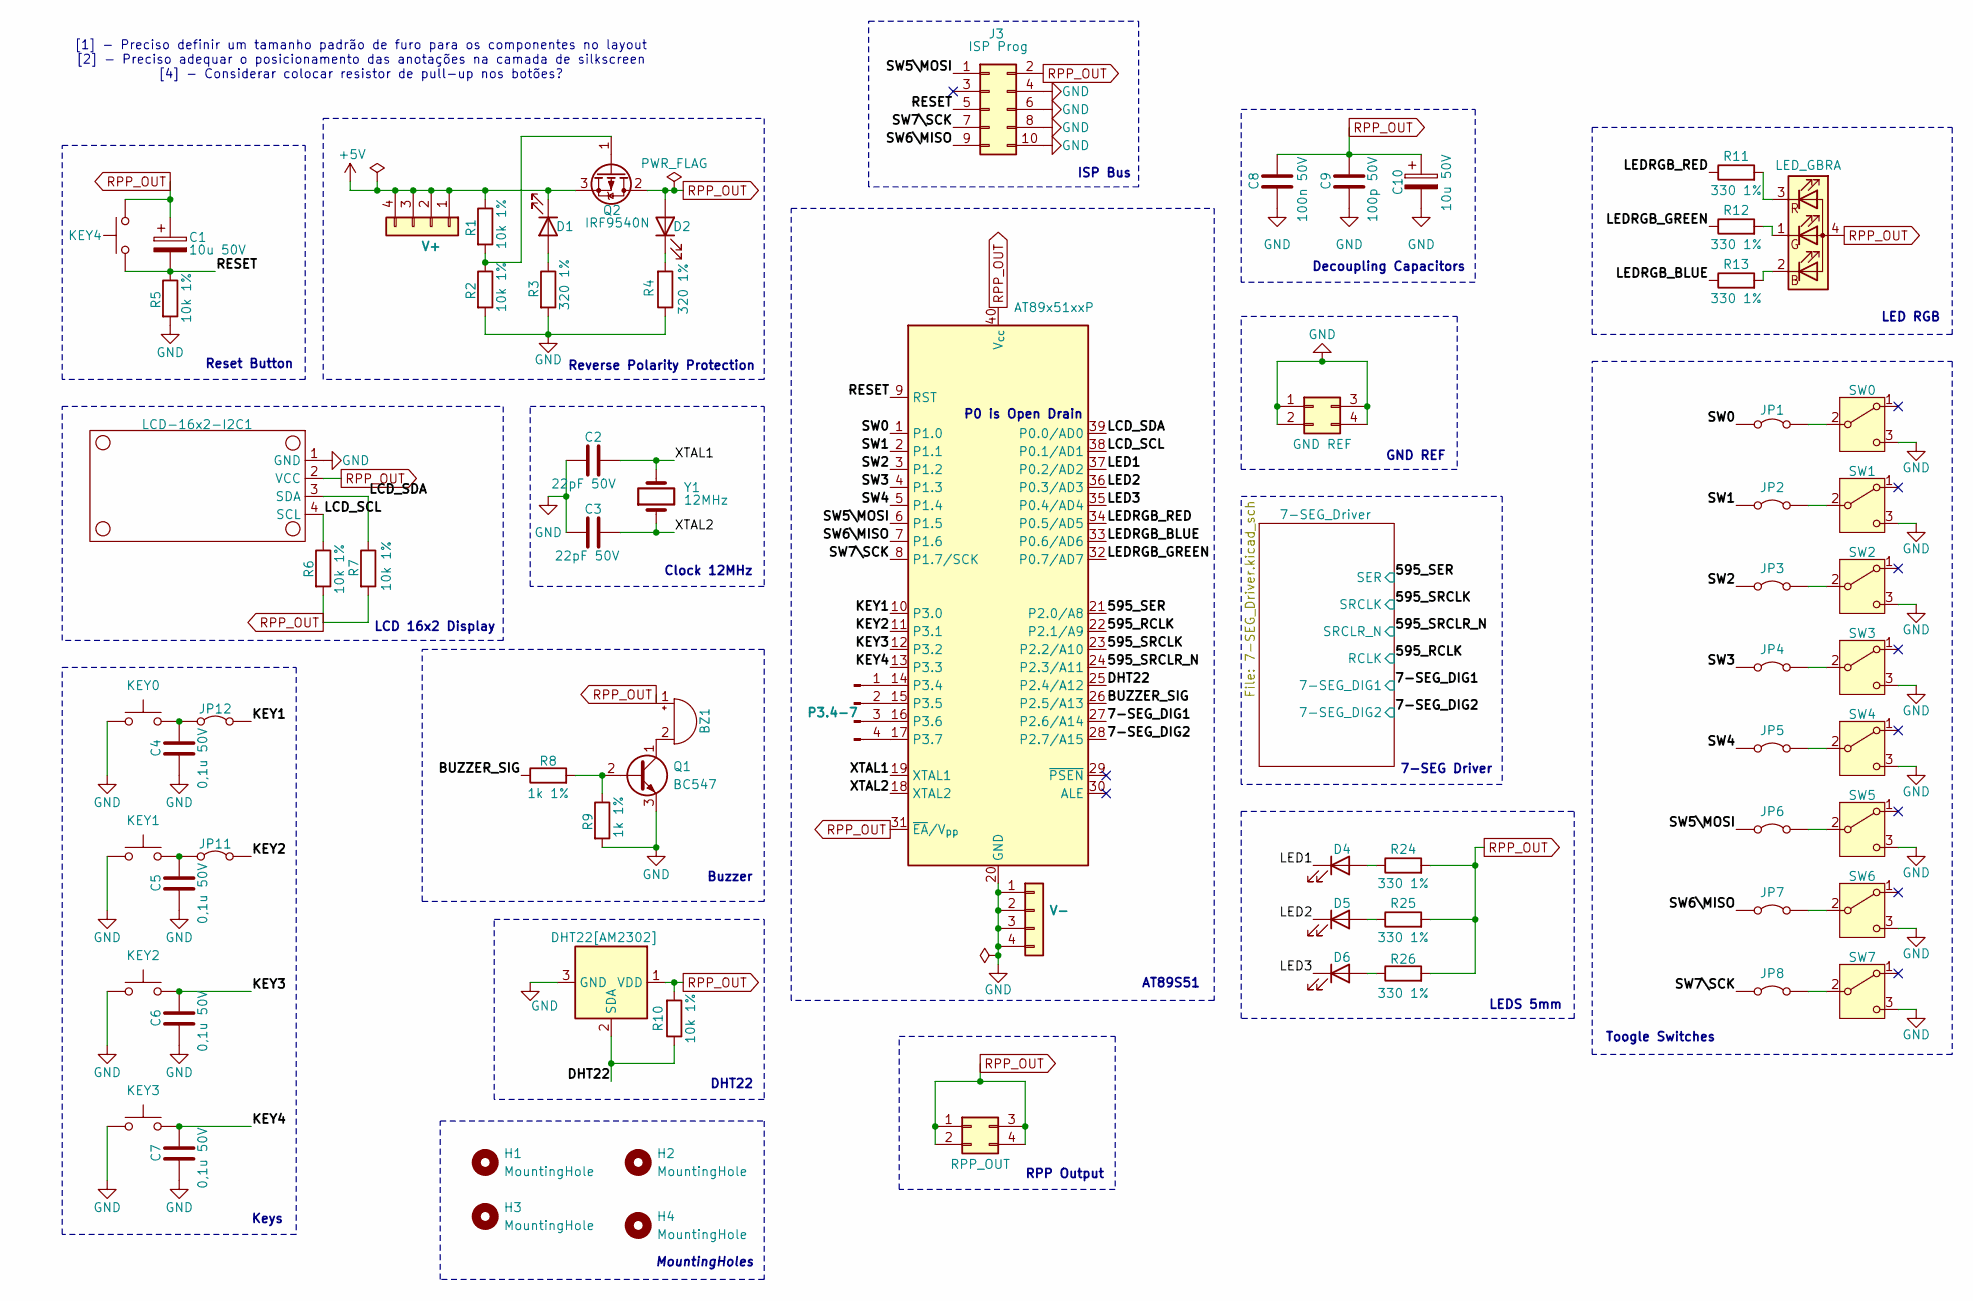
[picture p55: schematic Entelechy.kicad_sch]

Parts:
BZ1: Buzzer; Buzzer_12x9.5RM7.6
C1, C10: 10u 50V; CP_Radial_D5.0mm_P2.50mm
C2, C3: 22pF 50V; C_Disc_D3.0mm_W1.6mm_P2.50mm
C4, C5, C6, C7: 0,1u 50V; C_Disc_D3.0mm_W1.6mm_P2.50mm
C8: 100n 50V; C_Disc_D3.0mm_W1.6mm_P2.50mm
C9: 100p 50V; C_Disc_D3.0mm_W1.6mm_P2.50mm
D1, D2, D4, D5, D6: LED; LED_D5.0mm
D3: LED_GBRA; LED_D5.0mm-4_RGB_Wide_Pins
H1, H2, H3, H4: MountingHole; MountingHole_3.2mm_M3_ISO7380_Pad
J1: RPP_OUT; PinHeader_2x02_P2.54mm_Vertical
J2: GND REF; PinHeader_2x02_P2.54mm_Vertical
J3: ISP Prog; IDC-Header_2x05_P2.54mm_Vertical
J4: V+; PinHeader_1x04_P2.54mm_Vertical
J5: V-; PinHeader_1x04_P2.54mm_Vertical
JP1: P1.0; PinHeader_1x02_P2.54mm_Vertical
JP2: P1.1; PinHeader_1x02_P2.54mm_Vertical
JP3: P1.2; PinHeader_1x02_P2.54mm_Vertical
JP4: P1.3; PinHeader_1x02_P2.54mm_Vertical
JP5: P1.4; PinHeader_1x02_P2.54mm_Vertical
JP6: P1.5; PinHeader_1x02_P2.54mm_Vertical
JP7: P1.6; PinHeader_1x02_P2.54mm_Vertical
JP8: P1.7; PinHeader_1x02_P2.54mm_Vertical
JP11: P3.1; PinHeader_1x02_P2.54mm_Vertical
JP12: P3.0; PinHeader_1x02_P2.54mm_Vertical
KEY0, KEY1, KEY2, KEY3: SW_Push; SW_BUTT-2
KEY4: RESET; SW_BUTT-2
LCD-16x2-I2C1: LCD-16x2-I2C; LCD_16x2_I2C
P3.4-7: P3.4-7; PinHeader_1x04_P2.54mm_Vertical
Q1: BC547; TO-92-3_ONS
Q2: IRF9540N; TO-220-3_Horizontal_TabDown
R1, R2, R5, R6, R7, R10: 10k 1%; R_Axial_DIN0207_L6.3mm_D2.5mm_P7.62mm_Horizontal
R3, R4: 320 1%; R_Axial_DIN0207_L6.3mm_D2.5mm_P7.62mm_Horizontal
R8, R9: 1k 1%; R_Axial_DIN0207_L6.3mm_D2.5mm_P7.62mm_Horizontal
R11, R12, R13, R24, R25, R26: 330 1%; R_Axial_DIN0207_L6.3mm_D2.5mm_P7.62mm_Horizontal
SW0, SW1, SW2, SW3, SW4, SW5, SW6, SW7: SW_SPDT; SLW-116641-5A-S-D
U1: DHT22[AM2302]; ASAIR_AM2302_P2.54mm_Vertical
U2: AT89x51xxP; DIP-40_W15.24mm
Y1: 12MHz; Crystal_HC52-8mm_Vertical

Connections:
+5V: D1.1 (K), J4.1, J4.2, J4.3, J4.4, Q2.3 (S), R1.1
/7-SEG_DIG1: U2.27 (P2.6/A14); also elsewhere on the board
/7-SEG_DIG2: U2.28 (P2.7/A15); also elsewhere on the board
/595_RCLK: U2.22 (P2.1/A9); also elsewhere on the board
/595_SER: U2.21 (P2.0/A8); also elsewhere on the board
/595_SRCLK: U2.23 (P2.2/A10); also elsewhere on the board
/595_SRCLR_N: U2.24 (P2.3/A11); also elsewhere on the board
/BUZZER_SIG: R8.1, U2.26 (P2.5/A13)
/DHT22: R10.1, U1.2 (SDA), U2.25 (P2.4/A12)
/KEY1: JP12.1 (A), U2.10 (P3.0)
/KEY2: JP11.1 (A), U2.11 (P3.1)
/KEY3: C6.1, KEY2.1, U2.12 (P3.2)
/KEY4: C7.1, KEY3.1, U2.13 (P3.3)
/LCD_SCL: LCD-16x2-I2C1.4 (SCL), R6.1, U2.38 (P0.1/AD1)
/LCD_SDA: LCD-16x2-I2C1.3 (SDA), R7.1, U2.39 (P0.0/AD0)
/LED1: D4.1 (K), U2.37 (P0.2/AD2)
/LED2: D5.1 (K), U2.36 (P0.3/AD3)
/LED3: D6.1 (K), U2.35 (P0.4/AD4)
/LEDRGB_BLUE: R13.1, U2.33 (P0.6/AD6)
/LEDRGB_GREEN: R12.1, U2.32 (P0.7/AD7)
/LEDRGB_RED: R11.1, U2.34 (P0.5/AD5)
/RESET: C1.2, J3.5, KEY4.1, R5.1, U2.9 (RST)
/SW0: JP1.1 (A), U2.1 (P1.0)
/SW1: JP2.1 (A), U2.2 (P1.1)
/SW2: JP3.1 (A), U2.3 (P1.2)
/SW3: JP4.1 (A), U2.4 (P1.3)
/SW4: JP5.1 (A), U2.5 (P1.4)
/SW5\MOSI: J3.1, JP6.1 (A), U2.6 (P1.5)
/SW6\MISO: J3.9, JP7.1 (A), U2.7 (P1.6)
/SW7\SCK: J3.7, JP8.1 (A), U2.8 (P1.7/SCK)
/XTAL1: C2.2, U2.19 (XTAL1), Y1.2
/XTAL2: C3.2, U2.18 (XTAL2), Y1.1
GND: C2.1, C3.1, C4.2, C5.2, C6.2, C7.2, C8.2, C9.2, C10.2, J2.1, J2.2, J2.3, J2.4, J3.4, J3.6, J3.8, J3.10, J5.1, J5.2, J5.3, J5.4, KEY0.2, KEY1.2, KEY2.2, KEY3.2, LCD-16x2-I2C1.1 (GND), Q1.3 (E), R2.2, R3.2, R4.1, R5.2, R9.2, SW0.3 (C), SW1.3 (C), SW2.3 (C), SW3.3 (C), SW4.3 (C), SW5.3 (C), SW6.3 (C), SW7.3 (C), U1.3 (GND), U1.4 (GND), U2.20 (GND); also elsewhere on the board
unnamed: BZ1.2 (-), Q1.1 (C)
unnamed: D1.2 (A), R3.1
unnamed: D2.1 (K), R4.2
unnamed: D3.2 (BK), R13.2
unnamed: D3.1 (GK), R12.2
unnamed: D3.3 (RK), R11.2
unnamed: D4.2 (A), R24.1
unnamed: D5.2 (A), R25.1
unnamed: D6.2 (A), R26.1
unnamed: JP1.2 (B), SW0.2 (B)
unnamed: JP2.2 (B), SW1.2 (B)
unnamed: JP3.2 (B), SW2.2 (B)
unnamed: JP4.2 (B), SW3.2 (B)
unnamed: JP5.2 (B), SW4.2 (B)
unnamed: JP6.2 (B), SW5.2 (B)
unnamed: JP7.2 (B), SW6.2 (B)
unnamed: JP8.2 (B), SW7.2 (B)
unnamed: C5.1, JP11.2 (B), KEY1.1
unnamed: C4.1, JP12.2 (B), KEY0.1
unnamed: P3.4-7.1, U2.14 (P3.4)
unnamed: P3.4-7.2, U2.15 (P3.5)
unnamed: P3.4-7.3, U2.16 (P3.6)
unnamed: P3.4-7.4, U2.17 (P3.7)
unnamed: Q1.2 (B), R8.2, R9.1
unnamed: Q2.1 (G), R1.2, R2.1
RPP_OUT: BZ1.1 (+), C1.1, C8.1, C9.1, C10.1, D2.2 (A), D3.4 (A), J1.1, J1.2, J1.3, J1.4, J3.2, KEY4.2, LCD-16x2-I2C1.2 (VCC), Q2.2 (D), R6.2, R7.2, R10.2, R24.2, R25.2, R26.2, U1.1 (VDD), U2.31 (~EA/V_{pp}), U2.40 (V_{cc}); also elsewhere on the board

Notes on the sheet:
MountingHoles
GND REF
ISP Bus
7-SEG Driver
Decoupling Capacitors
AT89S51
Toogle Switches
Clock 12MHz
LEDS 5mm
DHT22
Reset Button
Buzzer
LCD 16x2 Display
RPP Output
Keys
[1] - Preciso definir um tamanho padrão de furo para os componentes no layout [2] - Preciso adequar o posicionamento das anotações na camada de silkscreen [4] - Considerar colocar resistor de pull-up nos botões?
LED RGB
Reverse Polarity Protection
P0 is Open Drain

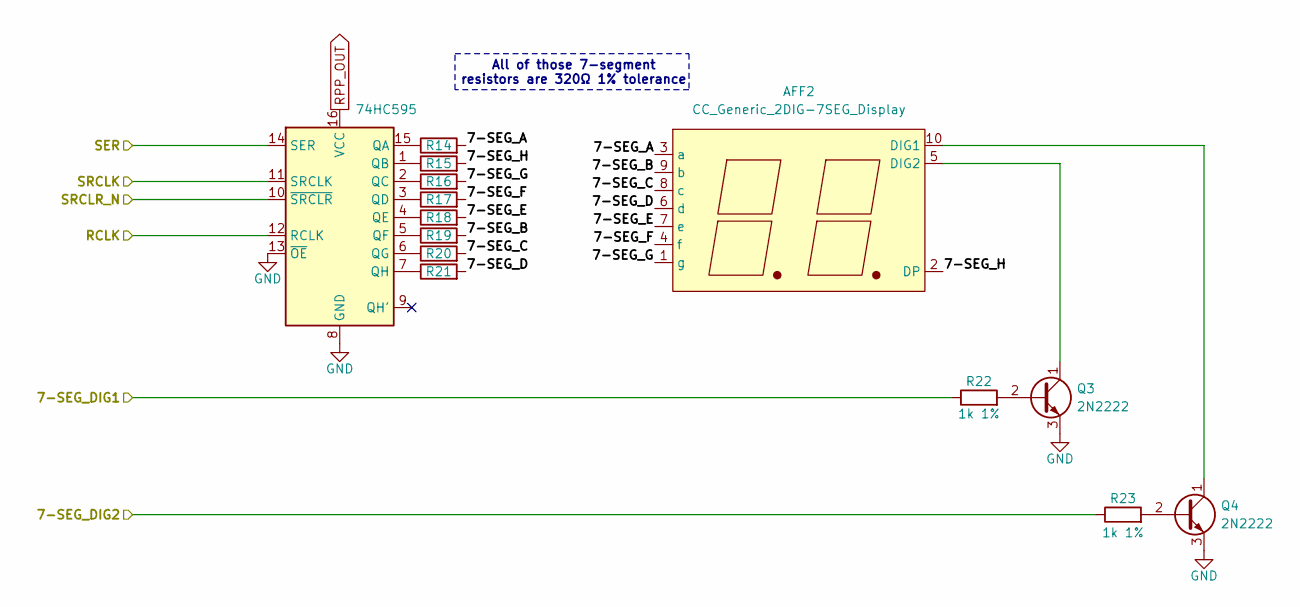
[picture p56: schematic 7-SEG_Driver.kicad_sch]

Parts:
AFF2: CC_Generic_2DIG-7SEG_Display; CC_Generic_2DIG-7SEG
Q3, Q4: 2N2222; 2N2222_TO-92-3_ONS
R14, R15, R16, R17, R18, R19, R20, R21: 330 1%; R_Axial_DIN0207_L6.3mm_D2.5mm_P7.62mm_Horizontal
R22, R23: 1k 1%; R_Axial_DIN0207_L6.3mm_D2.5mm_P7.62mm_Horizontal
U3: 74HC595; DIP-16_W7.62mm

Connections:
/7-SEG_DIG1: R22.1; also elsewhere on the board
/7-SEG_DIG2: R23.1; also elsewhere on the board
/7-SEG_Driver/7-SEG_A: AFF2.3 (a), R14.2
/7-SEG_Driver/7-SEG_B: AFF2.9 (b), R19.2
/7-SEG_Driver/7-SEG_C: AFF2.8 (c), R20.2
/7-SEG_Driver/7-SEG_D: AFF2.6 (d), R21.2
/7-SEG_Driver/7-SEG_E: AFF2.7 (e), R18.2
/7-SEG_Driver/7-SEG_F: AFF2.4 (f), R17.2
/7-SEG_Driver/7-SEG_G: AFF2.1 (g), R16.2
/7-SEG_Driver/7-SEG_H: AFF2.2 (DP), R15.2
/595_RCLK: U3.12 (RCLK); also elsewhere on the board
/595_SER: U3.14 (SER); also elsewhere on the board
/595_SRCLK: U3.11 (SRCLK); also elsewhere on the board
/595_SRCLR_N: U3.10 (~SRCLR); also elsewhere on the board
GND: Q3.3 (E), Q4.3 (E), U3.8 (GND), U3.13 (~OE); also elsewhere on the board
unnamed: AFF2.10 (DIG1), Q4.1 (C)
unnamed: AFF2.5 (DIG2), Q3.1 (C)
unnamed: Q3.2 (B), R22.2
unnamed: Q4.2 (B), R23.2
unnamed: R14.1, U3.15 (QA)
unnamed: R15.1, U3.1 (QB)
unnamed: R16.1, U3.2 (QC)
unnamed: R17.1, U3.3 (QD)
unnamed: R18.1, U3.4 (QE)
unnamed: R19.1, U3.5 (QF)
unnamed: R20.1, U3.6 (QG)
unnamed: R21.1, U3.7 (QH)
RPP_OUT: U3.16 (VCC); also elsewhere on the board

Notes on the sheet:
All of those 7-segment resistors are 320Ω 1% tolerance

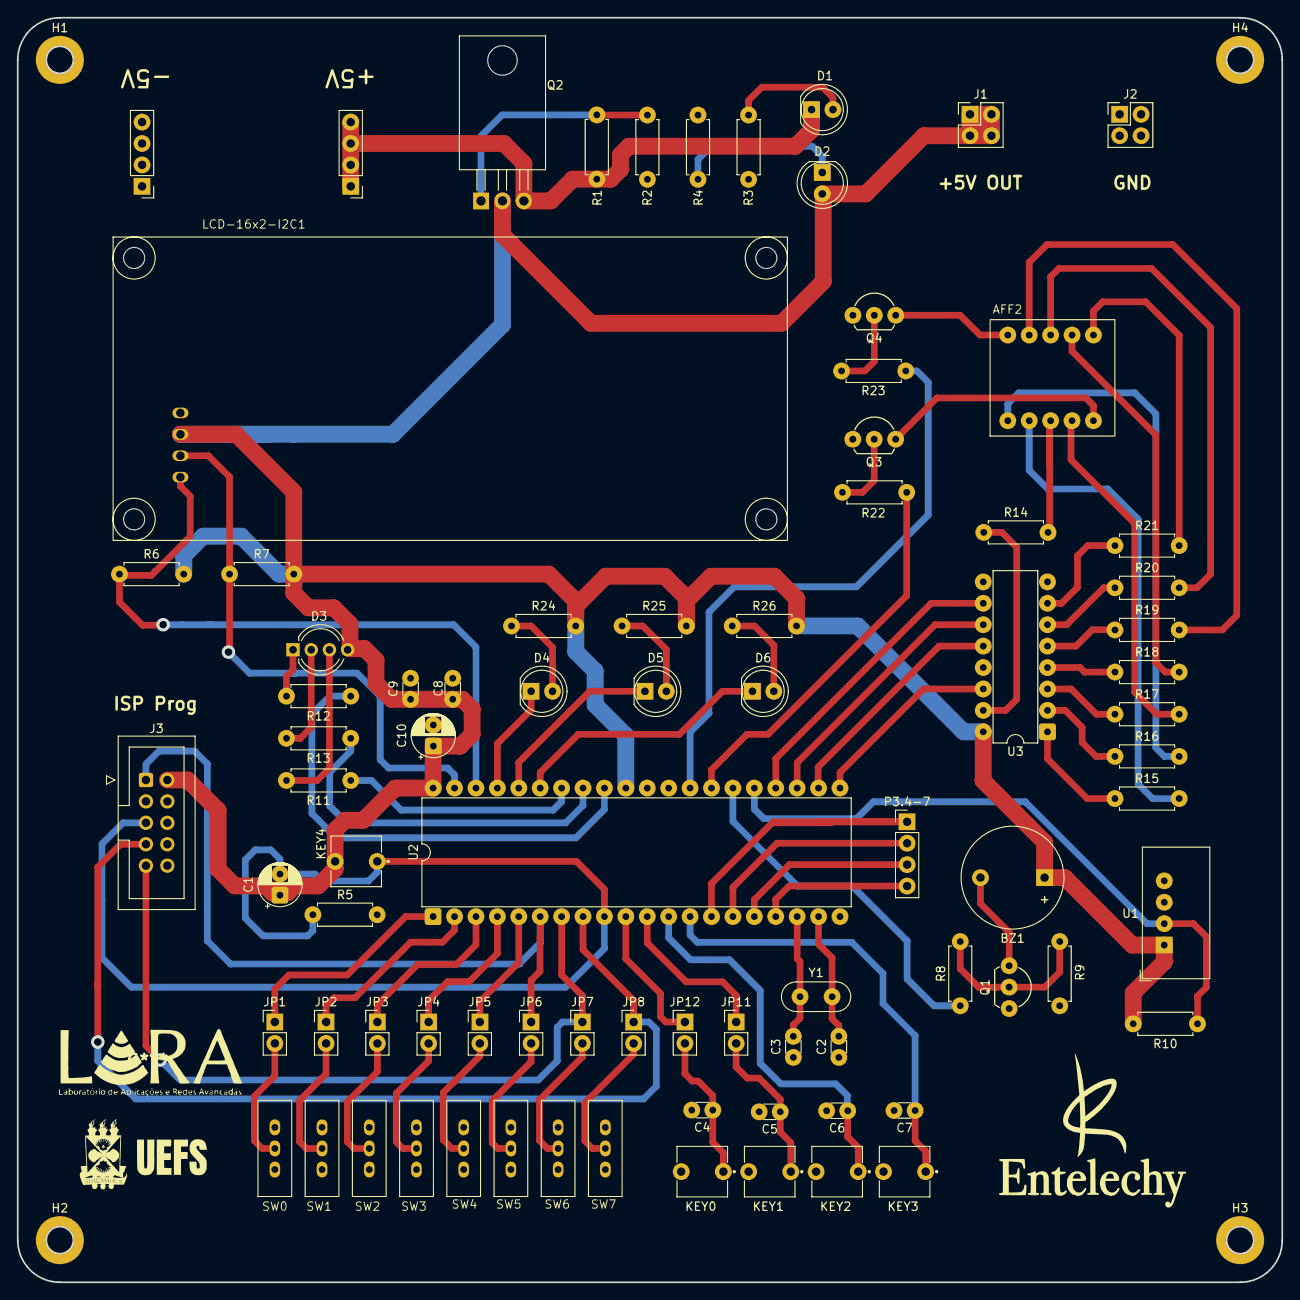
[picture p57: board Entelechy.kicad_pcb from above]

Board: 2 copper layers, 150.0 x 150.0 mm, 86 parts (0 on the bottom side), 79 nets.

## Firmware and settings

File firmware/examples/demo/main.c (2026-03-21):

/*
    AT89S51
    12MHz Crystal
*/

/*
    * Verificar o possível travamento ao habilitar o print da leitura do dht11 no display LCD
    * Verificar se o código do 595 está funcionando conforme visto no pulse view
*/


#include "lcd16x2_i2c.h"
#include <reg51.h>
#include <intrins.h>
#include <stdio.h>


#define T0_RELOAD_HIGH_50MS 0x3C
#define T0_RELOAD_LOW_50MS  0xB0

#define LCD16x2_SLAVE_ADDR 0x4E

#define DELAY_8US() do { \
                        _nop_(); \
                        _nop_(); \
                        _nop_(); \
                        _nop_(); \
                        _nop_(); \
                        _nop_(); \
                    } while(0)

/*
   All arguments shoud be sbit type
*/
#define IS_BUTTON_PRESSED(key) (!(key))
#define IS_SWITCH_ON(sw) (!(sw))
#define TURN_ON_LED(led) ((led) = 0)
#define TURN_OFF_LED(led) ((led) = 1)


#define IS_FOUR_PUSH_BUTTONS_PRESSED()  IS_BUTTON_PRESSED(KEY0) && \
                                        IS_BUTTON_PRESSED(KEY1) && \
                                        IS_BUTTON_PRESSED(KEY2) && \
                                        IS_BUTTON_PRESSED(KEY3)

#define FALSE 0
#define TRUE  1

sbit SW0 = P1^0;
sbit SW1 = P1^1;
sbit SW2 = P1^2;
sbit SW3 = P1^3;
sbit SW4 = P1^4;

sbit KEY0 = P3^0;
sbit KEY1 = P3^1;
sbit KEY2 = P3^2;
sbit KEY3 = P3^3;

sbit LED0 = P0^2;
sbit LED1 = P0^3;
sbit LED2 = P0^4;

sbit LED_RGB_RED   = P0^5;
sbit LED_RGB_GREEN = P0^6;
sbit LED_RGB_BLUE  = P0^7;

sbit HC595_SER     = P2^0;
sbit HC595_RCLK    = P2^1;
sbit HC595_SRCLK   = P2^2;
sbit HC595_SRCLR_N = P2^3;

sbit DHT11_DATA    =  P2^4;

sbit BUZZER_SIG    = P2^5;

sbit DIG1_7SEG     =  P2^6;
sbit DIG2_7SEG     =  P2^7;

bit DHT11_READABLE = FALSE;

volatile unsigned char dht11_data[5] = {0};
volatile char buffer[3];

volatile unsigned char timer0_tick_count = 0;
volatile unsigned char dht11_tick_count  = 0;

// Padrão do símbolo de grau °
unsigned char code degree_char[8] = {
    0x07,  // 0 1 1 1 0
    0x05,  // 0 1 0 1 0
    0x07,  // 0 1 1 1 0
    0x00,  // 0 0 0 0 0
    0x00,  // 0 0 0 0 0
    0x00,  // 0 0 0 0 0
    0x00,  // 0 0 0 0 0
    0x00   // 0 0 0 0 0
};


unsigned char dht11_get_byte() {
    unsigned char i, byte;
    /*unsigned char timeout;
    timeout = 0;*/  
    byte = 0x00;
    for(i = 0; i < 8; i++) {
        while(!DHT11_DATA);
        DELAY_8US();
        DELAY_8US();
        DELAY_8US();
        DELAY_8US();
        DELAY_8US();
        byte <<= 1;
        byte |= DHT11_DATA;
        while(DHT11_DATA);
    }
    return byte;
}


void dht11_get_raw_data() {
    EA = 0;
    // unsigned char t = 0;
    TMOD &= 0x0F; // clear Timer1 bits
    TMOD |= 0x10; // setup 16bit mode
    TF1 = 0; // clear the timer1 overflow flag
    TH1 = 0xB9; // 18ms counting
    TL1 = 0xB0;
    DHT11_DATA = 0;
    TR1 = 1; // enable timer1
    while(!TF1); // waiting for the timer1 overflow
    DHT11_DATA = 1;
    TR1 = 0; // disable timer1
    while(DHT11_DATA); // wait for dht11 response
    while(!DHT11_DATA); // 80us low
    while(DHT11_DATA); // 80us high
    dht11_data[0] = dht11_get_byte(); // relative humidity integer part
    dht11_data[1] = dht11_get_byte(); // relative humidity float part
    dht11_data[2] = dht11_get_byte(); // temperature integer part
    dht11_data[3] = dht11_get_byte(); // temperature float part
    dht11_data[4] = dht11_get_byte(); // checksum
    EA = 1;
}


void timer0_isr(void) interrupt 1 {
    // Setting up timer0 to count 50ms
    TH0 = T0_RELOAD_HIGH_50MS;
    TL0 = T0_RELOAD_LOW_50MS;
    /*
    if (dht11_tick_count > 5) {
        DHT11_READABLE = TRUE;
        dht11_tick_count = 0;
    }*/
    if (timer0_tick_count < 20) {
        DIG1_7SEG = !DIG1_7SEG;
        DIG2_7SEG = !DIG2_7SEG;
        timer0_tick_count++;
    }
    else {
        unsigned char i = 8;
        HC595_SER = ~HC595_SER;
        while(i--) {
            HC595_SRCLK = 1;
            HC595_SRCLK = 0;
        }
        HC595_RCLK = 1;
        HC595_RCLK = 0;

        timer0_tick_count = 0;
        dht11_tick_count++;
    }
}


void timer1_isr(void) interrupt 3 { BUZZER_SIG = !BUZZER_SIG; }

void main(void)
{
    // TMOD: Timer 1 = Mode 2 (8-bit auto), Timer 0 = Mode 1 (16-bit)
    TMOD = 0x21;

    // For 2kHz output (4kHz interrupt) at 12MHz:
    // 1MHz / 4000 = 250. Reload = 256 - 250 = 6.
    TH1 = 0x06;
    TL1 = 0x06; // Initial load
    
    // Setting up timer0 to count 50ms
    TH0 = T0_RELOAD_HIGH_50MS;
    TL0 = T0_RELOAD_LOW_50MS;

    HC595_SER = 0;
    HC595_RCLK = 0;
    HC595_SRCLR_N = 1;

    DIG1_7SEG = 1;
    DIG2_7SEG = 0;

    ET0 = 1; // enable timer0 interrupt
    
    ET1 = 1; // enable timer1 interrupt

    EA = 0; // disable global interruptions
    
    lcd_init(LCD16x2_SLAVE_ADDR);
    
    lcd_send_cmd(0x80, LCD16x2_SLAVE_ADDR); // Linha 1
    lcd_send_str(" < Entelechy >  ", LCD16x2_SLAVE_ADDR);
    
    lcd_send_cmd(0xC0, LCD16x2_SLAVE_ADDR); // Linha 2
    // lcd_send_str("Entelechy | ", LCD16x2_SLAVE_ADDR);
    
    dht11_get_raw_data();
    sprintf(buffer, "%bd", dht11_data[0]);
    lcd_send_str(buffer, LCD16x2_SLAVE_ADDR);
    lcd_send_str("hum e ", LCD16x2_SLAVE_ADDR);
    // lcd_send_str("%  ", LCD16x2_SLAVE_ADDR);
    sprintf(buffer, "%bd", dht11_data[2]);
    lcd_send_str(buffer, LCD16x2_SLAVE_ADDR);
    lcd_send_str("deg", LCD16x2_SLAVE_ADDR);
    
    EA = 1; // enable global interrupt
    TR0 = 1; //timer0 run
    TR1 = 1; // timer1 run

    P3 = 0xFF;
    P1 = 0x0F; // 0 parte baixa e f a parte alta
    P0 &= 0xFF;

    // polling for toggle switches and keys
    /*
        SW0 - Turn on the LED0
        SW1 - Turn on the LED1
        SW2 - Turn on the LED2
        SW3 - Turn on the Green RGB LED
        SW4 - Turn on All the Lights RGB LED
        
        Push the 4 buttons at the same time turn off all the lights
        
    */
    while(1) {
        if(IS_BUTTON_PRESSED(KEY1)) { TURN_ON_LED(LED0); }
        else { TURN_OFF_LED(LED0); }

        if(IS_BUTTON_PRESSED(KEY0)) { TURN_ON_LED(LED1); }
        else { TURN_OFF_LED(LED1); }
        
        if(IS_BUTTON_PRESSED(KEY2)) { TURN_ON_LED(LED2); }
        else { TURN_OFF_LED(LED2); }
        
        if(IS_BUTTON_PRESSED(KEY3)) { TURN_ON_LED(LED_RGB_BLUE); }
        else { TURN_OFF_LED(LED_RGB_BLUE); }
        
        if(IS_SWITCH_ON(SW0)) { TURN_ON_LED(LED_RGB_RED); }
        else { TURN_OFF_LED(LED_RGB_RED); }
        
        if(IS_SWITCH_ON(SW1)) { TURN_ON_LED(LED_RGB_GREEN); }
        else { TURN_OFF_LED(LED_RGB_GREEN); }
        /*
        if(IS_SWITCH_ON(SW1)) TURN_ON_LED(LED1);
        else TURN_OFF_LED(LED1);

        if(IS_SWITCH_ON(SW2)) TURN_ON_LED(LED2);
        else TURN_OFF_LED(LED2);

        if(IS_SWITCH_ON(SW3)) TURN_ON_LED(LED_RGB_GREEN);
        else TURN_OFF_LED(LED_RGB_GREEN);
        
        if(IS_SWITCH_ON(SW4)) {
            TURN_ON_LED(LED_RGB_RED);
            TURN_ON_LED(LED_RGB_GREEN);
            TURN_ON_LED(LED_RGB_BLUE);
        }
        
        if(IS_FOUR_PUSH_BUTTONS_PRESSED()) {
            TURN_OFF_LED(LED0);
            TURN_OFF_LED(LED1);
            TURN_OFF_LED(LED2);
            TURN_OFF_LED(LED_RGB_RED);
            TURN_OFF_LED(LED_RGB_GREEN);
            TURN_OFF_LED(LED_RGB_BLUE);
        }*/
    } // END WHILE
} // END main

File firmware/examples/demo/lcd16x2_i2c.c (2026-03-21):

#include "lcd16x2_i2c.h"

void i2c_start(void)
{
    LCD16x2_SDA = 1;
    _nop_(); _nop_();
    LCD16x2_SCL = 1;
    _nop_(); _nop_();
    LCD16x2_SDA = 0;
    _nop_(); _nop_();
}

void i2c_stop(void)
{
    LCD16x2_SCL = 0;
    LCD16x2_SDA = 0;
    LCD16x2_SCL = 1;
    LCD16x2_SDA = 1;
}

void i2c_ACK(void)
{
    LCD16x2_SCL = 0;
    LCD16x2_SDA = 1;
    LCD16x2_SCL = 1;
    while(LCD16x2_SDA); // Aguarda o escravo puxar LCD16x2_SDA para baixo (ACK)
}

void i2c_write(unsigned char dat)
{
    unsigned char i;
    for(i = 0; i < 8; i++)
    {
        LCD16x2_SCL = 0;
        // Verifica bit a bit, do MSB para o LSB
        LCD16x2_SDA = (dat & (0x80 >> i)) ? 1 : 0;
        LCD16x2_SCL = 1;
    }
}

void lcd_send_cmd(unsigned char cmd, unsigned char lcd_addr)
{
    unsigned char cmd_l, cmd_u;
    cmd_l = (cmd << 4) & 0xf0;
    cmd_u = (cmd & 0xf0);

    i2c_start();            
    i2c_write(lcd_addr);
    i2c_ACK();
    
    // Envia parte alta (Upper nibble)
    i2c_write(cmd_u | 0x0C); // BL EN RW RS -> 1 1 0 0
    i2c_ACK();
    delay_ms(1);
    i2c_write(cmd_u | 0x08); // Pulse Enable: 1 0 0 0
    i2c_ACK();
    delay_ms(10);
    
    // Envia parte baixa (Lower nibble)
    i2c_write(cmd_l | 0x0C); // 1 1 0 0
    i2c_ACK();
    delay_ms(1);
    i2c_write(cmd_l | 0x08);
    i2c_ACK();
    delay_ms(10);
    
    i2c_stop();
}

void lcd_send_data(unsigned char dataw, unsigned char lcd_addr)
{
    unsigned char dataw_l, dataw_u;
    dataw_l = (dataw << 4) & 0xf0;
    dataw_u = (dataw & 0xf0);

    i2c_start();
    i2c_write(lcd_addr);
    i2c_ACK();
    
    // Envia parte alta
    i2c_write(dataw_u | 0x0D); // BL EN RW RS -> 1 1 0 1
    i2c_ACK();
    delay_ms(1);
    i2c_write(dataw_u | 0x09); // 1 0 0 1
    i2c_ACK();
    delay_ms(10);
    
    // Envia parte baixa
    i2c_write(dataw_l | 0x0D);
    i2c_ACK();
    delay_ms(1);
    i2c_write(dataw_l | 0x09);
    i2c_ACK();
    delay_ms(10);
    
    i2c_stop();
}

void lcd_send_str(unsigned char *p, unsigned char lcd_addr)
{
    while(*p != '\0')
    {
        lcd_send_data(*p++, lcd_addr);
    }
}

void delay_ms(unsigned char n)
{
    unsigned char m;
    for(; n > 0; n--)
    {
        for(m = 121; m > 0; m--);
        _nop_(); _nop_();
        _nop_(); _nop_();
        _nop_(); _nop_();
    }
}

void lcd_init(unsigned char lcd_addr)
{
    lcd_send_cmd(0x02, lcd_addr); // Return home
    lcd_send_cmd(0x28, lcd_addr); // 4 bit mode
    lcd_send_cmd(0x0C, lcd_addr); // Display On, cursor off
    lcd_send_cmd(0x06, lcd_addr); // Increment Cursor (shift cursor to right)
    lcd_send_cmd(0x01, lcd_addr); // Clear display
}

void lcd_clear_display(unsigned char lcd_addr) {
    lcd_send_cmd(0x01, lcd_addr);
}


// Carrega um caractere customizado na CGRAM
// slot: posição 0 a 7
// pattern: array de 8 bytes (linhas do caractere)
void lcd_create_char(unsigned char slot, unsigned char code *pattern, unsigned char lcd_addr)
{
    unsigned char i;
    // Endereço da CGRAM = 0x40 | (slot * 8)
    lcd_send_cmd(0x40 | (slot << 3), lcd_addr);
    for(i = 0; i < 8; i++)
    {
        lcd_send_data(pattern[i], lcd_addr);
    }
}

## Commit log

2026-03-21 chore: cleanup unnecessary files and update workspace
    [555tc.DSN, 7zDP_LZMA.cfg, CFT.DSN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]
2026-08-29 Add a real circuit video
